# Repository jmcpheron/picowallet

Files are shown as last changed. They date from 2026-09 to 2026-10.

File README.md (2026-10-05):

# picowallet

A hardware wallet for one stablecoin, built from three off-the-shelf parts in an evening, no
soldering. It shows your balance in dollars. When a website asks it to send money, it puts the
amount and the recipient on its own screen and does nothing until you press the green button.

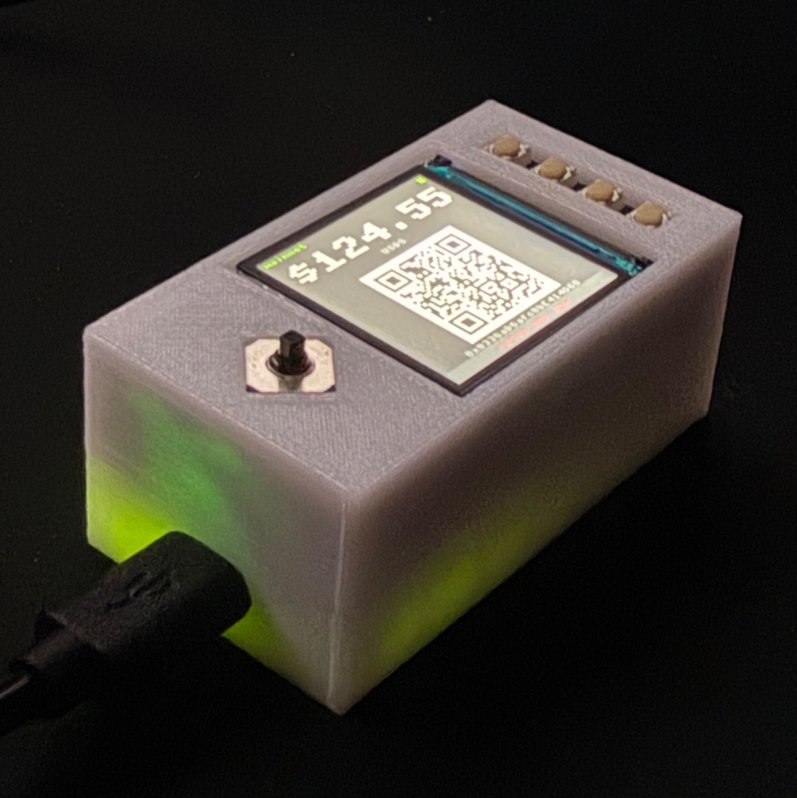
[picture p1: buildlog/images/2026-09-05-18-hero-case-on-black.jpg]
picowallet


The main flow is deliberately narrow: one token (USDS), one vault contract, one key that lives in
a secure element and never leaves it. An advanced hardware-signed call can recover other assets or
interact with contracts. Fork it, swap the token, redraw the screens, print a different case.

On 2026-09-05 it sent 69 USDS to atg.eth on Ethereum mainnet:
[`0x87638ae1…`](https://etherscan.io/tx/0x87638ae169eccb9f002d4eb6ce8b60e7d6603e4d3d4e562164ea10e9023f9313).

> **Security notice:** that historical deployment is legacy authorization v1 with a mutable signer.
> Do not fund or copy it. Current source is authorization v5; read [`SECURITY.md`](SECURITY.md) before use.

## Current contract

Authorization v5 is deployed on Ethereum mainnet at
[`0x4564fA634b073AcBcA814DCA5210835EC9376324`](https://etherscan.io/address/0x4564fA634b073AcBcA814DCA5210835EC9376324).

- No admin, upgrade, or unsigned spending path.
- Hardware-signed USDS transfers and arbitrary contract calls.
- ETH and accidental-token recovery through signed calls.
- Hardware-signed ENS reverse-name setup.
- Fixed recovery wallet with a 14-day signer-change delay. Any valid current-chip action cancels it.

**Audit:** [One Dollar Audit engagement 850](https://www.onedollaraudit.com/audit/850) reviewed this
exact deployment on 2026-09-06. [Full report](https://bafkreiha7yyl727uubma4shj2f5z5mlnezuya7wqg7yzqkjaqr443k4eg4.ipfs.community.bgipfs.com/):
3 high, 3 medium, 4 low, 3 informational. Its main warnings are known trade-offs: a compromised chip
can keep cancelling recovery, approvals can outlive signer recovery, and the fixed recovery wallet
is a single point of failure. This is a PoC, not an audit guarantee.

## How it works

```
website ──"send $5 to atg.eth"──▶ app (queue + relay, runs on your laptop)
                                     │  the wallet polls over WiFi
                                     ▼
                              picowallet
                              rebuilds the EIP-712 digest from the fields it shows you
                              screen:  SIGN  $5 USDS to atg.eth  REJECT
                              ATECC608 signs the digest (P-256), key never leaves the chip
                                     │  (r, s)
                                     ▼
                         relay pays gas ──▶ ChipAccount.executeTransfer ──▶ USDS.transfer
```

- The key is generated inside an **ATECC608** secure element and cannot be read out.
- On chain, a small vault contract (`ChipAccount`) holds the stablecoin and moves it only with a
  valid P-256 signature from the current hardware key, over a digest that
  includes recipient, amount, nonce, deadline, chain and contract. There is no admin or upgrade.
  A fixed recovery wallet can rotate the signer only after an uninterrupted 14-day delay.
- The wallet **rebuilds the digest itself** from the security-critical raw fields and refuses a
  mismatch. Names, symbols, and formatted values are untrusted display hints; production forks must
  pin the chain/vault/token and use authenticated transport as described in `SECURITY.md`.
- The relay just pays gas. It has no contract privilege and cannot replace the signer.
- Chip-signed general execution can recover accidental tokens/ETH and interact with contracts.
  The signature covers the exact target, ETH value, calldata, nonce, deadline, chain, and wallet.
  This is powerful: approve unknown calls only after decoding every field.

## 1. Order the parts

| part | ~price | link |
|---|---|---|
| Raspberry Pi Pico 2 W, **pre-soldered header** | $12 | Amazon `B0DRJXPPWL` (Freenove) or any Pico 2 W with headers |
| Waveshare Pico-LCD-1.3 (240×240 IPS, joystick, A/B/X/Y) | $15 | Amazon `B092VVCBQP` |
| Adafruit ATECC608 breakout, STEMMA QT | $6 | Adafruit 4314 |
| STEMMA QT / JST-SH 4-pin cable, any ends | $1 to $8 | Amazon `B08HQ1VSVL` (the kit we used, several ends), or single: Adafruit 4209 ($0.95, snip the pins off and strip) |
| micro-USB cable, data not charge-only | | |

About $35. No soldering iron.

Next hardware (in progress, needs soldering): the key moves into a plug-in McGuffin, with a bigger
screen, a dial and an 18650. See [`hardware/MCGUFFIN.md`](hardware/MCGUFFIN.md), and
[`hardware/BUILD1.md`](hardware/BUILD1.md) for the first build with a wiring diagram.

## 2. Print the case

`case/waveshare-13-pico-lcd-case-tomas-plass.stl`: both halves in one file, PLA, 0.2 mm layers,
no supports. Snaps together, micro-USB slot on the end, screen window, the four buttons and the
joystick poke through. Keycaps and a joystick dome are in `case/out/` (PLA, 0.12 mm layers).
`case/gen.py` regenerates them if your parts differ.

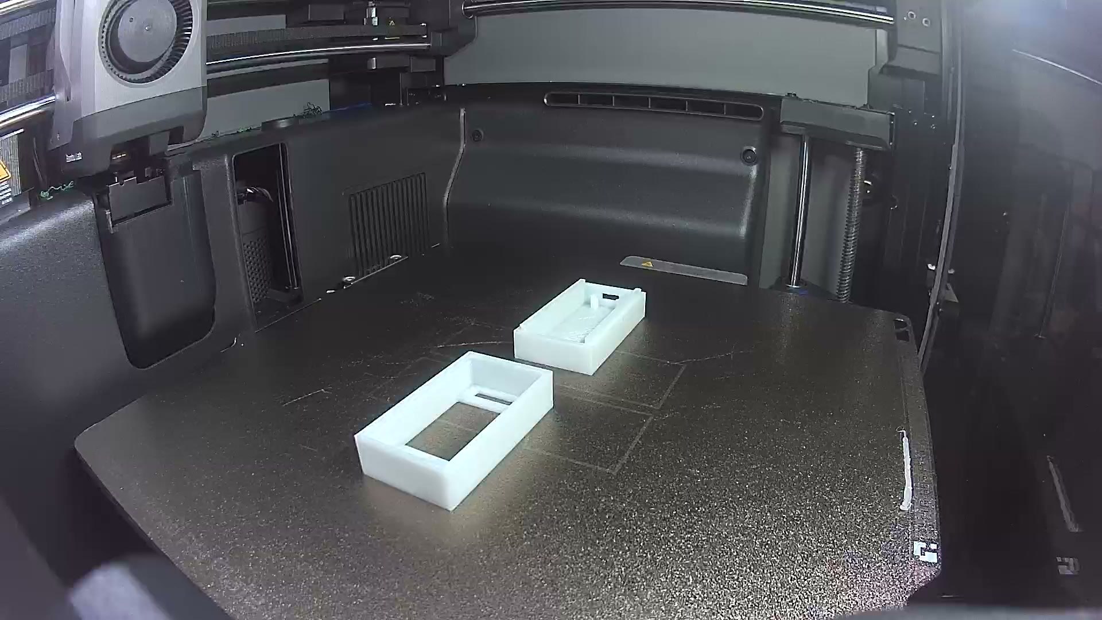
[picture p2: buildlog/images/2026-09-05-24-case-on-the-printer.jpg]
both halves on the printer


## 3. Put it together

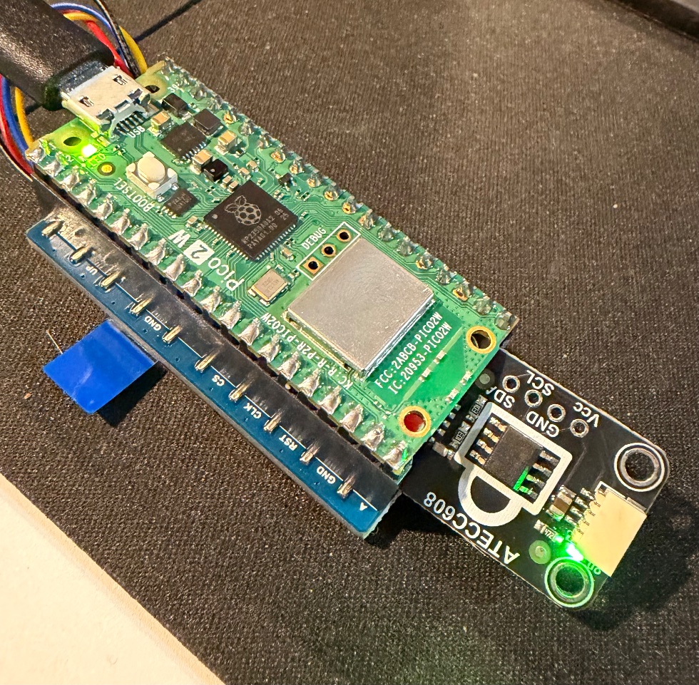
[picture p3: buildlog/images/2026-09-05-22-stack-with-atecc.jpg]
the stack: Pico on the LCD board, ATECC breakout in the gap


1. Plug the Pico into the LCD board's female header, component side toward the LCD, USB at the
   joystick end.
2. Plug the STEMMA QT cable into the ATECC breakout.
3. Push the cable's four bare wires into the LCD board's header socket **beside** the Pico pins.
   The spring contact grips both. Counting from the USB end, right side: red into 3V3 (pin 36),
   black into GND (pin 38). Left side: blue into GP4 (pin 6), yellow into GP5 (pin 7). Tug lightly.
4. Jam the breakout into the gap between the two boards, wires flat.

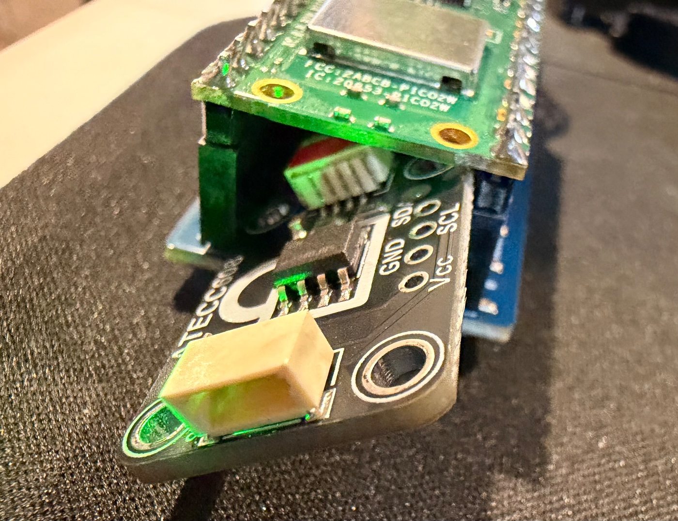
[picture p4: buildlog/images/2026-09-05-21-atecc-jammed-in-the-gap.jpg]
ATECC608 breakout jammed in the gap


`SOLDERING.md` has the pinout diagram and the soldered version if you want it permanent.

## 4. Flash the firmware

1. Hold BOOTSEL on the Pico, plug it into a computer, release. A drive named `RP2350` appears.
2. Drag [MicroPython for the Pico 2 W](https://micropython.org/download/RPI_PICO2_W/) (`.uf2`)
   onto it. The drive disappears and the board reboots.
3. On the computer: `uv tool install mpremote` (or `pip install mpremote`).
4. Copy `firmware/secrets.example.py` to `firmware/secrets.py`. Put in your WiFi and the app URL
   (step 6 gives you that, `http://<your-laptop-lan-ip>:3001`).
5. First time, over USB: `./tools/mpy` (needs `uv tool install mpy-cross==1.26.1.post2`), then
   `mpremote cp firmware/*.py firmware/*.mpy firmware/*.bin : + rm :splash.py + rm :lcd.py + rm :loader.py + reset`.
   That is the firmware plus the boot logo and loading bar; the three bootloader modules go as
   pre-compiled `.mpy` (a `.py` of the same name on the board would be used instead).

The passwordless WiFi console is disabled by default because it grants full control of the signer.
For isolated development only, set `ENABLE_NETWORK_CONSOLE = True`; then `./tools/push` deploys
firmware over the air and `./tools/pico` opens the console. Disable it before holding real value.

The screen comes up, finds the chip on the bus, and shows "no key" until step 5.

## 5. Set up the chip (once)

A fresh ATECC608 refuses to make a key until its config zone is locked, once, permanently. **Before
locking any chip run `python3 tools/check_config`** (proves the firmware's config table is the one on
the working chip) and know that the firmware reads the chip back and refuses to lock on any
mismatch; a chip was lost on 2026-09-15 before those checks existed (`buildlog/2026-09-15-config-table-bug.md`). This
is normal; every chip in use is locked. Generate the final key before deploying the contract:

1. In `firmware/secrets.py` temporarily set `ALLOW_LOCK = True` and `ALLOW_GENKEY = True`.
2. Over USB, lock the config zone and generate the key. Record the public `qx` and `qy` values.
3. Set both flags back to `False`, leave `ENABLE_NETWORK_CONSOLE = False`, and flash again.
4. Put `qx` and `qy` in `app/packages/foundry/.env`, set a fixed `RECOVERY_ADDRESS`, and deploy.
   Losing the chip starts the documented 14-day recovery process.

`reference/pi/README.md` shows the equivalent provisioning flow from a Raspberry Pi with real output.

## 6. Run the app

`app/` is a Scaffold-ETH 2 project: the vault contract, a Next.js site, and the queue and relay as
route handlers. Locally, with play money:

```sh
cd app && yarn install
yarn chain                                  # anvil, a local chain
yarn deploy                                 # requires CHIP_PUBKEY_X/Y in packages/foundry/.env
yarn workspace @se-2/nextjs dev -p 3001     # http://localhost:3001
```

The wallet announces its key to the app. `/setup` verifies that it matches the current on-chain
key. The screen shows the vault balance and a QR of the vault address. Type a recipient and an
amount on the Send page. The wallet turns green. Press A. Watch it settle.

Mainnet, with real money, in `app/packages/nextjs/.env.local`:

```
NEXT_PUBLIC_TARGET_NETWORK=mainnet
NEXT_PUBLIC_ALCHEMY_API_KEY=<a restricted project-specific key>
RELAYER_KEYSTORE=<a foundry keystore name>          # an account with a little ETH for gas
RELAYER_KEYSTORE_PASSWORD_FILE=/path/to/password.txt
USDS_ADDRESS=0xdC035D45d973E3EC169d2276DDab16f1e407384F
```

Deploy your own vault with the chip's public key baked in (the Setup page shows it):

```sh
# app/packages/foundry/.env: CHIP_PUBKEY_X/Y=0x… USDS_ADDRESS=0x… ENS_REVERSE_REGISTRAR=0x…
cd app && yarn deploy --network mainnet --keystore <name>
```

Send USDS to the vault address it prints. Scan the QR on the wallet to get that address into
your phone wallet. Each transfer costs the relay about 82k gas.

For ENS, first create a subname such as `hard.atg.eth` and make its ETH record point to the vault.
Then use **Set the vault ENS name** in the app and approve the exact name on the device. This sets
reverse/primary resolution only; it does not create the subname.

Recovery uses the fixed `RECOVERY_ADDRESS` chosen at deployment. That wallet proposes a new P-256
key, waits 14 days, then finalizes. Any successful current-chip action cancels the proposal; the app
also has **Cancel on Pico**. Monitor `RecoveryStarted` events. See `SECURITY.md` before funding.

## The screens

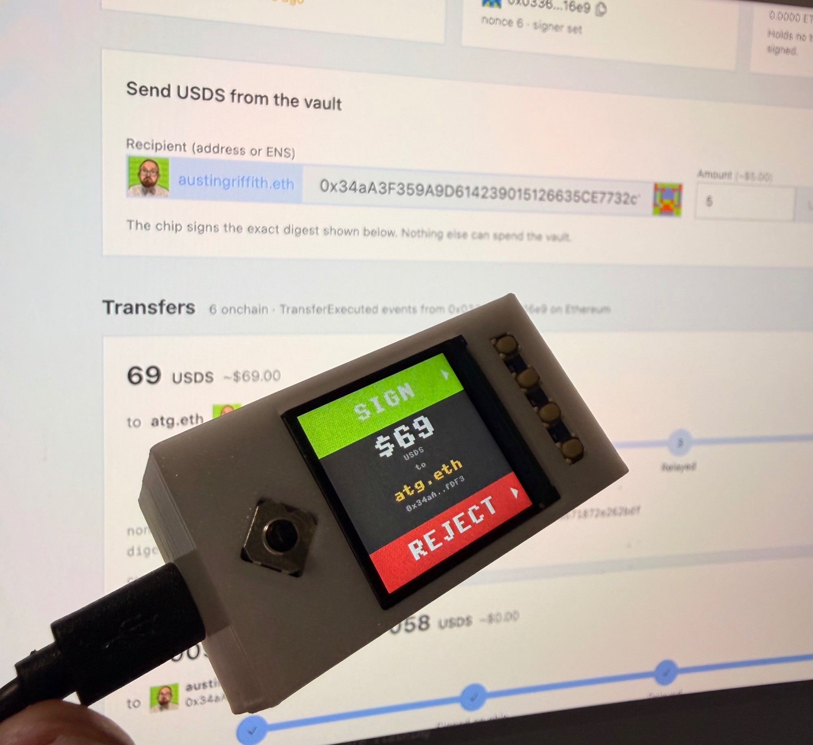
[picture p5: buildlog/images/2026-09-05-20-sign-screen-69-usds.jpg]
SIGN? $69 USDS to atg.eth, green bar at A, red bar at Y


**Home:** balance in dollars, a QR of the vault to deposit into, chain label top-left so test money
and real money never look alike, pairing dot top-right, a warning line along the bottom (relay
gas low, unpaired, app unreachable). Refreshes every 12 s and flashes the delta when money moves.

**Sign:** green SIGN bar in line with the A button, red REJECT bar in line with Y. Amount,
recipient name and address between them. Joystick down shows nonce, deadline, chain, vault and the
digest the device computed.

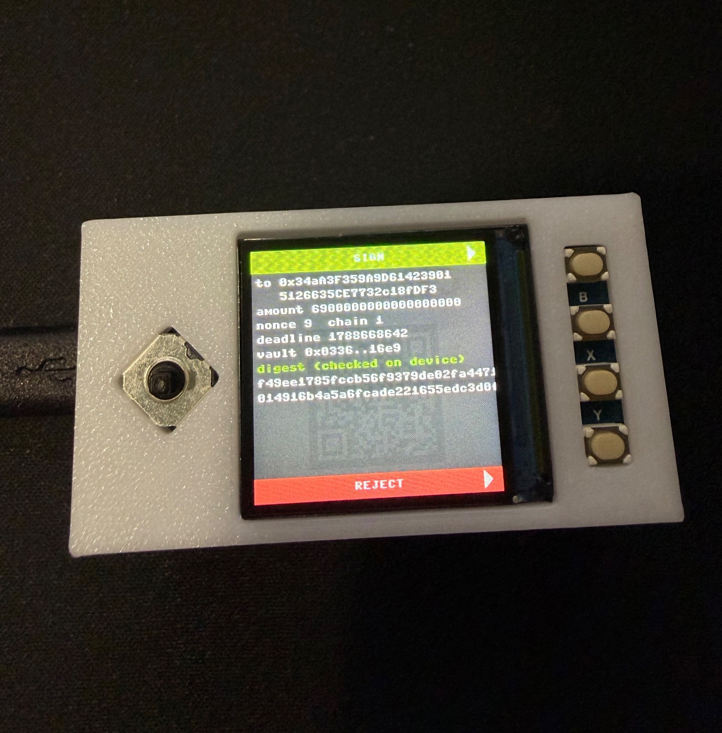
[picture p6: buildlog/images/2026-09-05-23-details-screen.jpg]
details page: full address, amount in base units, nonce, deadline, vault, digest


## Change it

- **Another token:** set `USDS_ADDRESS` before deploying. The token address is immutable, so changing
  assets requires a new vault.
- **Another chain:** `targetNetworks` in `app/packages/nextjs/scaffold.config.ts`. The wallet
  shows the chain id it is told and bakes it into the digest.
- **The screens:** `firmware/wallet.py`, functions `draw_home` and `draw_confirm`. 240×240,
  framebuf, an 8×8 font scaled up. Try it on the virtual wallet first: `tools/emu` opens
  http://localhost:4242 with the same MicroPython running the same files, the case in 3D and
  the keyboard on the buttons (W A S D, space, numpad 9 6 3 .); `tools/emu run NAME`, `key A`, `shot` drive it from a terminal
  (`emu/README.md`). To have an AI write for it, give it `emu/SKILL.md` and this repo; in Claude
  Code it is the `/pico-emu` skill. Then `./tools/push` and look.
- **The case:** `case/gen.py`, CadQuery, every dimension is a named number at the top.
- **The contract:** `app/packages/foundry/contracts/ChipAccount.sol`, with 34 tests.

## What is where

| path | what |
|---|---|
| `firmware/` | MicroPython for the Pico: `wallet.py` loop and screens (WiFi), `usbwallet.py` (USB, no radio, see `USB.md`), `atecc.py` chip driver, `signer.py`, `eip712.py` + `keccak.py` + `p256.py` pure-Python crypto, `blockies.py`, `lcd.py`, `net.py` |
| `app/` | contracts, tests, site, relay |
| `case/` | STLs, the generator, the measurements |
| `emu/` | the virtual wallet: MicroPython in WebAssembly, `machine` shims, the case STLs in 3D, a CLI for bots |
| `tools/` | `pico` console, `push` firmware, `qr` (QR of the vault for the screen), `emu` (the virtual wallet) |
| `buildlog/` | dated notes and photos of what actually happened, including the mistakes |
| `reference/` | the Pi signer this grew out of, with the fresh-chip guide; SeedSigner cap parts (MIT) |
| `PLAN.md`, `SOLDERING.md`, `USB.md` | the plan, the wiring guide, and the wallet over USB (air-gapped, no radio) |

## Trust model, short

The current chip key is the only thing that can spend the vault. The delayed recovery wallet can
replace that key but cannot spend directly. The relay only pays gas. The app
has no auth, so anyone who can reach it can queue deceptive requests or cause denial of service;
keep it on a trusted network for this PoC. The passwordless development console must stay disabled
when holding value. Read [`SECURITY.md`](SECURITY.md) before funding a deployment or publishing the
app to the internet.

## Credits

Grew out of [ATECC608-demo](https://github.com/clawdbotatg/ATECC608-demo) (a Pi doing the same
job). Case v0 by [Tomáš Plass](https://www.printables.com/model/1322102-waveshare-pico-13-lcd-case),
CC BY-NC. Cap and joystick geometry learned from the
[SeedSigner](https://github.com/SeedSigner/seedsigner) enclosures, MIT. App scaffold by
[Scaffold-ETH 2](https://scaffoldeth.io).

## License

MIT for everything here except where noted: the v0 case STL is Tomáš Plass's, CC BY-NC 4.0;
the SeedSigner parts in `reference/seedsigner/` are MIT with their own copyright; `app/` carries
Scaffold-ETH 2's MIT license.

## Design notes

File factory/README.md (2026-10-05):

# Factory test

Run `tools/factory`, open http://localhost:4343 in Chrome or Edge, plug in a finished wallet, press
Connect (first board only; after that it starts by itself on plug-in).

It checks, in order:
1. Board: Pico 2 W / Pico W / RP2040 clone, board ID, WiFi, RAM, whether the wallet firmware is on it.
2. Secure chip on GP4/GP5: ATECC608 (serial, lock state) or OPTIGA Trust M (UID). If none answers it
   says which wires to check.
3. Screen: red, green, blue; you confirm each on the page.
4. Buttons: press all nine; each turns green on the page and on the wallet.

Needs only MicroPython on the board: `probe.py` is pasted into the raw REPL, nothing is written
to flash. At the end the board soft-resets and the wallet starts again. Results stay in this
browser's list; "Download CSV" exports them.

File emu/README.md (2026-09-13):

# emu: the virtual Pico wallet

Real MicroPython (the WebAssembly build of 1.26, the board runs 1.26.1) running the firmware in
`firmware/` unchanged, with the `machine`/`network`/`requests` modules replaced by shims that talk
to the page. The screen is captured from the ST7789 SPI stream, so what you see is the exact
framebuffer. The device is drawn in 3D from the case STLs in `case/zez0000/`.

```
tools/emu                 # start the server, open http://localhost:4242
tools/emu run hello       # reboot + import emu/sketches/hello.py
tools/emu key A           # press a button (A B X Y up down left right press), key right:300 holds
tools/emu shot            # emu/shots/latest.png
tools/emu exec 'mock.goto("send")'
tools/emu log             # console lines
tools/emu devices         # boards on USB (serial ports, bootloader drives)
tools/emu ship hello      # copy hello.py (+ imports) to the Pico on USB and run it (--port /dev/cu.usbmodemN, --boot: run at power-up too)
tools/emu flash --port /dev/cu.usbmodemN [--wifi]   # MicroPython onto any board (also works on a BOOTSEL drive without --port)
tools/emu headless mock --wait 300 --key right --shot emu/shots/x.png    # no browser
```

Page: the device menu lists every board on USB; for one that is not running MicroPython the
send button becomes ⚡ install MicroPython. The module menu top left picks what ▶ run, ↻ reset and
⇪ send to Pico act on (only modules
that show something are listed: they start themselves at import, or the server knows their entry
point, `ENTRY` in `core/workspace.mjs`). Left = files, editor (Cmd/Ctrl+Enter runs the open file),
console with a REPL; right = the device (orbit with the mouse, click the caps) or the flat view.
Keyboard: W A S D and space for the joystick, numpad 9 6 3 . for A B X Y (top-row 9 6 3 . work
too), after clicking the device. The 3D view labels each button with its key.

The flash is `firmware/*.py` and `*.bin` (never `secrets.py`; a stub is generated with
`APP_URL = "/app"`, which the server proxies to the wallet app, `--app http://host:port`,
default `http://localhost:3001`) plus `emu/sketches/*` on top. Saving in the editor writes to disk.

## Give it to your AI

`emu/SKILL.md` is the skill file. It tells an AI what the screen and buttons are, how to write a
sketch, how to run it here (`tools/emu run`, `key`, `shot`), and how to put it on the real Pico.
Hand it over with a checkout of this repo (the skill runs `tools/emu`, which needs node). In
Claude Code it loads on its own from `.claude/skills/pico-emu`; say "build Tetris for the Pico
wallet" or `/pico-emu`. The page links to it too (top right, "skill file for your AI", also at
http://localhost:4242/skill).

What is modeled: pins (keys pull low when pressed), SPI display window commands, the SPI transfer
time (24 MHz cap until `machine.freq(cpu, peri)` raises the peripheral clock, like rp2), PWM
backlight, `Pin("LED")` (the base glows), `Timer` periodic/one-shot, `Pin.irq`, `machine.reset()`,
a 448 KB heap. Not modeled: I2C (the ATECC608 is absent, the software signer is used), sockets,
PIO, native/viper code generation (runs as bytecode), real timing of Python itself (wasm is much
faster than the RP2350).

Needs node 18+ and `npm install` in `emu/` (done by `tools/emu` on first run). No build step.

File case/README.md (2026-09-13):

# Case

## v0: print this first

`waveshare-13-pico-lcd-case-tomas-plass.stl`, from
[Waveshare Pico 1.3 LCD Case by Tomáš Plass](https://www.printables.com/model/1322102-waveshare-pico-13-lcd-case)
on Printables. License CC BY-NC 4.0 (remix ok, attribution required, no commercial use).

What it is: a two-piece snap-fit box for exactly our stack, Pico plugged into the Pico-LCD-1.3.
Both halves are in the one STL, side by side. Closed box about 60 x 34 x 26 mm.

- Lid: screen window, a slot the four bare A/B/X/Y buttons poke through, a diamond hole the
  joystick stem pokes through. No caps, you press the parts directly. That is the honest state of
  the art for this board: nobody has published floating caps for it.
- End: micro-USB slot (the Pico 2 W is micro-USB, not USB-C).
- Base: four M2 posts for the Pico, optional.
- Print: 0.2 mm layers, no supports (author says a small one under the USB cutout is optional).

Fit risk for us: the ATECC breakout and the four wedged wires live in the 11 mm gap between the
boards, inside the box footprint, so they should be fine. The wires leave the header at the USB end
and bend into the gap; keep them flat. Print it and see.

## v1: our own

Generate from Python (like the CELL parts) so it re-fits when parts change. Wants:
- floating caps for A/B/X/Y and a joystick hat, captured by the lid
- pocket for the ATECC breakout and a 502030 LiPo + charger
- USB cutout, maybe a lanyard hole

Board facts for that: Pico-LCD-1.3 is 52.0 x 26.5 mm, display 23.4 x 23.4 mm active. Waveshare
wiki: https://www.waveshare.com/wiki/Pico-LCD-1.3. A CAD model of the board exists on GrabCAD:
https://grabcad.com/library/waveshare-1-3-inch-lcd-for-pico-65k-240x240-1. Button and joystick
centers still need measuring with calipers.

Print inbox drop 2026-09-05: `20260905-193939-waveshare-13-pico-lcd-case-tomas-plass` (PLA, black, 0.20 mm).

## Buttons and joystick: research (2026-09-05)

Nobody has published caps for the Pico-LCD-1.3. But its Pi HAT twin (Waveshare 1.3inch LCD HAT,
same 240x240 panel, same 5-way joystick, same tact switches, 3 buttons instead of 4) is the
SeedSigner bitcoin wallet's screen, and that project has years of open enclosures with printed caps:

- SeedSigner enclosures, MIT: https://github.com/SeedSigner/seedsigner/tree/dev/enclosures
  Copies of the parts that matter are in `reference/seedsigner/`:
  - `orange_pill_button.stl` 11.7 x 4.7 x 4.8 mm, `orange_pill_joystick.stl` 13 x 13 x 10 mm.
    Author says the thumbstick is clumsy and wants resin.
  - `open_pill_mini_w_coverplate_Buttons.stl` (three caps on a sprue, 20 mm tall), `Thumbstick_PLA`
    and `Thumbstick_TPU` (11.8 x 11.8 x 5.6 mm). FDM-only, TPU for the controls, no hardware.
- revetuzo's Open Pill caps, CC BY-SA: https://www.printables.com/model/179924
  Sticks and pads in 12/14/15 mm with a 2.05 mm square socket, "fits the 2 mm stick on the
  Waveshare HAT". Plus a glue-on button.
- Crackedconsole's HAT case with 3 buttons + joystick cap v2, Sketchup source:
  https://www.thingiverse.com/thing:3334127. Note: 0.1 mm more clearance per button was too loose.
- Adafruit 4697 rubber nubbin cap, $0.50, fits the classic 5-way nav stem. Zero-effort option.
- The joystick family: ALPS SKQU (10 mm square, 4-way + center push). Datasheet: SMD center-push
  type is 8.6 mm tall overall, stem 3.2 mm square, 2.8 mm above the housing, travel 0.4 mm tilt /
  0.2 mm push, 1.57 N tilt / 3.14 N push. Waveshare's part is a clone; SeedSigner people measure
  the stem at 2 mm square, so measure ours.
- General cap design: https://www.printables.com/model/236991 (tact cap with assembly template),
  https://www.thingiverse.com/thing:1557650, Apple's button patents. Same idea every time.

## How we will do it

Caps are loose parts trapped between the lid and the board. Nothing glued, nothing on the board.

```
        cap top (visible, any color)          ___
   lid  ======|   |======   <- hole in lid   |   |  lid hole = cap body + 0.25 mm/side
   flange  ___|   |___      <- wider than    |___|  flange 1.0 mm out, 1.0 mm thick
   post       |___|         the hole         | | |  post lands on the tact plunger
   board  ----[tact]----
```

- A/B/X/Y caps: round or square top 6 mm, flange 8 mm, post the size of the plunger. Cap body
  height = lid thickness + stand-off so the flange sits 0.3 mm above the plunger at rest, and
  bottoms on the lid underside just after the click (over-travel stop).
- Joystick hat: a 12 mm dome with a square socket that press-fits the stem (start at stem + 0.05 mm,
  like revetuzo's 2.05 mm), flange under a 13 mm lid hole so it can tilt 0.4 mm each way. A ring on
  the lid underside keeps it from lifting off. TPU hat is the comfy version.
- Lid holes get a 0.5 mm skirt under them so caps can't rock.
- Print caps top-face down on a textured plate for a clean face. Any color per cap.
- Generator: Python (CadQuery or OpenSCAD), parameters = the caliper numbers below.

Numbers we need from calipers, with the stack assembled:
1. Tact switch: plunger diameter, plunger height above the LCD PCB, switch body size (6x6?).
2. Joystick: stem width (square?), stem height above the metal housing, housing size, housing height
   above the PCB.
3. Height from LCD PCB top to the top of the screen glass.
4. Centers (x, y in mm): joystick + 4 buttons, measured from the PCB corner at the USB end
   (or a straight-down photo with a ruler in it).
5. The v0 case lid thickness at the button slot, once printed.

## Measurements (2026-09-05, v0 case on the bench)

From the v0 lid STL (the author's cutouts fit the board, photo in the build log), so these are
positions we can trust. Case outer 57 x 31 x 26 mm, lid plate 2.0 mm thick. Board center = case
center. x runs along the long side, + toward the buttons, 0 at the board center; y across, 0 on
the centerline.

| feature | in the lid | relative to board center |
|---|---|---|
| screen window | 30 x 27 mm | center x +2.0 |
| button slot | 4.5 x 21 mm | column at x +22.25, buttons at y ≈ -7.75, -2.6, +2.6, +7.75 (pitch ≈ 5.17) |
| joystick hole | 10 x 10 mm diamond (7.1 mm square rotated 45°) | center x -19.5 |

Calipers (Austin): 30.94 = case base width; 4.55 = tact switch body (4.5 mm square); 5.15 and
4.18 and 2.04 = see BUTTONS.md, being confirmed.

## Zez0000 case with caps (2026-09-08)

`case/zez0000/`: [Raspberry Pi Pico 2 Case - Waveshare 1.3" LCD by Zez0000](https://makerworld.com/en/models/3230142-raspberry-pi-pico-2-case-waveshare-1-3-lcd),
CC BY-NC, released 2026-08-28. A remix of the v0 case with 4 button caps and a joystick cap
already modeled: same base, rounded corners, square lid holes. Found while looking for a case
with the buttons and joystick covered. Parts: base 57x31x13, lid 57x31x15.6, button caps
6.3x5.5x4.4 (x4), joystick cap 8.2 round x4.1. Author settings: PLA, 0.20 mm, 2 walls, 15%
infill, no supports, about 40 min, caps on their own plate for a second color.
Print inbox drops `20260908-224447-*` and `20260908-224448-*`. Untested by us.

### base_v2 (2026-09-09): the stock base would not snap in

Austin printed the set; lid and base would not click together even with force. Measured on the
STLs: each base tab (53 x 2 mm, 2 mm above the rim) carries a full-length half-round ridge, r 0.5,
0.44 mm proud of the lid's inner wall, with zero end clearance. The lid has a matching r 0.5
groove centred 1.5 mm inside its mouth. That is 0.44 mm of interference along 106 mm at once.
`tools/zezbase` builds `case/zez0000/base_v3.stl`: ridge removed, tab face shaved to 0.1 mm
clearance, tab ends 0.25 mm clearance, then four 10 mm ridges (r 0.4, 0.25 mm proud) at
x = +-16 on each side, same height as the stock ridge so they land in the lid groove. Base only;
the stock lid and caps stay. v3 adds an 8 x 1 x 1 mm pry notch in the outer wall at the rim, +y side, x centre. Print inbox drop `20260909-*-base_v3`; full set in yellow PLA requested.

### base_v4 (2026-09-10): shorter posts, shorter case

The four Pico posts were 5.5 mm tall (floor z 2 to 7.5); Austin wants 3 mm, just enough to keep
BOOTSEL and the underside parts off the floor. `tools/zezbase` now also removes a 2.5 mm slab of
wall and post right above the floor and drops everything above it, so the USB slot, tabs, ridges
and pry notch keep their positions relative to the Pico. Output `case/zez0000/base_v4.stl`,
57 x 31 x 10.5 mm (was 13). Lid and caps unchanged. Print inbox drop `20260910-163347-base_v4`,
PLA fit check, base only. Knobs: `POST_H` (3.0) in `tools/zezbase`; `DROP` follows from it.

### joystick_cap_v2 (2026-09-10): looser stem socket

The stock cap's square stem socket is 1.95 mm for the 1.87 mm stem (Austin's calipers) and would
not push on. `tools/zezcap` opens it to 2.05 mm (`SOCKET`), same 1.8 mm depth, nothing else
changed. Output `case/zez0000/joystick_cap_v2.stl`. Print inbox drop `20260910-181311-joystick_cap_v2`,
on the PLA fit-check plate with base_v4.

### joystick_cap_v3 (2026-09-10): the v2 socket printed shut

The v2 cap came off the printer with the socket mouth squished and a sagged line across the
hole. Cause: the flange prints face down, so the 2 mm hole is in the squished first layer, and
its flat ceiling is a 2 mm bridge. `tools/zezcap` now cuts a 0.4 mm 45 degree chamfer at the
mouth (2.85 mm at the face) and a pyramid roof instead of the flat ceiling, and builds two
sizes: `joystick_cap_v3_2.05.stl` and `joystick_cap_v3_2.15.stl`. Both dropped for a slow PLA
print; keep whichever grips the 1.87 mm stem.

### Smaller joystick sockets and an X button (2026-09-10, later)

The v3 caps printed clean but the socket was loose on the stem. `tools/zezcap 1.95 2.00` builds
`joystick_cap_v3_1.95.stl` and `joystick_cap_v3_2.00.stl`, same chamfer and roof. `tools/zezbtn`
builds `button_cap_x.stl`: the stock (solid) button cap with a raised X on top, 0.7 mm bars at
45 degrees, 0.6 mm above the dome, for a cancel button. All three dropped for PLA, flange down.
`tools/zezbtn check` builds `button_cap_check.stl`, the confirm button, same raised bars in a
check mark. Later plan: print the symbols in a second color (green check, red X) on the AMS.
Result 2026-09-10 evening: socket 2.00 mm is the winner on the 1.87 mm stem. 10 copies queued.

### lid_v2 (2026-09-10): button holes moved

On the printed lid the four button holes sit 0.6 mm too far from the screen (the switch plunger
is off-centre in each hole) and are a hair tight on the caps. `tools/zezlid` fills the stock
holes, then cuts them 0.6 mm toward the screen (`SHIFT_X`) and 0.05 mm bigger per side (`GROW`).
Inside recess untouched. Output `case/zez0000/lid_v2.stl`. Queued with a base_v4 reprint as a
full case.

### lid_v3 (2026-09-10): button holes 0.3 mm bigger per side

lid_v2 printed with the holes lined up but tight, with print bumps catching the caps. The print
Claude opened the holes 0.3 mm per side directly on its copy of the v2 mesh (`lid_v2_holes_p06.stl`
on the Mac mini) and printed it in PETG. `tools/zezlid v3` makes the same part from source:
GROW 0.35 instead of 0.05, holes 5.20 x 4.45 mm on the same centres, x -24.25..-19.05. Output
`case/zez0000/lid_v3.stl`. Cap body is 4.30 x 3.56, so about 0.45 mm clearance per side.

### lid_v4 (2026-09-11): button holes halfway between v2 and v3

v3 (0.3 mm extra per side) was too loose. `tools/zezlid v4` uses GROW 0.20, holes 4.90 x 4.15 mm,
same centres. About 0.30 mm clearance per side on the 4.30 x 3.56 cap. Output `case/zez0000/lid_v4.stl`. Print inbox drop `20260911-100848-lid_v4`, PETG, print Claude told to go.

### base_v5 (2026-09-11): stiffer snap

base_v4 snaps and holds but pries apart with a fingernail. `tools/zezbase v5` raises the four ridges
from 0.25 to 0.50 mm proud (Austin: a quarter mm more) and fattens them from r 0.4 to r 0.5 so the
neck on the tab stays about 1 mm wide. Everything else is v4. Output `case/zez0000/base_v5.stl`. Print inbox drop `20260911-181009-base_v5`, black PETG, print Claude told to go 2026-09-11.
Unprinted. Note 0.50 is above the stock 0.44 that would not snap at all, but stock had 106 mm of
ridge and this has 40 mm. If v5 will not close, try 0.40.

### base_v5_qr (2026-09-11): white QR code in the bottom, AMS two-colour test

Austin's idea: the base prints bottom-down in black PETG, so put white PETG in the first layers to
make a QR code on the underside. `tools/zezqr [TEXT] [base_vN]` (default the repo URL, base_v5)
builds the QR with `qrcode` (EC L, 29 modules for the URL; a 0x address at M is also 29), lays it
on the bottom at 0.85 mm a module (24.7 mm square, centred at x -3.5 to clear the 3 x 2.3 mm hole
in the floor at x 12..15), mirrored so it reads from below, and cuts it 0.6 mm (three 0.2 mm layers)
into the 2.0 mm floor. Dark modules are white PETG; the black base is the light modules and the
quiet zone (an inverted QR, phones read those). Outputs, all in the base frame with z=0 on the bed:
`base_v5_qr_black.stl`, `base_v5_qr_white.stl` (431 loose squares, never print alone), and
`base_v5_qr.3mf`, a Bambu Studio project with both as parts of one object, white part on
extruder 2. The script checks itself: it samples the white body from below and matches it module
for module against the QR matrix, then decodes it with OpenCV.

Bambu Studio 2.7 CLI notes, since the print Claude slices headless: the 3MF needs a
`Metadata/project_settings.config` or the CLI segfaults on load (ours is
`case/zez0000/p2s_petg_x2.project_settings.json`, a P2S 0.4 / 0.20 mm / PETG HF x2 export with
`filament_colour`, `filament_map`, 2x2 `flush_volumes_matrix`, textured PEI plate); the plate
block needs `filament_maps` "1 1"; and `--load-settings`/`--load-filaments` must be given presets
with `inherits` already resolved (flatten the JSON chain) or every part ends up on filament 1.
With that it sliced to 3 filament changes, white 0.2 g, and the white toolpaths in the gcode
decode as the URL. Print inbox drops `20260911-142041-base_v5_qr` (3MF), `-142042-…_black` and
`-142043-…_white` (STL fallback). Unprinted. Knobs: `MOD`, `QR_H`, `CX`, `EC` in `tools/zezqr`.
Result 2026-09-11: printed on the AMS, the QR came out and scans. Proof done; parked. One day the
vault address goes in the bottom (`tools/zezqr 0x... base_vN`), not now.

### base_v5 result (2026-09-12): too tight, v4 is the keeper

base_v5 printed but does not fit well. base_v4 (ridges 0.25 mm proud) is the winning base. Reprint
requested plain, no QR: print inbox drop `20260912-100725-base_v4`, black PETG.

## Official set (2026-09-12, evening)

The case as it stands. Print these, nothing else, unless Austin says otherwise. One-file version
with all seven parts laid out in print orientation: `case/zez0000/picowallet_case.stl`, built by
`tools/zezplate`. Black PETG, 0.20 mm, no brim. Base floor down, lid outer face down, caps flange down.

| Part | File | Why |
|---|---|---|
| Base, Pico 2 W (micro-USB) | `case/zez0000/base_v6.stl` | ridges 0.30 mm proud; v4 (0.25) pulled apart by hand, v5 (0.50) would not fit |
| Base, pink Pico (USB-C) | `case/zez0000/base_pink.stl` | base_v6 with the USB-end posts spread, a divot under the jack, wider slot. Fits perfectly (2026-09-12) |
| Lid | `case/zez0000/lid_v5.stl` | v4 holes plus a 0.4 mm deeper cap pocket, so pressing the case no longer clicks buttons |
| Button caps | `button_cap_1..4.stl` (or `button_cap_x` / `button_cap_check`) | stock |
| Joystick cap | `joystick_cap_v3_2.00.stl` | 2.00 socket fits the 1.87 stem |

There is no lid v6 or base v7. The QR-bottom base is a parked side experiment.

### base_v6 (2026-09-12): a fifth of the way from v4 to v5

v4 holds but can be pulled apart by hand; v5 (0.50 proud) would not fit. `tools/zezbase v6` is v4
with the ridges 0.30 mm proud instead of 0.25, same r 0.4, same notch. Output
`case/zez0000/base_v6.stl`. Print inbox drop `20260912-145004-base_v6`, black PETG, no brim (Austin: never brim these parts again). If it is still loose, 0.35 next; if tight, v4 stays official.

### lid_v5 (2026-09-12): 0.4 mm more cap clearance

Pressing on the button side of the case clicks one or two buttons: the cap flange sits against the
pocket ceiling with almost no gap to the switch plunger. `tools/zezlid v5` is lid_v4 with the
cap-flange pocket inside (x -26.5..-18, y +-12.5) cut 0.4 mm deeper, so the plate over the button
strip is 1.6 mm instead of 2.0 and the caps sit 0.4 mm further out. Outer face unchanged, still
prints face down. Holes unchanged from v4. Output `case/zez0000/lid_v5.stl`. Print inbox drop `20260912-175600-lid_v5`, black PETG, no brim.
Alternative if this is not enough: a 0.4 mm dimple in the cap underside where the plunger lands.

### base_pink (2026-09-12, night): base_v6 for the USB-C (pink) Pico

The pink Pico has a USB-C jack: 8.89 wide, 3.15 tall (micro-USB is ~7.5 x 2.7). On base_v6 the
two posts at the USB end are 8.0 mm apart face to face and the wall slot is 8 x 3 with its floor
0.5 above the case floor, so the jack hits both. base_pink is base_v6 plus:

- USB-end posts moved out 0.75 mm each: gap 8.0 -> 9.5 mm. Other end unchanged.
- 0.6 mm divot in the floor under the jack, 9.1 wide x 7.4 in from the wall. 1.4 mm floor left.
- Wall slot 9.2 wide, floor dropped to the divot floor (z 1.4..5.5).

`tools/zezbase pink`. Drop 20260912-204053-base_pink, black PETG, no brim. Lid and caps unchanged.
Printed and fits perfectly. Official: base_v6 for a Pico 2 W, base_pink for the pink USB-C Pico.

### lid_v6 (2026-09-12, night): pocket 0.6 mm

With the pink Pico in base_pink, pressing the case still clicked the buttons a little on lid_v5.
Same fix, more of it: cap pocket 0.6 mm deep instead of 0.4, so the plate over the buttons is
1.4 mm. Holes unchanged from v4/v5. `tools/zezlid v6`, drop `20260912-213327-lid_v6`, black PETG, no brim.
Not official until it is tried.

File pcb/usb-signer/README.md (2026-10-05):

# usb-signer v0.3 — ATECC608B on a USB-C stick (2026-09-24)

Full design report with every decision and risk: `REPORT.md`.

Plug it into a laptop. The computer talks I2C to the secure element through an MCP2221A bridge. No
firmware on the stick; the host does everything. Same chip, same key handling as picowallet, minus the
screen and buttons.

```
laptop USB-C  ──►  MCP2221A (USB→I2C)  ──I2C──►  ATECC608B
```

## Board
- 30 × 12 mm, **0.8 mm thick** (the plug needs it), 2 layers. Left 13 mm is the plug tongue. Chips on the front, passives and lights on the back.
- Everything runs on the 5 V from USB. MCP2221A and ATECC608B both take 3–5.5 V, so no regulator.
- Zero soldering: every part is an LCSC part JLCPCB places. Design: `index.circuit.tsx`, fab files: `fab.zip`.

| Ref | Part | LCSC | Note |
|---|---|---|---|
| J1 | USB-C male plug, clamping type, 24P | C3151751 | 36k stock, $0.14. "Standard PCBA only, assembly difficulty high" per JLCPCB → a fixture fee. Board must be 0.8 mm |
| U1 | MCP2221A-I/ST, TSSOP-14 | C130462 | USB→I2C bridge, appears as a HID device |
| U2 | ATECC608B-SSHDA-T, SOIC-8 | C1518769 | the secure element |
| R1 | 5.1k | | CC pulldown: tells the host we're a device |
| R2 | 10k | | MCP2221A reset pull-up |
| R3, R4 | 4.7k | | I2C pull-ups |
| C1 | 470 nF | | MCP2221A VUSB cap (datasheet), on the back under the chip |
| C2, C3 | 100 nF | | decoupling |
| LED1 green + R5 1k | | | power |
| LED2 blue + R6 1k | | | I2C activity, from MCP2221A GP3 (its default is the I2C LED function) |

Only the plug's **bottom row** is wired. This 24-pin plug carries both rows, and a USB-C receptacle
shorts A/B for VBUS, GND, D+, D− and reads CC on either side, so one row works in both orientations.
The top row's 0.5 mm-pitch pads would not autoroute.

## Talking to it
- macOS/Linux/Windows see the MCP2221A as USB HID, no driver.
- Python: `pip install EasyMCP2221` (or `PyMCP2221A`) gives `i2c_read/i2c_write`. ATECC608 address 0x60 (0xC0 8-bit).
- Microchip's cryptoauthlib has an MCP2221A HAL. Our own `firmware/atecc.py` wire protocol ports to the host in an afternoon.
- Ethereum: ATECC608B signs P-256, not secp256k1. Same story as picowallet: the on-chain side verifies P-256 (the ChipAccount contract already does).

## Cost, 5 sticks (guess)
Parts ~$3 per board (ATECC $1, MCP2221A $1.60, plug $0.14, rest pennies). PCBs $4. Standard assembly setup $50 + fixture for the plug ~$17 + feeders 5 types $15. **≈ $110 for 5** before shipping/tariff. Second batch far cheaper per unit.

## Risks
1. Plug orientation/fit: pads 0.95 mm from the edge on a 0.8 mm board, per the drawing. First board tells.
2. Top row unwired (see above). Should work; not spec-exact.
3. Blue LED depends on GP3's factory default being I2C-LED. If not, it just stays off. Configurable with Microchip's utility.
4. No ESD protection on D+/D−. Fine for a bench stick; add a USBLC6 in v1.
5. Not electrically tested. Passed netlist/placement/shorts.

Renders: `render/`. 3D: `board.glb`.

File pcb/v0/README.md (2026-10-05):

# Revised picowallet v0.8 — engineering build, not order approval

The revised files are in pcb/v0/. Do not use the previous JLCPCB cart or previews for this revision.

Fixed: switch now controls an AO3401A power transistor; AO3400A backlight transistor and 39-ohm resistor; 0.6/0.3 mm vias; switch-hole clearance; corrected connector land pattern and y=-0.43 mm alignment; redundant Pico underside lands removed; explicit 1.6 mm board thickness; charger heat-spreading copper and two tented vias; corrected joystick labels; consistent assembly files with Pico rotation 180; pinned dependencies and reproducible build/check scripts.

Charging is DISABLED by default. SJ1 is an open solder jumper. R3=12k gives 100 mA nominal, up to about 111 mA with stated tolerances. Do not bridge SJ1 until the exact protected cell, charge limit and plug polarity are verified. The slide switch controls battery power only; USB still powers the board.

Checks passed: source build and TypeScript; independent Gerber connectivity and clearances; KiCad pad/track comparison; power and firmware pin-number assertions. See copper-check.txt, kicad-check.txt and design-check.txt. Firmware host tests passed for the existing display and the new 320x240 profile. These are not powered hardware tests.

Unresolved before ordering/powering:
- Physical ribbon reach, bend, contact numbering, panel support and insulation. Connector moved 2 mm toward the panel exit, but fit is not proven. Never use J3-to-board-rail continuity as a ribbon polarity test: it passes without a panel. Identify PANEL-side conductors independently with a numbered breakout and verify asymmetric supply/LED pins unpowered.
- Exact battery qualification; keep SJ1 open meanwhile.
- Assembler confirmation of all component orientations, including the corrected Pico rotation. Panel and battery are excluded from automated assembly; arrange separate supply and manual fitting. SJ1 is intentionally unpopulated.
- Actual display initialization/colors, charger temperature and radio performance. The Pico antenna remains under the panel/carrier; RF layout was not corrected. Panel 3.3 V supply tolerance margin remains unqualified. No full fabrication DFM or mask/paste sign-off is claimed.

Install firmware/boards/picowallet_v08/lcd_config.py beside lcd.py on the new Pico: 320x240, 8 MHz SPI, backlight initially off. The existing Waveshare profile stays the default without that file. Initialization and joystick directions still need a physical test.

Rebuild from pcb/v0 with Bun 1.3.14 and Python 3.12: create a Python environment, install pcb/dossier/review/requirements.txt, then run that environment's Python on scripts/build_release.py. It produces dist/release and stops on failed checks. The fabrication ZIP contains only Gerbers/drills; use the separate BOM and placement CSVs. SHA256SUMS.txt identifies the supplied files.

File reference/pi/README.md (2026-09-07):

# pi/ — the signer, and what to do with a brand-new ATECC608

This folder runs on a Raspberry Pi with an ATECC608 secure element on I2C. The chip holds the
P-256 private key that owns the vault contract. Nothing here touches the chain: the Pi signs
32-byte digests and talks HTTP to the app.

```
app (Mac)  --request {to, amount, digest}-->  Pi  --{r, s}-->  app relay  --tx-->  ChipAccount.executeTransfer
app (Mac)  --setup job {status | genkey | lock-config}-->  Pi  --result-->  app
```

If you are a person or a bot with a fresh chip in your hand, read **"You just got a chip"** first.
Everything in it was done for real on 2026-09-04 with an ATECC608A on a Pi (serial
`01235e6763cc8d97ee`); the outputs shown are what the real run printed.

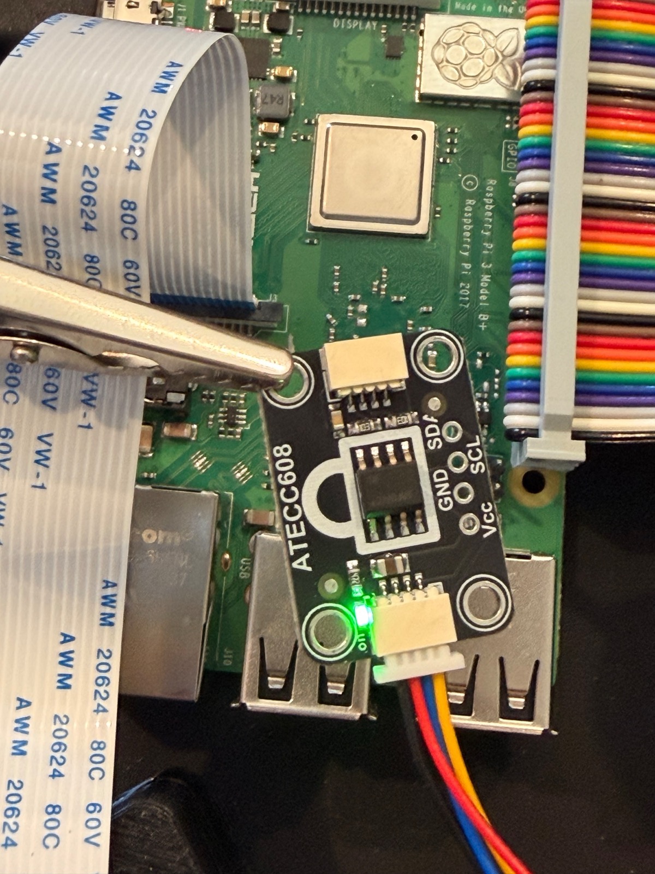
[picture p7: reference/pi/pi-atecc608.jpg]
Adafruit ATECC608 breakout on a Raspberry Pi 3 B+


**The hardware in the photo:** Raspberry Pi 3 Model B+ · Adafruit ATECC608 STEMMA QT breakout
(the black board, green power LED on) · a 4-wire STEMMA QT / JST-SH cable to the Pi's header for
Vcc, GND, SDA, SCL. Any Pi with I2C and any ATECC608A/B breakout works the same.

---

## You just got a chip

### What a fresh chip is

A breakout-board ATECC608 (Adafruit, SparkFun, generic "ATECC608A" boards) ships **blank and
unlocked**:

- **config zone unlocked** — the 128-byte table that says what each of the 16 key slots is for
  is still editable.
- **data zone unlocked** — the slots themselves are still writable in the clear.
- **no key anywhere.**

Here is the catch that surprises everyone: **an unlocked ATECC608 will not generate a key and will
not sign.** Every crypto command returns execution error `0xF4` until the config zone is locked.
This is by design. The chip wants its rules frozen before it will hold a secret.

Verified on this chip before locking:

```
$ python3 -c "import signer; s=signer.AteccSigner(addr7=0x60); print(s.status())"
{'serial': '01235e6763cc8d97ee', 'revision': '00006002', 'configLocked': False, 'dataLocked': False, 'slot': 0, 'hasKey': False}
$ ... atcab_genkey(0, pub) -> 0xfffffff4        # ATCA_EXECUTION_ERROR: chip refuses, config not locked
```

### The two locks, and which one you do

| Zone | What locking does | Reversible? | This demo |
|---|---|---|---|
| **Config** | Freezes the slot table: slot 0 = P-256 private key, may sign external digests, GenKey allowed. | **No. Permanent.** | **Lock it.** Required to do anything. |
| **Data** | Freezes slot contents. After this, GenKey on a slot is only allowed if the config says so, and clear-text writes stop. | No. Permanent. | **Leave it unlocked.** You can run GenKey again any time and get a fresh key. |

"Permanent" sounds scary. It is normal: every ATECC608 in a product is config-locked. Locking the
config zone does not put a key in, does not choose a key, and does not stop you from making new keys
later. It only fixes *what kind of thing* each slot is. Microchip's own pre-provisioned parts
(TrustFLEX, Trust&Go) arrive config-locked *and* data-locked with a key already in slot 0.

The config we write is Microchip's ATECC608 reference config from cryptoauthlib
(`test/api_calib/test_calib_config.c`), embedded in `signer.py` as `AteccSigner.CONFIG`. Slot 0:
P-256 private key, external signing enabled, GenKey allowed. Slots 1-7 more private keys, 8 general
data, 9-15 certificates and public keys. Bytes 0-15 (serial, revision) and 84-87 (lock bytes) are
read-only; cryptoauthlib skips them.

### Step by step

**0. Wire it** (breakout to Pi 40-pin header; STEMMA QT cable colours in brackets)

| Breakout | Pi header |
|---|---|
| VIN / VCC (red) | 3V3 (pin 1) |
| GND (black) | GND (pin 6) |
| SDA (blue) | GPIO2 / SDA (pin 3) |
| SCL (yellow) | GPIO3 / SCL (pin 5) |

Enable I2C: `sudo raspi-config` → Interface Options → I2C → enable → reboot. If you can't sudo,
check `ls /dev/i2c-1` exists; on Raspberry Pi OS / Debian it usually is.

**1. Find it on the bus.** With i2c-tools: `i2cdetect -y 1`. Without (no sudo to apt):

```bash
python3 - <<'PY'
import os, fcntl
fd = os.open('/dev/i2c-1', os.O_RDWR); found = []
for a in range(0x03, 0x78):
    try: fcntl.ioctl(fd, 0x0703, a); os.write(fd, b''); found.append(hex(a))
    except OSError: pass
print(found)
PY
```

Expect `0x60` (most breakouts) or `0x35` (TrustFLEX / Trust&Go). The chip sleeps between commands
and may not show every time; run it twice. Ours: `['0x39', '0x60']` (0x39 was something else on the
board).

**2. Install.** Python 3.11+ on the Pi.

```bash
git clone https://github.com/clawdbotatg/ATECC608-demo ~/ATECC608-demo
cd ~/ATECC608-demo/pi
pip3 install --user --break-system-packages cryptoauthlib requests cryptography
python3 -c "import cryptoauthlib as c; c.load_cryptoauthlib(); print('ok')"
```

The `cryptoauthlib` wheel on PyPI carried a working `libcryptoauth.so` for a 64-bit Pi (Debian 13,
aarch64, Python 3.13). If `load_cryptoauthlib()` fails, build it:

```bash
git clone https://github.com/MicrochipTech/cryptoauthlib && cd cryptoauthlib
cmake -B build -DATCA_HAL_I2C=ON -DATCA_ATECC608_SUPPORT=ON -DATCA_BUILD_SHARED_LIBS=ON
cmake --build build -j4 && sudo cmake --install build && sudo ldconfig
```

**3. Talk to it.** Read-only; safe on any chip.

```bash
python3 -c "import signer; print(signer.AteccSigner(bus=1, addr7=0x60).status())"
# {'serial': '01235e67…', 'revision': '00006002', 'configLocked': False, 'dataLocked': False, 'slot': 0, 'hasKey': False}
```

`revision 00006002` = ATECC608A. `00006003` = ATECC608B. Both work the same here.

**4. Start the signer, pointed at the app.** The app runs on your laptop (see the root README:
`yarn chain`, `yarn deploy`, `yarn dev -p 3000`). Use the laptop's LAN IP.

```bash
./start.sh http://192.168.1.50:3000 --i2c-addr 0x60 --allow-lock
tail -f signer.log
```

`--allow-lock` is only needed for step 5. Without it the signer refuses the lock command, so a
stray click can't lock a chip you meant to keep blank.

The log on a fresh chip:

```
[atecc608] no key: config zone is not locked; the chip has no usable key yet (Setup page, step 1)
[atecc608] announced to http://192.168.1.50:3000 -> no key (Setup page)
```

**5. Lock the config zone.** Open the app's **/setup** page. The Device card shows the real chip:
serial, `config zone unlocked · data zone unlocked`. Step 1 has a **Lock config zone** button. Click
it, confirm. The browser queues the job; the Pi picks it up within a second:

```
[atecc608] command lock-config (mtnkpdmw-h8dxrq)
  config zone locked (data zone left unlocked)
  done
[atecc608] no key: atcab_get_pubkey failed: 0xF4        <- slot 0 is still empty, expected
```

That is the one permanent step. Done.

**6. Generate the key.** Step 2, **Generate key**. The chip makes a P-256 key inside slot 0 and
returns only the public half:

```
[atecc608] command genkey (mtnkprsl-lcux7u)
  new key
  qx 0xe894cec7682c9ded169f5e137befe9aab54f7e595700bae943088f8123192718
  qy 0x03e681f87a1044a882d57596580adc592fce6a9ef0182b1360c95fc7d312433f
  done
[atecc608] announced to http://192.168.1.50:3000 -> does not match vault signer
```

Record these coordinates and deploy the vault with them. Do not generate another key after funding:
the vault's recovery wallet can rotate the key only after an uninterrupted 14-day delay.

**7. Deploy.** Put the coordinates in `CHIP_PUBKEY_X` and `CHIP_PUBKEY_Y`, then deploy a new
`ChipAccount`. Only the current chip can spend; the recovery wallet can rotate the key after 14 days.

**8. Fund.** Step 4, **Mint into vault** (localhost) or send real tokens to the vault address.

**9. Send.** Go to **Send**, type `atg.eth` and `5`, press **Send to chip**:

```
[atecc608] request mtnkq95q-tgd6tb: send 5 USDS to atg.eth
  digest 0xb55d28f82e10532c492cc0d614930ad7feacd11eba982f4206b31986727f2c1b
  signed in 106 ms
  r 7908a23c17610521b8f815233f1e72f1900d885aef12a7ae8176fd70b553c6f4
  s 2a0e3f638cea6d47fa7f48374fca4a1818d36d6eeb5b8a052306db66208efa50
  -> confirmed  tx 0x0a5374e51b46f81833edeb6ddbd1f6918a471efaa59e15faca2c069aabdf6827
```

The chip signed in 106 ms. The relay paid ~60k gas. The contract verified the P-256 signature and
moved the tokens. Signing works with the data zone unlocked; you do not need to lock it.

### Second chip, or starting over

- **Another fresh chip:** repeat steps 3-7 and deploy a separate vault for its key.
- **New key on the same chip:** move all assets out first, generate the key, and deploy a new vault.
  The old vault cannot be updated and becomes inaccessible once its old key is gone.
- **Pre-locked part (TrustFLEX / Trust&Go, I2C 0x35):** skip step 5; it is already config- and
  data-locked with a key in slot 0. Start at step 4 with `--i2c-addr 0x35`, then deploy with its key.
- **You locked config:** you cannot undo it. Whether keys remain regenerable depends on the data-zone
  and slot configuration; never regenerate a key that still controls a funded vault.

### Errors you will actually see

| Message | Meaning |
|---|---|
| `atcab_init failed: 0x…` | Wrong wiring, wrong bus, wrong `--i2c-addr`, or I2C not enabled. |
| `… failed: 0xF4` | `ATCA_EXECUTION_ERROR`. Config zone not locked (GenKey/Sign refused), or reading a public key from an empty slot. |
| `refused: start signer.py with --allow-lock …` | You clicked Lock config without the flag. Restart the signer with `--allow-lock`. |
| `config zone is not locked; the chip has no usable key yet` | Normal on a fresh chip. Do step 5. |
| `ModuleNotFoundError: cryptoauthlib` | Step 2. |
| `attribute 'ATCA_SUCCESS'` / `'LOCK_ZONE_CONFIG'` | Old copy of `signer.py`. `git pull`. The Python binding keeps these under `Status` and doesn't export zone ids; `signer.py` handles it. |

---

## Running without a chip

```bash
python3 signer.py run --mock --app http://localhost:3000
```

`--mock` uses a software P-256 key in `.mock_key.pem` (gitignored). Same code path, same low-s
normalisation, same HTTP calls, same setup jobs (lock is a no-op). The Foundry tests call it over ffi.

## Files

| File | What |
|---|---|
| `signer.py` | The daemon. `run` announces the chip, runs setup jobs, signs requests. `pubkey` / `sign` are one-shots. `--mock`, `--confirm` (ask on the terminal), `--button 17` (GPIO button), `--allow-lock`. |
| `start.sh` | `./start.sh <app-url> [flags]` — restarts the daemon in the background, pid in `signer.pid`, log in `signer.log`. |
| `provision.py` | CLI fallback for steps 5-6 without the app. `--yes` to actually lock config + GenKey. `--lock-data` only if you really want the data zone locked too. |
| `requirements.txt` | pip deps. |

## Notes for the curious

- The ATECC608 signs a raw 32-byte digest. It does not hash. The app hands it the finished EIP-712
  digest, the same bytes the contract recomputes.
- ECDSA has two valid `s` per signature. The contract (OpenZeppelin `P256`) accepts only the low one,
  so the signer normalises `s > n/2` to `n - s`. The relay does it again, defensively.
- A request expires 10 minutes after it is created. Sign it or it is dropped.
- `--i2c-addr` is the 7-bit address. cryptoauthlib wants it shifted left one bit; `signer.py` does
  that, and finds the field whether the binding calls it `address`, `slave_address`, or hides it in
  a union `u`.
- The Pi never opens a port. It only makes outbound HTTP to the app, so it works from behind any
  WiFi with no config.

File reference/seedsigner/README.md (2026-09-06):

SeedSigner enclosure parts, MIT, https://github.com/SeedSigner/seedsigner/tree/dev/enclosures
Same Waveshare 240x240 LCD + joystick + tact switches as the Pi HAT twin of our board. Reference for cap and thumbstick geometry.

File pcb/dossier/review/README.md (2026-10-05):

# Reproducing the review checks

From any working directory, in an isolated Python environment with `requirements.txt` installed:

```
python /Users/austingriffith/picowallet/pcb/dossier/review/check_copper.py
python /Users/austingriffith/picowallet/pcb/dossier/review/check_kicad.py
```

Scripts locate `../design` relative to their own location. They do not modify the design.

`check_copper.py` reads copper Gerbers with gerbonara, expands shapes through Shapely, handles Gerber LR flash rotations explicitly (gerbonara 1.6.3 ignores LR), joins touching copper per layer, and joins layers at plated drill centers. It derives intended net groups from JSON source traces, then maps PCB port centers to the physical copper. Curve approximation and a 0.000002 mm connectivity tolerance are used. Reported drilling-clearance examples are far larger than numerical approximation error; the worst example has an independent simple analytic calculation in the review.

Connectivity is checked against the supplied compiled netlist, not against electrical behavior inside real components. This is not a certified CAM tool, a complete fabrication DRC, a solder-mask/paste audit, or an independent fresh tscircuit rebuild. Component assembly orientation, pin-function correctness, hidden module copper, power budgets, and mechanical fit require separate review.

`check_kicad.py` reads the supplied ZIP and compares 132 named SMT pad centers and 448 trace segments against JSON. It does not run KiCad's native DRC. The thermal pad name is not included in that center comparison, and pad shapes/rotations and net assignments are not comprehensively compared.

`design-SHA256SUMS.txt` fingerprints the design inputs examined. It does not fingerprint JLCPCB's server-side job, which was unavailable to this review.

Retrieved supporting manufacturer PDFs are preserved here; their source URLs and conclusions are in `../INDEPENDENT-REVIEW.md`. No external messages or order changes were made.

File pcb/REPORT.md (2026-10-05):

> SUPERSEDED: this document describes v0.7c. Use [the revised v0.8 design](picowallet-v0.8-reviewed.zip) and pcb/v0/README.md. The old cart, renders and ribbon safety instructions are not valid for the revision.

# picowallet one-board v0.7c — review report (2026-09-24)

**Full dossier with every file, image, datasheet and the worked ribbon-fold geometry: `pcb/dossier/DOSSIER.md`.**

**Ask for the reviewer:** find the thing that makes board #1 dead. Everything below is what was done, what was checked, and what was not. Files: `pcb/v0/index.circuit.tsx` (the design, 130 lines), `pcb/v0/fab.zip` (Gerbers), `pcb/v0/bom.csv`, `pcb/v0/pick_and_place.csv`, renders in `pcb/v0/render/`, live 3D at the link in ORDER.md.

## Goal

Turn the three-part picowallet (Pico 2 W + Waveshare LCD hat + ATECC608 breakout, hand-wired) into one board that JLCPCB assembles end to end. Zero soldering on arrival: plug in the screen ribbon, click in the battery, flash the same firmware.

## The circuit

| Block | Parts | Notes |
|---|---|---|
| Brain | Raspberry Pi Pico 2 W module, soldered on the back, USB at the left edge | Runs the existing MicroPython firmware unchanged. GPIOs identical to today. |
| Secure element | ATECC608B (SOIC-8) on I2C0: SDA GP4, SCL GP5, 4.7k pull-ups, 100 nF | Same chip as the Adafruit breakout. |
| Screen | Bare 2" 320×240 ST7789 panel (LCSC C5329582), 12-pin ribbon folded under the panel into a 1 mm 0.5 mm double-contact latch (J3, LCSC C466532) | CS GP9, DC GP8, SCK GP10, MOSI GP11, RST GP12. VCC and IOVCC on 3V3. |
| Backlight | VSYS → 27 Ω → LEDA; LEDK → 2N7002 → GND; gate GP13 with 10k pulldown | 4 white LEDs in parallel, 3.0 V, 80 mA rated. |
| Input | ALPS 5-way joystick (up GP2, down GP18, left GP16, right GP20, press GP3), buttons A GP15, B GP17 | All switch to GND, internal pull-ups. |
| Power | LiPo (JST-PH J2 on the back) → slide switch → SS14 Schottky → VSYS. TP4056 charger fed from VBUS, PROG 6.2k (~195 mA), CE high, TEMP grounded, 10 µF in/out | USB powers the board through the Pico's own path whether the switch is on or off. |
| Lights | Green PWR on 3V3 via 1k. Red CHG from VBUS via 1k into the TP4056 CHRG pin | CHG lights only while charging. |
| Board | 82 × 44 mm, 2 layers, 4 corner holes Ø2.7 | Panel lies flat on the front, 2 mm. Pico and battery on the back, 4 mm. |

## What was done

1. Design in tscircuit (React → circuit). Autorouted. Passed netlist, placement, shorts, and trace-clearance checks.
2. Net-by-net review against datasheets: Pico pinout (all 40), ATECC608B, TP4056, SS14, ALPS joystick (center/common), panel ribbon table.
3. tscircuit's own checks caught two real bugs before upload: green LED pin polarity backwards vs the LCSC part, and a resistor whose value changed but part number didn't.
4. Uploaded to JLCPCB. All 25 parts matched to in-stock parts, including the bare panel, which JLCPCB will place. Standard assembly, both sides, 5 boards, parts-placement confirmation on. Quote $221.37 before shipping and tariff. Cart item fab_Y6.
5. JLCPCB's placement preview caught three more: Pico 6 mm inboard from the edge; Pico rotated 180° (tscircuit exports bottom rotation with a mirror convention JLCPCB reads differently); a placeholder battery row merged into a capacitor. All fixed and re-uploaded. Bottom preview re-checked: USB at the edge, pin 1 at the USB end.

## Sure (checked, evidence in hand)

- Pico footprint, mirror, rotation, all 40 labels. Seen in JLCPCB's own bottom preview.
- Every GPIO matches `firmware/lcd.py` and `firmware/atecc.py`.
- ATECC608B pinout and pull-ups.
- TP4056 pinout. CHG LED wiring matches the datasheet's status-pin behavior.
- Diode direction and the battery → VSYS scheme (Pico datasheet method).
- LED polarities (tool-checked against LCSC part data).
- Joystick common and center pins (ALPS drawing). Directions are a firmware table.
- No shorts, no overlaps, all traces ≥0.275 mm from the edge.
- All parts in stock; JLCPCB accepts the files.

## Not sure (ranked by how much it worries me)

1. **Ribbon pin order after the fold.** Worked out from the datasheet drawing (dossier §3): pin 1 lands on connector pad 1 if the "1 … 12" labels are in the front view, which is how I read it. If wrong, a reversed ribbon puts 3V3 onto GP10/GP11 and VSYS onto the panel's RS pin: not harmless. **Before first power with the panel: multimeter J3 pad 1 to GND (≈0 Ω) and pad 8 to 3V3 (≈0 Ω). If pad 12 reads 0 instead, flip the ribbon.**
2. **Latch mouth direction.** I assumed the connector's opening faces the panel edge (rotation 270). If it faces the other way the ribbon needs an extra fold. Awkward, not fatal.
3. **Panel orientation as JLCPCB places it.** Their preview shows only a marker for the panel. The parts-placement confirmation email is the check: the ribbon must exit toward J3 (left). Approve only if it does.
4. ~~Backlight resistor~~ Changed to 27 Ω: 74 mA at 5 V, 44 mA at 4.2 V, 26 mA at 3.7 V.
5. ~~Charge current~~ Changed to 6.2k: ~195 mA, 1C.
6. **Load sharing.** With USB in and the switch on, the charger and the load share the battery. Standard TP4056 hobby-board behavior: charge may never terminate. Fine for the bench, wrong for a product.
7. **Slide switch common pin.** Middle pad wired as common, by geometry and convention. Datasheet PDF wouldn't download. Wrong = switch dead, fix with a wire.
8. **Battery plug polarity.** Amazon LiPos ship with red on either side. Check red = BAT+ on the silkscreen before plugging in.
9. **Firmware.** The panel is 320×240, not 240×240, and it's a different ST7789 build. Expect init-sequence and layout work. Backlight is now GP13 → MOSFET, active high, same sense as before.
10. **Pico courtyard.** I trimmed the imported Pico courtyard by 2 mm so the placement check would pass. Copper is untouched. Pads are 1.2 mm from the board edge.
11. **Panel supply.** VCC/IOVCC at 3.3 V is the top of the panel's stated range (IOVCC 1.65–3.3, VCI 2.4–3.3). Legal, no margin.
12. **WiFi.** The Pico's antenna end sits under the battery plug and near button B. Expect some range loss.
13. **Nobody has powered one.** Only the diode path was SPICE-simulated.

## What I'd like extra eyes on

- Items 1–3 above, by someone who has hand-assembled an FPC LCD: look at `pcb/ref/lcsc-C5329582-*` photos and the datasheet drawing, tell me which end is pin 1 after a 180° fold under the panel.
- Backlight and charge-current values (items 4–5). Both are one-resistor changes; say the word and I re-upload.
- The Pico bottom preview screenshot vs the Pico 2 W pinout: pin 1 = GP0 at the USB end, left column when USB is up.
- The JLCPCB placement-confirmation email when it arrives: panel ribbon toward J3, D1 band toward VSYS, U2/U3 pin-1 dots where the silkscreen says.

## Bring-up order (raises the odds more than anything above)

1. No battery, no panel. USB in, switch off. PWR LED on? Measure 3V3 on the ATECC VCC pin. Flash firmware, run `keytest.py`: joystick and buttons.
2. Battery in, USB out, switch on. Board stays up? USB back in: CHG LED on?
3. Everything off. Ribbon in, latched. Multimeter: J3 pad 1 ↔ GND ≈ 0, pad 8 ↔ 3V3 ≈ 0. Reversed → flip. Then battery only, USB out, init the panel.
4. Only then USB + panel together.

## Cost

$221.37 JLCPCB + shipping + US tariff (shown at checkout) + ~$25 batteries. About $50 a wallet.

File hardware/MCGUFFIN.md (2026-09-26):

# v2 wiring: the McGuffin

The v2 wallet hardware, still on the bench. The v1 build (Pico-LCD-1.3 HAT with the ATECC608 on
wires) stays the documented build in the top README until v2 works.

**The idea:** the signing key does not live in the wallet. It lives in **the McGuffin**, a
3D-printed sci-fi key with one signing chip inside and two headphone plugs, a 3.5 mm and a
2.5 mm, coming out of the same side. The wallet has the matching pair of jacks. Plug the
McGuffin in and the wallet can sign. Pull it out and the wallet holds nothing.

| part | notes |
|---|---|
| Raspberry Pi Pico 2 W (RP2350) | same board as v1; RP2350 has secure boot in OTP (see the end) |
| ILI9341 2.4 to 2.8" SPI TFT, 240x320 | from the Amazon variety pack; the red board with the 14-pin header |
| EC11 rotary encoder with push switch | the dial; replaces the v1 joystick |
| 4 tact switches, 6x6 mm | A, B, X, Y, same roles as v1 |
| 18650 cell + holder | |
| TP4056 USB-C charger **with protection** | the 6-pad board with B+ B- OUT+ OUT- (DW01 + 8205 chips on it) |
| signing chip, one per McGuffin | Adafruit OPTIGA Trust M STEMMA (I2C 0x30) or Adafruit ATECC608 STEMMA (I2C 0x60). Which one is still open |
| 3.5 mm + 2.5 mm TRRS jacks and plugs | **4-pole (TRRS)**, not 3-pole TRS. Count the black rings on the plug: 3 rings = 4 contacts |

Full shopping list with resistors and diodes: [parts](#parts).

**Building with what is on the bench now?** [BUILD1.md](BUILD1.md) is the subset with the 2.0" ST7789,
the knob and an ATECC key, no extra components, with a drawn wiring diagram. Same pins as below.

## The McGuffin plugs

Two prongs give 8 contacts. I2C needs 4, so the other 4 add reset, key detection and a chip ID.

```
   McGuffin (printed body, chip inside)
  ┌──────────────────────┐
  │                      ├══[S]=[R2]=[R1]=>T   3.5 mm:  T SDA   R1 SCL   R2 VCC   S GND
  │   Trust M or ATECC   │
  │                      ├══[S]=[R2]=[R1]=>T   2.5 mm:  T DETECT  R1 RST  R2 ID  S GND
  └──────────────────────┘
```

| prong | Tip | Ring 1 | Ring 2 | Sleeve |
|---|---|---|---|---|
| 3.5 mm | SDA (blue) | SCL (yellow) | VCC (red) | GND (black) |
| 2.5 mm | DETECT: wire to this plug's Sleeve | RST (Trust M RST pin; ATECC: leave unconnected) | ID: resistor to Sleeve | GND |

Inside the key: the chip breakout's STEMMA QT cable is cut and its four wires go straight to the
3.5 mm plug, colours as in the table. On the 2.5 mm plug, a short wire links Tip to Sleeve, the ID
resistor sits between Ring 2 and Sleeve, and one wire goes from Ring 1 to the breakout's RST pad
(Trust M only; check the silkscreen, it is a header pin, not on the STEMMA connector). Join the two
Sleeves inside the key.

**ID resistor:** the wallet reads it on GP27 with a 10 kΩ pull-up, so firmware knows which
driver to load without a setting.

| key | ID resistor | GP27 reads |
|---|---|---|
| Trust M | 10 kΩ | 3.3 × 10/20 ≈ 1.65 V |
| ATECC608 | 33 kΩ | 3.3 × 33/43 ≈ 2.53 V |
| nothing in, or unknown | open | 3.3 V |

### Why this order, and hot-plug rules

A plug slides in tip first, so the plug's tip wipes across every jack contact on the way in. The
jack's sleeve contact is at the mouth. Putting GND on the sleeve means that during insertion the
signal lines only brush GND, which open-drain I2C does not mind. VCC is the one line that can do
harm, so **the wallet keeps key VCC switched off** until the key is fully in:

1. DETECT (GP22, pull-up) reads 0 steadily for ~300 ms. Both prongs are seated: the 2.5 mm tip only
   meets the tip contact at the end of the travel.
2. Switch VCC on (GP6 low), wait 10 ms, check SDA and SCL read 1 (a pair of headphones would hold
   them low), then read the ID and talk I2C.
3. DETECT goes 1 or I2C errors: VCC off, and set GP4, GP5, GP26 to inputs so nothing back-powers the
   chip through its pins. Power cycling is also the reset of last resort.

Do not plug the McGuffin into a phone or laptop: their mic bias (about 2 V) lands on a contact.
Headphones in the wallet are harmless: DETECT never goes low, so VCC never turns on.

**Jack spacing:** the two jacks in the wallet must sit at the same centre-to-centre distance as
the two plugs in the key body. Measure the parts when they arrive and put the number in the case
generator; the plug shells need about 1 mm of wall between them.

## Pin map, Pico 2 W

The TFT and A/B/X/Y keep the v1 GPIO numbers from `firmware/lcd.py`, and the key bus keeps the
v1 ATECC pins from `firmware/atecc.py`. Only the display driver changes (ST7789 to ILI9341) and the
joystick becomes the dial.

| function | GPIO | Pico pin | notes |
|---|---|---|---|
| dial push | GP1 | 2 | switch to GND, internal pull-up |
| dial A | GP2 | 4 | internal pull-up, 10 nF to GND |
| dial B | GP3 | 5 | internal pull-up, 10 nF to GND |
| key SDA | GP4 | 6 | I2C0, 100 Ω in series at the jack |
| key SCL | GP5 | 7 | I2C0, 100 Ω in series at the jack |
| key VCC enable | GP6 | 9 | low = on, drives the PNP (Build 1: high = on, powers the key directly) |
| TFT DC | GP8 | 11 | |
| TFT CS | GP9 | 12 | |
| TFT SCK | GP10 | 14 | SPI1 |
| TFT MOSI (SDI) | GP11 | 15 | SPI1 |
| TFT RESET | GP12 | 16 | |
| TFT LED | GP13 | 17 | PWM backlight, see [screen](#screen) |
| key A | GP15 | 20 | tact switch to GND, internal pull-up |
| key B | GP17 | 22 | |
| key X | GP19 | 25 | |
| key Y | GP21 | 27 | |
| key DETECT | GP22 | 29 | internal pull-up |
| key RST | GP26 | 31 | 100 Ω in series; active low on the Trust M |
| key ID | GP27 | 32 | ADC1, 10 kΩ pull-up to 3V3 |
| battery sense | GP28 | 34 | ADC2, 100k/100k divider |
| 3V3 OUT | | 36 | TFT VCC, key switch, pull-ups |
| VSYS | | 39 | battery in, through the Schottky |
| GND | | 3, 8, 13, 18, 23, 28, 33, 38 | any |

Spare: GP0, GP7, GP14, GP16, GP18, GP20. GP23, GP24, GP25 and
GP29 are wired to the WiFi chip on the Pico 2 W and are not on the header; do not use them.

```
                         USB
                  ┌─────┤   ├─────┐
  (spare)   GP0   1 │ o           o │ 40  VBUS
  dial SW   GP1   2 │ o           o │ 39  VSYS      <- battery via Schottky
            GND   3 │ o           o │ 38  GND       <- battery -, all grounds
  dial A    GP2   4 │ o           o │ 37  3V3_EN    (leave alone)
  dial B    GP3   5 │ o           o │ 36  3V3 OUT   -> TFT VCC, key PNP, pull-ups
  key SDA   GP4   6 │ o           o │ 35  ADC_VREF
  key SCL   GP5   7 │ o           o │ 34  GP28      battery sense
            GND   8 │ o           o │ 33  GND
  key VCC   GP6   9 │ o           o │ 32  GP27      key ID
  (spare)   GP7  10 │ o           o │ 31  GP26      key RST
  TFT DC    GP8  11 │ o           o │ 30  RUN
  TFT CS    GP9  12 │ o           o │ 29  GP22      key DETECT
            GND  13 │ o           o │ 28  GND
  TFT SCK   GP10 14 │ o           o │ 27  GP21      key Y
  TFT MOSI  GP11 15 │ o           o │ 26  GP20      (spare)
  TFT RST   GP12 16 │ o           o │ 25  GP19      key X
  TFT LED   GP13 17 │ o           o │ 24  GP18      (spare)
            GND  18 │ o           o │ 23  GND
  (spare)   GP14 19 │ o           o │ 22  GP17      key B
  key A     GP15 20 │ o           o │ 21  GP16      (spare)
                  └─────────────────┘
```

## Key jack circuit

```
 3V3 OUT (36) ──┬──────────────── E
                │                  \
               10k               PNP  2N3906 / S8550
                │                  /
 GP6  ──1k──────┴──────────────── B
                                   C ──┬──┬──── 3.5 mm Ring 2 (key VCC)
                                       │  │
                                     10µF 100nF
                                       │  │
                                      GND GND

 GP4  ── 100Ω ──┬────────────────────── 3.5 mm Tip    (SDA)
                10k ── key VCC
 GP5  ── 100Ω ──┬────────────────────── 3.5 mm Ring 1 (SCL)
                10k ── key VCC

 GP26 ── 100Ω ──────────────────────── 2.5 mm Ring 1 (RST)
 GP22 (pull-up) ────────────────────── 2.5 mm Tip    (DETECT)
 3V3 ──10k──┬───────────────────────── 2.5 mm Ring 2 (ID)
            └── GP27
 GND ───────────────────────────────── both Sleeves
```

- The 10k pull-ups on SDA/SCL go to **key VCC** (the PNP collector), not to 3V3. Pulled to 3V3
  they would feed the chip through its pin diodes while VCC is off. The breakouts have their own
  pull-ups too; these are extra margin for the plug contacts.
- The PNP drops 0.1 to 0.2 V, so the key sees about 3.1 V. Both chips are fine with that.
- Most panel jacks have extra pins for a built-in switch. Leave them unconnected; DETECT does
  that job and works the same on every jack.

## Power

```
 18650 ── holder ── TP4056 B+ / B-          (charge through the TP4056's own USB-C)
                    TP4056 OUT+ ──┬── slide switch ── 1N5817 ▶| ── VSYS (39)
                                  │
                                100k
                                  ├──────── GP28 (34)   + 100 nF to GND
                                100k
                                  │
                    TP4056 OUT- ──┴──────────────────────── GND (38)
```

- The Pico already has a Schottky from VBUS to VSYS, so USB and the battery OR together. Plugging
  USB into the Pico with the battery switched on is safe.
- Battery voltage in MicroPython: `ADC(28).read_u16() * 3.3 / 65535 * 2`. 4.2 V full, about
  3.3 V empty (the TP4056 board cuts off at about 2.5 V, well under what you want to reach).
- The divider sits on the battery side of the switch, so GP28 reads the cell even with the switch
  off (once USB powers the Pico). It draws 21 µA, which is nothing next to an 18650.
- Budget: Pico 25 to 50 mA, 2.8" backlight 40 to 80 mA, key a few mA. A 2500 to 3000 mAh cell is
  roughly a day of screen-on time; dim the backlight when idle.
- Never charge an unprotected 18650 without the protected TP4056 board, and don't hot-swap the
  cell with the TP4056 plugged in.

## Screen

The common red ILI9341 board pins, in header order: VCC, GND, CS, RESET, DC, SDI(MOSI), SCK, LED,
SDO(MISO), then T_CLK, T_CS, T_DIN, T_DO, T_IRQ for touch if fitted. Check your board's silkscreen.

| TFT | Pico |
|---|---|
| VCC | 3V3 OUT (36), and short the J1 pads on the back (bypasses its 3.3 V regulator). Or VSYS with J1 open |
| GND | GND |
| CS | GP9 |
| RESET | GP12 |
| DC | GP8 |
| SDI (MOSI) | GP11 |
| SCK | GP10 |
| LED | GP13, after the test below |
| SDO (MISO), touch, SD card | leave unconnected for now |

**Backlight test before wiring LED to a GPIO:** meter in current mode between 3V3 and LED.
- Under ~10 mA: the board has its own transistor; wire LED straight to GP13 and PWM it.
- More: drive it through a PNP. Emitter to 3V3, collector to LED, 1 kΩ from base to GP13. PWM is
  then inverted (low = bright).

## Dial and buttons

EC11 has 3 pins on one side (A, common, B) and 2 on the other (the push switch).
- Common and one push pin to GND.
- A to GP2, B to GP3, each with a 10 nF cap to GND to calm contact bounce.
- The other push pin to GP1.
- A, B, X, Y: one leg of each tact switch to its GPIO, the other to GND.

All inputs use the internal pull-ups, as `lcd.py` does now. No external resistors.

## Parts

| qty | part | where it goes |
|---|---|---|
| 2 | 1N5817 or SS14 Schottky (1 spare) | battery to VSYS |
| 2 | 100 kΩ | battery divider |
| 5 | 10 kΩ | 2 SDA/SCL pull-ups, 1 PNP base-emitter, 1 ID pull-up, 1 Trust M ID resistor |
| 2 | 1 kΩ | PNP bases (key switch, backlight if needed) |
| 3 | 100 Ω | SDA, SCL, RST series |
| 1 | 33 kΩ | ATECC McGuffin ID resistor |
| 2 | 2N3906 or S8550 PNP | key VCC switch, backlight if needed |
| 2 | 10 nF ceramic | dial A/B |
| 2 | 100 nF ceramic | key VCC, battery divider |
| 1 | 10 µF | key VCC |
| 1 | EC11 rotary encoder with push, plus knob | |
| 4 | 6x6 mm tact switch | A B X Y |
| 1 + 1 | 3.5 mm TRRS panel jack + solder-type TRRS plug | one plug per McGuffin |
| 1 + 1 | 2.5 mm TRRS panel jack + solder-type TRRS plug | one plug per McGuffin |
| 1 | TP4056 USB-C with protection | |
| 1 | SPDT slide switch | power |
| 1 | 18650 holder (+ cell) | |
| | perfboard, 26 to 28 AWG silicone wire, heat shrink | |

Resistor values that are close work the same: 4.7k to 10k for pull-ups, 47 to 220 Ω for the
series resistors. Buy a few extra plugs; they are the fiddly joints.

## Bring-up

One step at a time, on USB power, with the battery disconnected until the last step.

1. **Bare Pico:** flash MicroPython (top README, step 4). REPL works.
2. **Screen:** wire it, do the backlight test, check with a meter that no pin is shorted to its
   neighbour. The ILI9341 driver is still to be written; for now `Pin(13, Pin.OUT).value(1)` should
   light the backlight.
3. **Keys and dial:** `from machine import Pin; [Pin(p, Pin.IN, Pin.PULL_UP).value() for p in (1,2,3,15,17,19,21)]`
   shows 1s, and each switch makes its own 0.
4. **Jacks, nothing in:** GP22 reads 1, `ADC(27).read_u16()` near 65535. With GP6 high (or
   floating), 0 V on the 3.5 mm Ring 2 contact.
5. **McGuffin in:** GP22 reads 0, GP27 matches the ID table. Then:
   ```
   from machine import Pin, I2C
   Pin(6, Pin.OUT).value(0)           # key VCC on
   print(I2C(0, sda=Pin(4), scl=Pin(5), freq=100_000).scan())
   ```
   Trust M shows `[48]` (0x30). ATECC shows `[96]` (0x60) after the wake pulse in
   `app/SOLDERING.md`.
6. **Battery:** meter TP4056 OUT+ (3.7 to 4.2 V) and the Schottky's output before touching the
   Pico. Then connect VSYS, unplug USB, and check `ADC(28)` gives the cell voltage.

## Secure boot (later, not wiring)

The RP2350 can refuse to run firmware not signed with your key: you burn a hash of your public key
into its OTP with `picotool`, and from then on it only boots signed images. It is **permanent**.
Do it on one spare Pico, only after v2 works, and keep the signing key safe: lose it and that
board can never take new firmware.

What it buys the McGuffin: SECURITY.md notes the chip will sign whatever the MCU asks. Secure boot
means the MCU runs only your firmware, so a plugged-in McGuffin only signs what that firmware shows
on the screen and you confirm.

## Still to do

- `firmware/ili9341.py` with the same API as `lcd.py`.
- `firmware/trustm.py` (OPTIGA I2C protocol, P-256 sign) next to `atecc.py`.
- Key detect / ID / power handling and dial input in `wallet.py`.
- Emulator: ILI9341 screen size, dial, a plug-in key.
- Case: wallet body with the jack pair; McGuffin key body.

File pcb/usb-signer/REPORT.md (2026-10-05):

# usb-signer v0.3 — design report for review

Written 2026-09-24 by Claude for an independent review before ordering. Everything below is
verifiable from files in this folder. Where I guessed, I say so. Where I checked a datasheet, I cite
the page. The reviewer should try to break this.

## 0. Files in this folder

| File | What |
|---|---|
| `index.circuit.tsx` | the whole design, tscircuit (React/TSX). Source of truth. |
| `imports/*.tsx` | one component file per LCSC part, generated by `tsci import --jlcpcb <C#>`: pin labels, footprint, 3D model URL. I edited **one** of them by hand (see §4.1). |
| `NETLIST.txt` | compiled connection list and part positions, dumped from `dist/index/circuit.json` |
| `fab.zip` | Gerbers + drill + `bom.csv` + `pick_and_place.csv`, what gets uploaded to JLCPCB |
| `kicad.zip` | same design as a KiCad project, for a second-opinion ERC/DRC in KiCad |
| `board.glb` | 3D model |
| `render/pcb.png`, `render/3d-angle.png`, `render/schematic.png` | pictures |
| `ref/usb-c-plug-C3151751-*.pdf` | plug drawing (Shou Han TYPE-C 24P-GTJB 040) |
| `ref/MCP2221A-datasheet.pdf` | Microchip DS20005565C |
| `ref/ATECC608B-datasheet.pdf` | Microchip DS40002239A summary |

Rebuild: `cd usb-signer && npm i && npx tsci build --pcb-png --3d-png && npx tsci check netlist && npx tsci check placement && npx tsci check shorts`. All three checks pass at commit time.

## 1. What it is and why

A USB-C stick that exposes an ATECC608B secure element to a computer. No microcontroller, no
firmware. The MCP2221A is a fixed-function USB-to-I2C bridge: the host enumerates it as a USB HID
device and issues I2C reads/writes through it. The ATECC608B holds a P-256 key that never leaves the
chip; the host sends a 32-byte digest, gets back a signature.

```
host USB-C receptacle ──► J1 plug ──► U1 MCP2221A ──I2C (SDA/SCL, 4.7k pull-ups)──► U2 ATECC608B
                                        │
                                   GP3 → blue LED (I2C activity)
                                   5 V from VBUS powers everything; no regulator
```

Why this shape: Austin asked for exactly this (crypto chip, I2C-to-USB bridge, USB-C male plug,
computer does the signing). It's the picowallet's secure element without the Pico, screen, buttons,
or battery. Same key-handling story, same `firmware/atecc.py` wire protocol, ported to the host.

## 2. Parts and why each one

| Ref | Part | LCSC | Stock 09-23 | Why this part |
|---|---|---|---|---|
| J1 | Shou Han TYPE-C 24P-GTJB 040, USB-C **male** plug, "clamping plate" type | C3151751 | 36,287 | The only PCB-mount male USB-C plug at LCSC with real stock (alternatives: C283539 59 pcs, C2895017 89 pcs). It clamps the board edge; the board itself is the plug tongue. $0.14. JLCPCB lists it "Standard PCBA only, assembly difficulty high" → expect a fixture fee. **Requires a 0.8 mm board** (drawing: "T=0.80±0.05mm"). |
| U1 | MCP2221A-I/ST, TSSOP-14 | C130462 | 395 | USB 2.0 full-speed to I2C/UART bridge, no firmware, HID class so no driver on macOS/Linux/Windows. TSSOP chosen over QFN (C637689, 421 pcs) because it's easier to inspect and rework. |
| U2 | ATECC608B-SSHDA-T, SOIC-8 | C1518769 | 1,146 | Same part and package as the picowallet BOM. I2C, 2.0–5.5 V. |
| R1 | 5.1 kΩ 0603 | C23186 (basic) | | USB-C Rd pulldown on CC. 5.1 k is the spec value for a UFP/sink. |
| R2 | 10 kΩ 0603 | C25804 (basic) | | RST pull-up. Microchip's own ADM00559 breakout uses 10 k to VDD. The datasheet does not promise an internal pull-up; a floating RST could reset randomly. |
| R3, R4 | 4.7 kΩ 0603 | C23162 (basic) | | I2C pull-ups. 4.7 k at 5 V ≈ 1 mA, standard for 100–400 kHz with two devices and short traces. Same value picowallet uses. |
| C1 | 470 nF 0603 | C1623 (basic) | | Required on VUSB (DS20005565C §1.4 / §2.2: "A capacitor connected to the VUSB pin is required if the USB transceiver LDO provides the 3.3V"). Microchip's board uses 0.47 µF. |
| C2, C3 | 100 nF 0603 | C14663 (basic) | | Decoupling for U1 VDD and U2 VCC. |
| LED1 + R5 | green 0603 (KT-0603G, C12624) + 1 kΩ | basic | | Power indicator on VBUS. ~3 mA. |
| LED2 + R6 | blue 0603 (C965799) + 1 kΩ | basic | | I2C activity, driven by U1 GP3 in its LED_I2C function. |

Nothing else. No ESD diodes on D+/D− (see risks). No regulator (see §3.2).

## 3. Every design decision, with the reasoning

### 3.1 Power: everything on VBUS 5 V, no regulator
MCP2221A VDD is 3.0–5.5 V (DS20005565C, §"Electrical Characteristics"). ATECC608B VCC is 2.0–5.5 V
(DS40002239A). Both are happy at 5 V, so the 5 V from the host goes straight to both. The MCP2221A
makes its own 3.3 V for the USB transceiver internally on VUSB, which is why C1 exists. I2C runs at
VBUS level (pull-ups to VBUS); both chips' I2C pins are referenced to their own VDD/VCC, which is the
same rail. One fewer part, one fewer failure mode.

### 3.2 USB-C plug wiring (this is where the most judgement is)
A USB-C plug has 24 positions in two rows, A1–A12 (top) and B1–B12 (bottom). The host receptacle
internally ties A4/A9/B4/B9 (VBUS) together and A1/A12/B1/B12 (GND) together, and for USB 2.0 hosts
ties A6/B6 (D+) and A7/B7 (D−) together. It monitors CC1 (A5) and CC2 (B5) independently to detect
which way the plug is flipped.

**What I wired:**
- VBUS: B4, B9 (bottom row). GND: B1, B12 + the two shell/ground pads (pads 25, 26).
- D+: B6. D−: B7.
- CC: **A5** (top row) through R1 5.1 k to GND. B5 (VCONN) left open.
- A1, A4, A6, A7, A9, A12 (top-row power/data): **left open**.

**Why the top row's power and data are open:** the 0.5 mm-pitch top-row pads, sandwiched between the
plug shell pads and the bottom row, would not autoroute together with everything else; the router
gave up on 6 of them. Electrically it doesn't matter for USB 2.0 because the receptacle shorts
A-row and B-row VBUS/GND/D+/D− together; one row carries everything in either orientation. It is
not spec-exact (the spec expects both rows populated for current capacity), but at the < 100 mA this
stick draws, one VBUS pin (rated 3 A on this plug) is plenty. **Reviewer: confirm you agree this is
harmless for a USB 2.0 low-power device.**

**Why CC is on A5 and not B5:** the USB-IF Type-C Functional Test Spec says a device with a captive
plug "shall apply and sense CC voltage levels on pin A5 only and pin B5 shall have an impedance above
zOPEN". v0.1/v0.2 had Rd on B5 (wrong row). v0.3 moved it to A5. Functionally a host can't tell the
difference (plug A5 lands on host CC1 or CC2 depending on flip, and the host checks both), but A5 is
the rule and it routed fine.

**Plug pin labels vs. our net names:** the import file `imports/TYPE_C_24P_GTJB_040.tsx` labels the
pads by A/B position *and* by function; the functional aliases are inconsistent (its "CC1" is A5,
"CC2" is B5, "DP2/DN2" are B6/B7, "VBUS1/VBUS2" are B9/B4). `NETLIST.txt` shows the raw A/B names,
which is what to check against the plug drawing's pin table (`ref/…pdf` page 2, "PIN DEFINE TABLE").

### 3.3 The plug footprint, and the one hand edit
`tsci import` pulled the LCSC/EasyEDA footprint for C3151751. It came with all 24 signal pads on the
**top** layer. A clamping plug straddles the board: A-row contacts on top, B-row contacts underneath.
So I edited `imports/TYPE_C_24P_GTJB_040.tsx` to put pins 27–38 (B1–B12) and pad 25 on the bottom
layer. I also stripped its silkscreen outline and courtyard because they described the plug body,
which hangs off the board and was tripping the overlap checker. **This edit is the highest-risk
thing in the design**, see §5.1.

Pad geometry as built (from `NETLIST.txt`): 12 pads per row, 0.30 × 1.50 mm, 0.5 mm pitch, centered
at x = −13.95, spanning y = −2.75…+2.75. Board edge is at x = −15.0, so the pads run from 0.30 mm to
1.80 mm in from the edge. The plug drawing (page 2, "Cable Side PCB Layout, T=0.80±0.05mm") shows a
12×1.50 pad pattern at 0.50 pitch with a 0.90 and a 1.30 dimension near the edge that I could not
read with confidence at the resolution I had. **Reviewer: open the PDF at full size and confirm
where the pads should sit relative to the board edge.** If the drawing says pads start 0.9 mm from
the edge, we are 0.6 mm too close and `pcbX` of J1 must move from −13.95 to about −13.35 (and the
board can stay 30 mm).

### 3.4 MCP2221A wiring (checked pin by pin against DS20005565C, TSSOP-14 pinout, §1)
| Pin | Name | Ours | OK? |
|---|---|---|---|
| 1 | VDD | VBUS + C2 100 nF to GND | ✓ |
| 2 | GP0 | open | ✓ (default function SSPND/LED_URX output; unused) |
| 3 | GP1 | open | ✓ |
| 4 | RST | 10 k to VBUS | ✓ active-low reset, pulled high |
| 5 | URX | open | ✓ UART unused |
| 6 | UTX | open | ✓ |
| 7 | GP2 | open | ✓ |
| 8 | GP3 | LED2 cathode (anode via 1 k to VBUS) | ✓ see §3.5 |
| 9 | SDA | net SDA, 4.7 k to VBUS | ✓ |
| 10 | SCL | net SCL, 4.7 k to VBUS | ✓ |
| 11 | VUSB | 470 nF to GND | ✓ required |
| 12 | D− | J1 B7 | ✓ |
| 13 | D+ | J1 B6 | ✓ |
| 14 | VSS | GND | ✓ |

D+/D− polarity: verified against the plug pin table (A6/B6 = D+, A7/B7 = D−) and the MCP2221A pinout
(12 = D−, 13 = D+). Swapped D± is the classic "enumerates as nothing" bug; worth a second look.

### 3.5 The blue LED is wired "backwards" on purpose
GP3's factory-default function is LED_I2C (EasyMCP2221 docs list it as the default; DS20005565C
says the pin takes the *negated* value of the activity bit, i.e. it pulses **low** during traffic).
Microchip's ADM00559 wires its LEDs from VDD through a resistor into the GP pin. So: LED2 anode →
R6 1 k → VBUS, LED2 cathode → GP3. It lights when GP3 goes low = during I2C traffic. v0.2 had it the
other way round (would have been on at idle, blinking off). If GP3's default in this chip lot is
plain GPIO instead, the LED just stays off; Microchip's free utility can set it.

### 3.6 ATECC608B wiring (DS40002239A, SOIC-8)
Pin 4 GND, 5 SDA, 6 SCL, 8 VCC (+ C3 100 nF). Pins 1–3, 7 NC, left open. I2C address 0x60 (write
0xC0). Matches `imports/ATECC608B_SSHDA_T.tsx` and the picowallet build that already works with this
chip.

### 3.7 Board size and layout
30 × 12 × 0.8 mm, 2 layers. The left 13 mm is inside the plug shell. U1 and U2 on the front, every
passive and both LEDs on the back. Austin asked why it's this big: the honest answer is the floor is
about 26 × 10 (plug shell width 8.5, two chips 5+5 wide side by side) and I left ~4 mm of slack
around the LEDs and between the chips for routing. Making it smaller doesn't change function.
Board thickness 0.8 mm is forced by the plug (§3.2); 0.8 mm is a standard JLCPCB option.

### 3.8 Routing
Autorouted by tscircuit (2 layers, vias allowed). 37 traces, 15 vias. `check shorts` clean. Trace
width is the default 0.15 mm, which is fine for < 100 mA. The VUSB cap traces carry an explicit
`maxLength="6mm"` because the tool imposed a 1 mm rule from the chip's decoupling hint that the
layout can't meet; actual length is ~4.4 mm, well within Microchip's "close to the pin" guidance.

## 4. Things I changed my mind on (so the reviewer sees the trail)
1. **v0.1 → v0.2:** 40 × 14 → 30 × 12 mm, passives moved to the back. No electrical change.
2. **v0.2 → v0.3:** CC moved from B5 to A5 (USB-IF plug rule). LED2 inverted to match LED_I2C's
   active-low behaviour. Both routed first try.
3. **Plug pad layers:** import had all 24 on top; hand-moved the B row to bottom (§3.3).
4. **Dropped B6/B7 duplicates then re-added as the only data pins:** first attempt wired A6/A7 *and*
   B6/B7; router failed on the A row; settled on B row only.

## 5. Risks, ranked by "would this make the first board dead"
1. **Plug pad-to-edge distance (§3.3).** Unverified against the drawing. If wrong, the plug's spring
   contacts miss the pads → no power, dead stick. Fix is a number in `index.circuit.tsx`.
   **Do not order until a human has checked this.**
2. **Plug pad layer assignment (§3.3).** My hand edit assumes A row = top of board = the side the
   shell's A-row contacts touch. If the plug is meant to be mounted the other way up, A and B swap.
   Consequence: CC ends up on B5 (works anyway, see §3.2) and power/data on the A row (also works).
   So even if wrong, it probably still works. Low impact.
3. **D+/D− swap (§3.4).** Checked twice. Consequence if wrong: not enumerated.
4. **Only one plug row wired (§3.2).** Believed harmless for USB 2.0 at < 100 mA.
5. **RST pull-up (§3.4).** Present. If the chip also has an internal one, no harm.
6. **No ESD protection** on D+/D−. Bench use is fine; add a USBLC6-2SC6 in v1 before giving these to
   people.
7. **Blue LED** depends on GP3 default (§3.5). Cosmetic.
8. **JLCPCB assembly of the plug:** "high difficulty" + fixture fee; the plug is placed by the SMT
   line and the board edge slides into it. If JLCPCB refuses to place it, it's a 30-second hand job
   with the clamp, or they hand-solder it for the through-hole fee.
9. **Not electrically tested.** Passed netlist, placement and shorts checks in tscircuit only. Nobody
   has powered one. KiCad ERC/DRC on `kicad.zip` would be a cheap second check.

## 6. What "works" means on arrival (bring-up)
1. Plug in. Green LED on. `lsusb` / System Information shows "Microchip MCP2221 USB-I2C/UART Combo".
2. `pip install EasyMCP2221`, then in Python: `d = EasyMCP2221.Device(); d.I2C_speed(100000);
   d.I2C_write(0x60, b'\x00'); d.I2C_read(0x60, 4)` — an ATECC wakes on the low pulse and answers
   0x04 0x11 0x33 0x43. Blue LED flickers during this.
3. Port `firmware/atecc.py` (already speaks the ATECC wire protocol) from MicroPython `machine.I2C`
   to EasyMCP2221's `I2C_read/I2C_write`: `info`, `random`, `genkey`, `sign`.
4. Verify a signature with the same P-256 code the picowallet app uses.

## 7. Cost (estimate; JLCPCB quote decides)
Parts ≈ $3/board. 5 bare 0.8 mm boards $4. Standard assembly setup ~$50 + plug fixture ~$17 +
feeders 5 extended types × $3. **≈ $110 for 5**, plus shipping and US tariff. Nothing to buy
separately; the stick is complete when it arrives.

## 8. Ask for the reviewer
- Read `ref/usb-c-plug-*.pdf` page 2 and settle §3.3 (pad-to-edge) and §5.2 (which row is up).
- Re-derive every row of `NETLIST.txt` against `ref/MCP2221A-datasheet.pdf` §1 pinout and
  `ref/ATECC608B-datasheet.pdf`.
- Open `kicad.zip` in KiCad and run ERC + DRC.
- Tell me anything a first-timer would get wrong that isn't in §5.

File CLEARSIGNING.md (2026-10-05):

# Wire format, verifiable signing, clear signing, batching

Research notes, 2026-09-21. What the standards say, what the reference signers do, and what
that means for picowallet. Sources at the bottom.

## 1. github.com/ethereum/ethereum-app

Not the Ledger app. It is the "Universal Ethereum Signer": a Rust reference implementation for
hardware signers with a few hundred KB of RAM, built on alloy, targeting the Foundation Passport
Prime (KeyOS) and the Def Con 34 badge (Xous). Apache-2.0, 51 commits, written "fully by
automatic programming", not audited.

What it does:

- **Transport is ERC-4527 QR codes only** (airgapped). Requests come in as `eth-sign-request`,
  answers go out as `eth-signature`. No USB, no BLE. "Other bearers" are listed as future work.
- **Verifiable Signing (ERC-8213), no clear signing.** The device shows the raw fields it can
  parse plus standard digests. It depends on no token list, no descriptor registry, no oracle.
  Clear signing (ERC-7730) is "optional, later, with third-party dependencies".
- Supported payloads: legacy tx, EIP-1559 (type 2), EIP-7702 (type 4), EIP-712 JSON, EIP-191
  `personal_sign`. Screens: From, To, Amount, Chain id, Max fee (`gas * price`), and for
  calldata the raw hex plus the Calldata Digest as text and as a QR.
- Fail-closed checks worth copying: the envelope `chain-id` must equal the chain id inside the
  RLP body; the optional `address` in the request must equal the derived signing address; the
  legacy EIP-155 unsigned trailer must be `chain_id, 0, 0`; the check runs at decode and again
  right before signing.
- The DC34 badge has its own minimal UR decoder: bytewords, CRC-32, pure fountain parts only
  (`K-N` parts, no mixed parts), caps of 8 KB per message and 256 parts. A browser tool
  (`tools/ur-bridge.html`) re-cuts animated QRs into single frames because the badge camera is
  slow. Test vectors in `dc34-app-eth-signer/tools/test-vectors.json`.

Crate layout (`common-eth-signer/crates`): `core` (types + ERC-8213 digests), `decoding` (CBOR
request → typed request, RLP tx decode), `signing` (BIP-39 → key, signing hash, 65-byte `r‖s‖v`),
`displaying` (pure view model, headless/console/Slint backends), `device` (the flow).
`decode → derive key → verify address → build view model → confirm → sign → encode`.

## 2. The wire formats in play

### ERC-4527 (QR, Keystone/Passport style)

CBOR maps, wrapped in BC-UR for QR. Request `eth-sign-request`:

| key | field | notes |
|---|---|---|
| 1 | request-id | 16-byte UUID, echoed back |
| 2 | sign-data | bytes: unsigned RLP for a tx, UTF-8 JSON for EIP-712, raw bytes for 191 |
| 3 | data-type | 1 legacy tx, 2 EIP-712, 3 raw bytes (191), 4 typed tx (0x02/0x04) |
| 4 | chain-id | optional envelope hint, must match the body |
| 5 | derivation-path | crypto-keypath |
| 6 | address | optional, 20 bytes, signer must check it |
| 7 | origin | wallet name |

Answer `eth-signature`: `{1: request-id, 2: r‖s‖v (65 bytes), 3: origin}`. `v` conventions:
legacy EIP-155 full `chainId*2+35+parity`, typed txs bare parity, 191/712 `27/28`.

### Ledger APDU (USB HID / BLE)

`CLA E0`, one byte INS, P1/P2, up to 255-byte chunks with P1 `00` first / `80` next. Every
sign command starts with the BIP-32 path (count byte + 4-byte indexes). Answer is `v, r, s`.
INS worth knowing: `02` get address, `04` sign tx (RLP streamed), `08` personal message,
`0C` sign EIP-712 (V0 takes domain hash + message hash, V1 hashes on device after
`1A` send struct definition / `1C` send struct implementation / `1E` filtering), `26`
transaction info + `28` field description (generic clear signing), `34` sign EIP-7702
authorization (TLV, returns parity r s), `36` provide Safe account, `32` tx simulation.

### Ours (USB.md)

JSON lines over USB serial. `sign` carries the app's request object: `kind`, chain, account,
nonce, deadline, the kind's raw fields, and display hints. The wallet rebuilds the EIP-712
digest from the raw fields with a hard-coded schema (`firmware/eip712.py`, four typehashes),
refuses on mismatch, and shows a blockie of the digest plus its first 8 hex.

That is already a form of both things below: verifiable signing (we show the EIP-712 Digest)
and clear signing (the four kinds are rendered as words, not hex) with the descriptor baked
into firmware. The gaps are naming, completeness, generality and batching.

## 3. Verifiable signing: ERC-8213

Draft ERC by Patrick Collins, 2026-03-30. Five names, exact formulas, and display rules.

| term | value |
|---|---|
| ERC-191 Digest | `keccak("\x19Ethereum Signed Message:\n" ‖ len ‖ message)` |
| EIP-712 Digest | `keccak("\x19\x01" ‖ domainSeparator ‖ hashStruct(message))` (Safe calls this safeTxHash) |
| Domain Hash | `hashStruct(eip712Domain)` |
| Message Hash | `hashStruct(message)` |
| Calldata Digest | `keccak(uint256(len(calldata)) ‖ calldata)`, no chain id, no `to`, no value |

Rules: show the EIP-712 Digest alone (recommended) or Domain + Message together, never one of
the pair alone. Label them with exactly these names. Show as `0x` hex. For a tx with calldata,
show the Calldata Digest. The spec warns that comparing only a prefix or suffix is grindable
by an attacker, and that the Calldata Digest does not cover `to` or `value`, so those must be
shown too.

Test vectors: `"hello"` → ERC-191 Digest `0x50b2c43f…7750`; the 68-byte ERC-20 `transfer`
calldata in the spec → Calldata Digest `0x812cee5d…9985`.

Ledger Nano S made Domain Hash / Message Hash well known. Safe exposes safeTxHash. The idea is
that a second tool (script, other device) recomputes the digest and you compare.

## 4. Clear signing: ERC-7730 and how Ledger ships it

ERC-7730 is a JSON descriptor per contract or per EIP-712 domain: `context` (which chain +
address, or which domain it binds to), `metadata` (owner, token info, enums, constants), and
`display.formats` keyed by the ABI signature (`transfer(address to,uint256 value)`) or the
EIP-712 `encodeType`. Each format has an `intent`, an optional `interpolatedIntent` sentence
with `{path}` holes, and ordered `fields` with a `format`: `raw`, `amount`, `tokenAmount`,
`addressName`, `date`, `duration`, `enum`, `nftName`, `calldata` (nested call), and so on.
`visible: {mustMatch}` turns a field into a constraint the wallet enforces.

The public registry is github.com/ethereum/clear-signing-erc7730-registry. Every file has a
detached signature in `sigs/` from `0x3846…31f6`, so a wallet can trust a descriptor without
trusting the host that delivered it.

Ledger does not parse JSON on the device. The host (Ledger Live) turns the descriptor into
signed TLV structs and streams them before the sign command ("generic clear signing", GCS):

1. `SIGN, store only`: the device keeps the calldata compressed in RAM.
2. `TRANSACTION INFO`: chain id, contract, selector, intent, creator, and a `FIELDS_HASH`, all
   signed by Ledger's key.
3. One `TX FIELD DESCRIPTION` per field: name, param type, and where in the calldata the value
   lives. Plus token / NFT / enum / trusted-name metadata as needed, each also signed.
4. `SIGN, start flow`: the device hashes the fields it received, checks it against the signed
   `FIELDS_HASH`, renders every field, then signs.

So the trust anchor is a pinned public key on the device, and the host is only a courier. That
is the pattern to copy if we ever accept descriptors from the website.

Nested calldata: a field of param type `CALLDATA` names the callee, optional chain id,
selector, amount and spender; the device pushes a nested context and takes another
`TRANSACTION INFO` + fields for the inner call. Ledger documents "limitations" for recursive
formatters and a fallback to blind signing.

## 5. Batching

### EIP-5792 (the app-to-wallet API)

`wallet_sendCalls({version, chainId, from, atomicRequired, calls: [{to, data, value}], capabilities})`.
The wallet must send the calls in order, on that chain, from that account, and reject if it
cannot honour `atomicRequired`. Status via `wallet_getCallsStatus` (100 pending, 200 ok,
500 reverted). The atomic capability is `supported | ready | unsupported`; `ready` means "an
EOA that can upgrade via 7702 with user consent". Nothing says how the wallet executes.

### ERC-7821 (the on-chain shape)

The minimal batch executor that 7702 delegations and smart accounts converge on:

```
struct Call { address to; uint256 value; bytes data; }
function execute(bytes32 mode, bytes calldata executionData) external payable;
function supportsExecutionMode(bytes32 mode) external view returns (bool);
```

`mode` is the ERC-7579 layout: byte 0 `0x01` batch, byte 1 `0x00` revert on failure, bytes
6..9 `0x00000000` (no opData), `0x78210001` (`abi.encode(calls, opData)`), `0x78210002`
(batch of batches). `opData` is the slot for a signature, and the spec says: empty opData
means `msg.sender == address(this)`, non-empty means authorize by the signature inside.
`to == address(0)` may mean self. Frontends probe `supportsExecutionMode(0x01…00)`.

### EIP-7702

A signed authorization `(chain_id, address, nonce)` puts delegation code on an EOA. Ledger
signs it from a TLV over INS `34`, only for delegate contracts on a per-chain whitelist, only
when the setting is on, and treats `address(0)` as revocation. Not relevant to our key: 7702
needs a secp256k1 EOA signature and our signer is a P-256 key behind a contract account.
Our batching lives in ChipAccount, which is the smart-account case 5792 already covers.

### Clear-signed batching (ERC-7730 + Ledger)

The spec gives two ways to show a 5792 batch:

- Join each call's `interpolatedIntent` with `" and "`: "Approve Uniswap Router to spend 1000
  USDC and Swap 1000 USDC for at least 0.25 WETH". Fall back to per-call `intent` if any
  interpolation fails.
- Or show one screen group per call, using `intent` + required fields, "clearly separating
  individual transactions". The spec calls this the option for space-limited wallets.

On the wire it is just nested calldata over an array. The registry's Safe BatchExecutor
descriptor is the whole thing:

```json
"batchExecute((address to, uint256 value, bytes data)[] calls)": {
  "intent": "Batch transactions",
  "fields": [{ "path": "calls.[].data", "label": "Transaction", "format": "calldata",
               "params": { "calleePath": "calls.[].to", "amountPath": "calls.[].value" } }]
}
```

The wallet walks the array, and for each element resolves a descriptor by `(callee, selector)`
and renders that call with its own intent and fields. Ledger's `PARAM_CALLDATA` TLV allows the
callee / amount / spender to be a one-element array that gets broadcast across all calls.

## 6. What this means for picowallet

Where we stand: a hard-coded EIP-712 schema, digest recomputed on device, digest shown as a
blockie + 8 hex, four request kinds, no batch, hints never hashed. Good bones. Gaps, in the
order I would close them:

1. **Name and finish the digest screen (ERC-8213).** Label it "EIP-712 Digest". Put the full
   `0x` hex on the details page (four chunks like the address), keep the blockie as the quick
   check. Eight hex chars alone is exactly the prefix-grinding case the ERC warns about. For
   `execute`, also show the Calldata Digest of `data` (`keccak(len‖data)`, a few lines in
   `eip712.py`). The website shows the same values so they can be compared, and any script can
   recompute them. Cheap, no new trust.

2. **Send the typed data, not the kind.** Today the app sends `kind` + fields and the wallet
   has one hasher per kind. If the app sent the full EIP-712 JSON (ERC-4527 data-type 2) and
   the wallet had a small generic `hashStruct` (types, arrays of structs, `bytes`/`string`
   hashed), any new ChipAccount type works without a firmware change, and the four pretty
   screens become a display layer keyed by primary type. That is the split every reference
   signer uses: generic hashing under, descriptor-driven rendering over. Our typed data is
   tiny, so hashing from JSON fits in the ~52 KB the pink boards have spare. Unknown primary
   type → show domain + raw fields + the digests (verifiable signing fallback), never refuse.

3. **Batch in the contract, ERC-7821 shape.** Add to ChipAccount:
   `execute(bytes32 mode, bytes executionData)` with `executionData = abi.encode(Call[] calls, bytes opData)`
   and `opData = abi.encode(deadline, r, s)`, plus `supportsExecutionMode`. The signed struct:
   `ExecuteBatch(Call[] calls,uint256 nonce,uint256 deadline)Call(address target,uint256 value,bytes data)`
   (EIP-712 arrays of structs hash as `keccak(concat(hashStruct(each)))`). Standard shape means
   viem / 5792 tooling can build the calls, the relay just wraps them, and the 7730 Safe
   BatchExecutor descriptor above is our descriptor with the names changed. Keep the old
   `executeTransfer` for the single-transfer path. Cap calls on device (say 8 calls, 4 KB of
   calldata total) and hash `data` streaming, do not hold decoded copies.

4. **Clear-signed batching on the 240×240 screen: per-call pages, not the "and" sentence.**
   Page 0: "Batch of N calls", vault, chain, nonce, deadline. Pages 1..N: callee (name hint
   small, full address in chunks), value, and the call decoded if the selector is one we know
   (ERC-20 `transfer` / `approve`, the USDS we already pin), else "unknown call" with its
   Calldata Digest. Last page: the batch's EIP-712 Digest blockie + full hex. The website
   renders the same pages so the compare-two-screens habit still works. Joystick left/right
   walks the calls; A only on the last page.

5. **Descriptors: pin or sign, never trust the host.** Bake the ChipAccount + ERC-20
   descriptors into firmware for now. If we ever load ERC-7730 files from the website, do what
   Ledger and the registry do: a signature from a key pinned in `secrets.py`, checked on
   device, or the descriptor is treated as a hint and the raw fields plus digests are shown
   regardless. Our existing rule stands: hints are drawn small and never hashed.

6. **ERC-4527 as an optional envelope.** We have a QR renderer and no camera, so full QR
   transport is one-way. But accepting the `eth-sign-request` CBOR map inside our USB `sign`
   message (or as the whole payload) costs a small CBOR reader and buys compatibility with any
   Keystone / Passport-style host. Low priority. The EIP-712 JSON path in point 2 is the part
   that matters.

Not worth doing: 7702 (no secp256k1 EOA here), Ledger's struct-definition APDUs (our messages
are small enough to hash from JSON), tx simulation.

## Sources

- ethereum/ethereum-app: README, `verifiable_signing/README.md`, `common-eth-signer/crates/*`,
  `dc34-app-eth-signer/src/ur.rs`, `dc34-app-eth-signer/tools/test-vectors.json`
- ERC-8213 draft: https://github.com/ethereum/ERCs/pull/1639 and https://erc8213.eth.limo
- ERC-4527: https://eips.ethereum.org/EIPS/eip-4527
- ERC-7730: https://eips.ethereum.org/EIPS/eip-7730 and
  https://github.com/ethereum/clear-signing-erc7730-registry (`specs/erc-7730.md`,
  `registry/safe/calldata-BatchExecutor.json`)
- EIP-5792: https://eips.ethereum.org/EIPS/eip-5792
- ERC-7821: https://eips.ethereum.org/EIPS/eip-7821
- Ledger app-ethereum: `doc/apdu.md`, `doc/gcs.md`, `doc/tlv_structs.md`,
  `tests/functional/doc/details/test_eip7702.md` at https://github.com/LedgerHQ/app-ethereum
- Ledger clear signing docs: https://developers.ledger.com/docs/clear-signing/overview

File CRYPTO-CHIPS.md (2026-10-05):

# Crypto chips you can buy this week

Date: 2026-10-02. Four blind searches (three Claude agents, one Codex), none told what we use.
Goal: a chip that holds a key it won't give up, on a board you can get in about a week from
Amazon, Adafruit, SparkFun, M5Stack or in-stock DigiKey, ideally no solder.

Prices and stock are from search snapshots. Recheck before buying. Where searches disagreed on
stock, both are noted.

## Signs normal Ethereum keys (secp256k1)

| What | Price | Where, stock | How it connects | Notes |
|---|---|---|---|---|
| **Arduino Portenta C33** (NXP SE050C2 on board) | $42–57 | [DigiKey](https://www.digikey.com/en/products/detail/arduino/ABX00074/21219772) 188, [SparkFun](https://www.sparkfun.com/arduino-portenta-c33.html), Arduino store | It is the board. No solder. | Replaces the Pico. Arduino's library only does P-256; secp256k1 needs NXP's lower-level C library ([NXP thread](https://community.nxp.com/t5/Smart-Cards-and-Secure-Element/Modifying-SE05X-Library-on-Arduino-Portenta-C33-for-Custom/m-p/1798526)). |
| **YubiKey 5 NFC** | $58 | [Yubico](https://www.yubico.com/product/yubikey-5-nfc/), Amazon | NFC reader on the Pico: [M5Stack NFC unit](https://shop.m5stack.com/products/nfc-universal-unit-st25r3916) $7 or [Grove NFC](https://www.seeedstudio.com/Grove-NFC.html) $16.50. No solder. | secp256k1 is in the OpenPGP app (firmware 5.2.3+), not PIV ([Yubico](https://developers.yubico.com/PGP/YubiKey_5.2.3_Enhancements_to_OpenPGP_3.4.html)). Key made on the key, attestation cert. Closed firmware. Example project: [yketh](https://github.com/mab-xyz/yketh). |
| **Satochip card** | €25 | [satochip.io](https://satochip.io/product/satochip/) | Same NFC reader | Open applet, BIP32 on the card, EAL6+ chip. |
| **Keycard** | €24–29 | [keycard.tech](https://keycard.tech/products/keycard) (stock text conflicting) | Same NFC reader | Open (MIT). Needs a secure channel (secp256k1 ECDH) done in software on the Pico. |
| Blank J3R180 JavaCards | ~$5–15 | [Amazon](https://www.amazon.com/J3R180-Magnetic-Stripe-Interface-EEPROM/dp/B0HD7Z44HJ) | Same NFC reader | Load Satochip/Keycard yourself. Buy unfused cards. |
| NXP OM-SE050ARD-E | $60 NXP, $84 DigiKey | [DigiKey](https://www.digikey.com/en/products/detail/nxp-usa-inc/OM-SE050ARD-E/16366366) 10 | 4 jumper wires | No MicroPython driver. Curve must be created on the chip first. |
| Mikroe SE051 Click | $25 | [DigiKey](https://www.digikey.com/en/products/detail/mikroelektronika/MIKROE-5392/16910358) 0–2 | Jumper wires | Almost gone. |
| Infineon Blockchain Security 2Go (5 cards) | $80 | [DigiKey](https://www.digikey.com/en/products/detail/infineon-technologies/BLOCKCHAINSTARTKITTOBO1/10279163) 4 | NFC reader | Made for Ethereum. Discontinued. |
| Nitrokey 3 / HSM 2, Token2 PIN+ | €60–109 | Their shops | USB host needed | Pico can't be a USB host easily. |

Out: Microchip TA100/TA101 (NDA), Zymkey 5 (Pi only, sold out), YubiHSM 2 ($650).

## Signs P-256 only (works with a smart account via EIP-7951)

| What | Price | Where, stock | How it connects |
|---|---|---|---|
| **SparkFun ATECC608A Qwiic** | $5.05 | [SparkFun](https://www.sparkfun.com/sparkfun-cryptographic-co-processor-breakout-atecc608a-qwiic.html), in stock | Qwiic cable |
| **Adafruit ATECC608** | $4.95 | [Adafruit](https://www.adafruit.com/product/4314) (searches disagree on stock), DigiKey | STEMMA QT cable |
| **Adafruit Trust M** | $4.95 | [Adafruit](https://www.adafruit.com/product/4351) (stock unconfirmed) | STEMMA QT cable |
| **M5Stack Unit ID** (ATECC608B, pre-set) | $5.50 | [DigiKey](https://www.digikey.com/en/products/detail/m5stack-technology-co-ltd/U124/15277428) 54. M5Stack direct ships after Oct 8. | Grove cable, address 0x35 |
| ST X-NUCLEO-ESE01A1 (STSAFE-A120, also Ed25519) | $17–18 | [DigiKey](https://www.digikey.com/en/products/detail/stmicroelectronics/X-NUCLEO-ESE01A1/26795920) 35 | Jumper wires |
| Mikroe Secure Tropic Click (TROPIC01) | $19 | [DigiKey](https://www.digikey.com/en/products/detail/mikroelektronika/MIKROE-6559/26394718) 69 | SPI, jumper wires. MicroPython: [pytropicsquare](https://github.com/petrkr/pytropicsquare). 2026 laser attack disclosed. |
| Arduino Nano RP2040 Connect (ATECC608 on board) | $21 | [Arduino](https://store-usa.arduino.cc/products/arduino-nano-rp2040-connect) | It is the board. Runs MicroPython. |
| ESP32-H2 DevKitM (P-256 key in eFuse, no extra chip) | $10 | [Adafruit](https://www.adafruit.com/product/5715) | It is the board. Weaker than a secure chip. |

## Amazon

Mostly bad for this. Bare ATECC608 boards that need solder (~$23), the Adafruit listing is
unavailable, plus TPM modules for PCs. The good Amazon buys are the **YubiKey 5 NFC** and blank
JavaCards.

## What this means for the workshop

- **Smart account:** $5 Qwiic/STEMMA ATECC608 or Trust M, or the M5Stack unit. The plug-in is
  easy; the firmware isn't ready for all of them yet:
  - ATECC608: works today (`firmware/signer.py`).
  - Trust M: driver signs (`firmware/trustm.py`), but the wallet doesn't use it yet. Needs a signer
    backend, key generation and slot lock.
  - M5Stack Unit ID: address 0x35, pre-provisioned Trust&GO slots. Our driver assumes 0x60 and our
    own config. Untested.
- **Normal Ethereum account, no solder, this week:** YubiKey 5 NFC or a Satochip card, plus a
  $7–16 plug-in NFC reader on the Pico. Or the Portenta C33 in place of the Pico.
- Every secp256k1 route needs driver work: NFC + smart-card commands for cards and YubiKeys, NXP
  C library for SE050. The host must also make `s` low and work out `v`.

## Not confirmed

- Live stock at Mouser, Mikroe, Tindie, Amazon search (blocked or timed out).
- M5Stack NFC unit range and smart-card support with a YubiKey or JavaCard.
- Raw-hash signing on YubiKey OpenPGP for Ethereum (yketh says yes; not reviewed).
- secp256k1 key storage in nRF54L15 KMU or Silicon Labs Secure Vault.

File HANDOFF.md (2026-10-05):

# HANDOFF

For the next agent, or me after a context reset. State as of 2026-09-13 morning. Plain facts, then how to
run each piece, then gotchas, then what is open. Public repo, so no secrets here; they are named
by file and location only.

## What exists and works

- A hardware wallet: Pico 2 W + Waveshare Pico-LCD-1.3 + Adafruit ATECC608 breakout, no solder.
  The ATECC is the Adafruit STEMMA QT board from the ATECC608-demo Pi, serial
  `01235e6763cc8d97ee`. Its key owns the mainnet vault. Four STEMMA cable wires are wedged into
  the LCD board's header beside the Pico pins (3V3 pin 36, GND 38, GP4 SDA pin 6, GP5 SCL pin 7).
- Mainnet vault `ChipAccount` v5 at `0x4564fA634b073AcBcA814DCA5210835EC9376324` (legacy v1 at
  `0x0336aD6afc8bE414D6BD1f7A16caEb14BCCd16e9`, do not fund), token USDS
  `0xdC035D45d973E3EC169d2276DDab16f1e407384F`. Relay/admin `0x7FE7f508A267BF45D2D161F244DbB12743e2cf49`,
  a foundry keystore named `atecc-relay` in `~/.foundry/keystores` with its password in a file
  beside it. Vault ~$41.66, nonce 10, relay ~0.001 ETH (about 80 sends) on 2026-09-06.
- Transfers done from the wallet on mainnet: 5 USDS `0x0fbd390b…`, 69 USDS `0x87638ae1…`, more.
  Each is ~82k gas.
- The repo is public at https://github.com/austintgriffith/picowallet, MIT, branch `main`.
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

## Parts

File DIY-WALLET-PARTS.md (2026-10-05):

# Building a hardware wallet at home: which parts and why

Date: 2026-10-02. Goal: a crypto hardware wallet (Ethereum first) built from parts you can buy,
with no custom PCB and little or no soldering. Prices are approximate and need a recheck before
ordering.

Status: researched by three agents, then fact-checked by Codex. Its corrections are folded in;
section 5 lists the ones that change what we do.

## 1. Start from the job

A hardware wallet does five things. Every part choice below maps to one of them.

1. **Keep the key secret**, even from the computer it plugs into and from someone who steals it.
2. **Show what you are signing** on a screen the computer can't change.
3. **Need a physical press** to sign. Malware can't press a button.
4. **Make a good key.** Bad randomness has lost real money (Coldcard, below).
5. **Let you recover** when the device is lost or broken.

What it must survive, roughly in order of how likely each one is:

| Threat | What stops it |
|---|---|
| Malware or a hacked dapp UI on the computer (Bybit, Feb 2025: $1.4B, signers blind-signed a bad delegatecall) | Trusted screen big enough to show decoded calldata, plus a physical confirm |
| Bad randomness at key creation | Mix several entropy sources, including dice |
| Theft of the device | Key in a secure chip with a PIN and a retry limit |
| Hostile computer on USB driving the device directly (REPL, debug, unsigned app code) | No REPL in the shipped build, secure boot that covers the app, no fallback key |
| Remote attack on the device itself | Small attack surface: no radio, or radio off in "vault" mode |
| Swapped or tampered parts (supply chain, evil maid) | Buy from known resellers, flash your own firmware, tamper seals |
| Lab attacks (glitching, laser) | Only partly. Keep the key out of MCU flash. No DIY build fully stops a funded lab. |

## 2. The parts

### 2.1 Key storage (the most important choice)

The question is where the private key lives, and which curve it uses. Ethereum accounts (EOAs) use
secp256k1. Most cheap secure chips only do P-256. P-256 still works on Ethereum through a smart
contract account that checks signatures with the P-256 precompile (RIP-7212 / EIP-7951).

| Option | secp256k1 | P-256 | Key never leaves chip | Rating | Hobby board | Notes |
|---|---|---|---|---|---|---|
| **Microchip ATECC608** | No | Yes | Yes | "JIL High" (Microchip's claim, no CC cert found) | Adafruit #4314 STEMMA QT, $5 | Mature drivers. Full datasheet under NDA. Config lock is permanent; a wrong config bricks it (we did this once). 608A/B are "not for new designs"; use 608C. |
| **Infineon OPTIGA Trust M** | No | Yes | Yes | Hardware is CC EAL6+ | Adafruit #4351 STEMMA QT, $5 | Docs public, no NDA. Same chip as Trezor Safe 3/5. Needs retry-on-NACK (we hit this). |
| **NXP SE050 / SE051** | **Yes** | Yes | Yes | CC EAL6+ | OM-SE050ARD-E, ~$60 | Only breakout-form chip that signs secp256k1 inside the chip. Check the exact variant's curve table. No MicroPython driver. Host must fix low-s and work out `v`. One raw key per slot, no BIP32. |
| **Tropic Square TROPIC01** | No | Yes | Yes | No CC found; fully open design | €9.50 mini board, €20 shield | SPI, not I2C. In Trezor Safe 7. Tropic disclosed a laser bypass of its boot check on all production chips. |
| **ST STSAFE-A120** | No | Yes | Yes | Platform CC EAL5+ | X-NUCLEO-ESE01A1 eval board | Board exists; wallet fit not checked. |
| **JavaCard (Keycard / Satochip applet)** | **Yes** | Yes | Yes | Chip platform EAL6+ | Blank card ~$25 + reader | Signs secp256k1 with BIP32 inside the card. Needs a card or NFC reader. Open host code exists (Keycard Shell). |
| **No secure chip** (seed in MCU flash, PIN-encrypted) | Yes (software) | Yes | No | None | $0 | Glitch or laser the MCU, copy flash, brute-force the PIN offline. Shown on RP2350 and STM32F4. |
| **Stateless** (SeedSigner style: scan seed QR each boot) | Yes (software) | Yes | Nothing stored | n/a | $0 | Stolen device gives nothing. The seed backup becomes the thing to protect. |

What commercial wallets do: Ledger (ST33, closed) and Keycard (JavaCard) sign inside the secure
chip. Trezor Safe 3/5 keep the seed encrypted on the MCU; Trust M holds a secret needed to unlock
it, behind the PIN. Coldcard, BitBox02, Passport and Keystone use similar split designs and sign
secp256k1 on the MCU. Jade has no secure chip and uses an online
"blind oracle" for the PIN.

What a secure chip actually buys you: mainly a **hardware PIN retry limit** and a key that can't be
copied. It does not stop a user signing a bad transaction, and it will sign whatever the firmware
asks. If the chip has no PIN gate, a thief can make it sign too. Ratings like EAL6+ cover the chip,
not your firmware, your PIN design or the assembled wallet.

**Pick:**
- **Smart-account wallet (our path): ATECC608 (608C if you can get it).** $5, no solder, the key
  is born in the chip and never leaves. Recovery is done by the contract, not a seed phrase.
  Trust M is the same price ($5 Adafruit breakout), EAL6+ hardware, public docs, and we already
  have its driver started. Compare it before provisioning another ATECC.
- **Plain EOA wallet: try Keycard/Satochip first.** HD keys and secp256k1 signing stay on the
  card, and open host code exists. The other route is the Trezor pattern (seed encrypted on the
  MCU, Trust M holds the unlock secret behind a PIN, secp256k1 on the MCU). That is a real
  engineering job, not a parts swap. SE050 only if you need one raw secp256k1 key in the chip and
  can accept $60 and writing the driver.

### 2.2 Main board

| Board | Security | Radio | Price | Verdict |
|---|---|---|---|---|
| **Raspberry Pi Pico 2 (RP2350)** | Signed boot, OTP keys, TrustZone, TRNG, glitch detectors, permanent debug lock | None | ~$5 | **Pick.** Best documented security on a cheap board, tested in public. |
| Pico 2 W | Same | WiFi + BLE | ~$7 | Fine for an online wallet. Bigger attack surface. |
| Pico / RP2040 | No secure boot, no TRNG | Optional | ~$4 | Only for stateless designs. Our pink boards are RP2040 clones. |
| ESP32-S3 boards | Secure Boot v2, flash encryption | WiFi + BLE always | $10–50 | Good RAM, camera boards exist. Public glitch attacks; no power-glitch detector (AR2026-005, which hits the general AES block, not flash encryption). |
| ESP32-P4 boards | Secure boot, flash encryption, power-glitch detector | None on chip (most boards add a C6) | ~$11+ | Where SeedSigner, Krux, Specter and Kern are heading for camera/QR builds. |
| STM32F469 Disco (Specter DIY) | RDP level 2 | None | ~$60 | Risky for stored keys: the unpatchable RDP glitch (Kraken vs Trezor) was shown on STM32F205/F427, same family. |
| Pi Zero v1.3 (SeedSigner) | Linux, no secure boot | None | $5–15, scarce | Stateless only. |
| K210 boards (Krux) | None | None | ~$50 | Stateless only, getting hard to find. |

RP2350 attacks to know about: the 2024–25 hacking challenge was beaten four ways, all with physical
access (voltage glitch, laser, FIB readout of OTP). Ledger Donjon (2026-09-18) used a laser on the
A4 stepping to turn debug back on and read an OTP secret; about $250K of gear and a destructively
prepared package. It worked with glitch detectors at maximum. It read the secret before firmware
locked the OTP page, so lock pages hard at provisioning, not at runtime. So: **don't keep the seed
in RP2350 OTP or flash.** Keep it in the secure chip. Still turn on the glitch detectors and buy A4
chips.

Secure boot only helps if it covers the app. Signing the MicroPython interpreter while leaving
`.py`/`.mpy` files replaceable leaves the wallet replaceable.

**Radio:** an online wallet (ours, over WiFi) accepts the radio. An air-gapped build should use the
plain Pico 2, which has no radio at all. Same code, $2 cheaper.

### 2.3 Screen

The screen is the only thing you can trust when the computer is hacked. Decoded calldata or
EIP-712 needs 6–15 label/value lines plus full addresses. ERC-7730 (clear-signing descriptors, now
with the Ethereum Foundation) is the standard to follow for decoding.

| Screen | Size | Price | Notes |
|---|---|---|---|
| Waveshare Pico-LCD-1.14 | 240×135 | $8 | Too small for EIP-712. |
| **Waveshare Pico-LCD-1.3 (current)** | 240×240 | $8 | Joystick + 4 buttons, plugs on, same panel as SeedSigner. |
| **Waveshare Pico-LCD-2.0** | 320×240 | $13 | Wider lines (full address fits), same row count in landscape. 4 buttons, no joystick. |
| Pimoroni Display Pack 2.8 | 320×240 | ~$25 | Being retired. |
| Pico-ResTouch-LCD-2.8 | 320×240 touch | $15 | Touch can't be a trusted confirm. |
| Pico-ePaper-2.9 | 296×128 | $18 | Image stays when off (leaks last screen). Slow. Fine for "receive". |
| SSD1306 OLED | 128×64 | $5 | An address doesn't fit on a line. |

**Pick:** keep the 1.3" until the review flow decodes properly. A bigger screen does not fix
clear signing; decoding does. Then move to the 2.0" for full-width addresses.

### 2.4 Input

Buttons. The "sign" button must be a GPIO read by the signing MCU, never something the host can
send. This only holds if the firmware is trusted: hacked firmware ignores any button. Use a long press to sign. Joystick or buttons are fine for PIN entry with a scrambled digit
wheel. Skip touch for the confirm.

### 2.5 Link to the computer

| Link | Works with | Attack surface |
|---|---|---|
| **QR both ways (ERC-4527 / UR)** | MetaMask and Rabby, for compatible EOA accounts | Camera, image decode, QR, UR and tx parsers. No live wire. |
| **USB WebSerial** | Chrome, Edge, Firefox 151+. Not Safari. Your own web app only. | USB stack + your parser |
| USB WebHID/WebUSB | Ledger/Trezor in Rabby; a custom device would have to fake being one | Same as above |
| WiFi (current) | Your own web app only | Whole network stack + RF. Largest. |
| BLE, NFC, microSD | Niche for Ethereum | Varies |

QR is the only open way to plug a custom device into MetaMask or Rabby, but only for secp256k1
EOAs with the account and derivation data they expect. It will not carry our P-256 contract
account. ERC-4527 is marked Stagnant. A camera with QR decoding on an RP2350 is unproven; the
working DIY camera builds use ESP32-S3/P4 or K210.

**Pick:** USB WebSerial now (no radio needed). QR is the air-gap path later, probably on an
ESP32-P4. Showing a signed QR on the screen needs no camera and is a cheap first step.

### 2.6 Randomness

Coldcard (July 2026): firmware since 2021 used MicroPython's weak PRNG for seeds, and funds were
stolen. Seeds made with 50+ dice rolls were safe. We are on MicroPython too.

- RP2350 has a hardware TRNG. MicroPython 1.26's `os.urandom` on rp2 samples the ROSC, not the
  TRNG. Newer upstream calls the SDK's `get_rand_64()`, which can use the TRNG. Pin the version
  and check it. RP2040 has no TRNG.
- ATECC608 has a tested RNG (608C noise source is FIPS 140-3 certified).

**Pick:** seed = SHA-256(RP2350 TRNG ‖ secure-chip RNG ‖ dice). Ask for 50 rolls for 12 words,
99 for 24, rolled in private. Show the device share so it can be checked. Mixing does not save you
from hacked firmware that ignores the mix, and a firmware fix does not repair an old weak seed. (For the ATECC smart-account path the chip
makes its own key, so this applies to seed-based builds.)

### 2.7 Power

USB-only if the link is USB: no battery, no Li-ion risk. A battery only matters for an air-gapped
QR build. On a Pico, use the Waveshare Pico-UPS-B ($14, stacks on, no solder, has a fuel gauge).
It does not fit ESP32 boards; those need their own battery option.

### 2.8 Case and tamper evidence

3D-printed case. Glitter nail polish over screws and seams, photographed and compared before use
(glitter has been beaten; use dense multicolour glitter in recessed holes). Epoxy potting slows
probing but blocks reflashing; only for a finished build.

Supply chain: buy from Raspberry Pi approved resellers, Digi-Key or Mouser. Check chip markings and
the Pico's chip stepping. Read the ATECC serial and certificate. Flash your own firmware. That last
one is the big advantage of DIY: you know what code is running.

## 3. Recommended builds

**A. Smart-account wallet (what we have, tuned). Next prototype.** ~$30.
Pico 2 + Pico-LCD-1.3 + ATECC608 or Trust M STEMMA QT + 3D case. USB WebSerial. P-256 key made in
the chip; the vault contract handles recovery. Order of work: remove the REPL and software-key
fallback, secure boot that covers the app, decode approvals properly, tested PIN enforcement.
Then plain Pico 2 (no radio) and the 2.0" screen.

**B. Plain EOA wallet. Harder than it looks.** ~$35–60.
First choice: Pico 2 + screen + Keycard/Satochip card and reader, keys and signing on the card.
Second: Pico 2 + Trust M, Trezor-style (seed encrypted on the MCU, Trust M holds the unlock secret
behind a PIN), secp256k1 on the RP2350. Needs a reviewed PIN design, hardened secp256k1 code and
RAM clearing. Trust M and TROPIC01 are not drop-in swaps for each other.

**C. Air-gapped QR wallet. Research project.** ~$40–60, estimate.
ESP32-P4 camera board with no radio companion + Trust M + a battery that fits that board. secp256k1
EOA over ERC-4527 QR. Prove camera/UR speed, clear signing and real MetaMask/Rabby compatibility
before calling it a wallet.

For real money, use any of these as one signer in a multisig, not the only key.

## 4. Gaps in our current build

The biggest risk today is someone making the device sign, not someone pulling the key out.

1. **REPL is open over USB.** `firmware/usbwallet.py` keeps Ctrl-C to the REPL. A hostile computer
   can run code and skip the buttons.
2. **Software-key code is still in the build.** `firmware/signer.py` `load()` returns a software
   key if the chip doesn't answer. By default the wallet then stops in "no chip" and won't sign
   (`wallet.py`, `usbwallet.py`); it only signs with it if `ALLOW_SOFT_KEY` is set. Remove it anyway.
3. **No PIN on the ATECC signing slot.** A thief can make the chip sign, and the 14-day recovery
   delay doesn't help: chip-signed spends go through right away. The slot config is locked, so
   adding a PIN means a new chip, a new key and moving the vault's signer. A PIN gate also needs a
   retry counter, protected PIN derivation and an authenticated bus, not just `ReqAuth`.
4. **Approvals aren't decoded.** USB mode labels transfer/approve selectors but doesn't show the
   recipient, spender or amount, and allows signing from the summary page.
5. **The blockie check proves consistency, not intent.** A hacked host can send a bad request with
   a matching digest and blockie.
6. **No secure boot, glitch detectors or debug lock** set on the RP2350.
7. **WiFi build** is the largest attack surface. USB mode exists.
8. **Pink RP2040 boards have no TRNG and no secure boot.** OK only because the key is made in the
   ATECC.

## 5. Blind check

The research above was given our current parts, so it may have anchored on them. Two fresh runs
got only the question: "build a hardware wallet from off-the-shelf parts, what do you pick?"

| | This report | Blind Claude | Blind Codex |
|---|---|---|---|
| Board | Pico 2 | Pico 2 (no WiFi) | Pi Zero v1.3 (SeedSigner) |
| Key | P-256 key made in ATECC608/Trust M, smart account | Seed encrypted on Pico; TROPIC01 holds an unlock share behind a PIN | Stateless: seed scanned each use, nothing stored |
| Signing | In the secure chip | secp256k1 on the Pico | On the Pi |
| Screen | Waveshare 1.3" | Waveshare 1.3" | Waveshare 1.3" HAT |
| Link | USB | USB | QR camera |
| Chain | Ethereum | Any | Bitcoin only ("Ethereum decoding is too big a job for DIY") |

All three agree:
- no radio
- same 240×240 Waveshare screen
- don't trust MCU flash alone
- cheap secure chips can't sign secp256k1
- use it as one key in a multisig for real money

Where we differ: neither blind run thought of a P-256 smart account. That is the one idea that
lets a $5 chip sign everything inside the chip, with no seed at all. The cost is it only works with
our contract, not MetaMask/Rabby.

Missed by this report, added from the blind runs:
- **ATECC608A has a published laser attack** (Ledger Donjon, SSTIC 2021). It read a stored data
  slot (Coldcard's PIN hash), building on 2020 work on the 508A. It did not show pulling out a
  signing-only private key, and it didn't test the 608B. Fine as one layer, not the only one.
- **Nonce covert channel:** hacked firmware can leak the key through valid-looking signatures, even
  air-gapped. Fix is anti-klepto (host adds randomness to the nonce). Doesn't apply when the
  secure chip makes the nonce itself, as on the ATECC.

### Ethereum-only blind runs

Same test, with "Ethereum" in the question and "consider every account model".

| | Blind Claude (ETH) | Blind Codex (ETH) |
|---|---|---|
| Board | Pico 2 (no WiFi) | ST NUCLEO-U575ZI-Q (STM32U5, TrustZone) |
| Key chip | NXP SE050E (secp256k1 + P-256) | NXP SE050E |
| Screen | Waveshare Pico-LCD-2.0 | Adafruit 3.5" 480×320, wired by hand |
| Link | USB WebSerial | USB |
| Cost | ~$110 | ~$200, needs soldering |
| Account | Seed in SE050 behind a PIN, plus a non-exportable SE050 key as a Safe owner | Prefers non-exportable device key + smart account recovery; EOA as a fallback |

What they add:
- **SE050** is the blind pick for Ethereum because it does both secp256k1 and P-256. It costs ~$60–84.
- **Encrypt the wire to the key chip** (SE050 SCP03; rotate NXP's published default keys).
  TROPIC01 has an encrypted channel built in.
- **EIP-7702:** refuse chainId 0 authorizations and only allow known delegate contracts.
- **Dark Skippy:** replaced firmware can leak a seed in two signatures. Lock firmware updates.
- **Codex independently prefers our model:** a key that never leaves the chip, with recovery done
  by the smart account.

## 6. What Codex changed

- Ledger is not the only wallet that signs inside the secure chip; Keycard does too.
- Trezor stores the seed encrypted on the MCU, not inside Trust M.
- Trust M has a $5 Adafruit breakout; STSAFE-A120 has an eval board.
- TROPIC01 has a disclosed laser boot bypass.
- MetaMask/Rabby QR won't carry our P-256 account. ERC-4527 is Stagnant.
- MicroPython's RNG behaviour depends on the version.
- A bigger screen doesn't fix clear signing; our approve screen needs decoding first.
- Added the REPL, fallback-key and recovery-delay gaps.
- Builds B and C downgraded from "recommended" to "harder than it looks" and "research".

## 7. Not confirmed

- A real CC certificate for the ATECC608 ("JIL High" is Microchip's own claim).
- Whether SE050F's FIPS mode covers secp256k1 (NXP's table lists Koblitz curves for SE050F2).
- SE050 low-s / `v` handling (from the spec, not tested).
- MicroPython drivers for SE050, TROPIC01 or a JavaCard host.
- Camera + QR decode on an RP2350.
- Exact prices.

## 8. Sources

Secure chips: [Trust M](https://github.com/Infineon/optiga-trust-m-overview) ·
[SE050 APDU spec AN12413](https://www.nxp.com/docs/en/application-note/AN12413.pdf) ·
[NXP forum: SE050 secp256k1](https://community.nxp.com/t5/Secure-Authentication/ECDSA-secp256k1-curve-key-pair-can-be-stored-in-SE050/td-p/1814983) ·
[TROPIC01 datasheet](https://download.mikroe.com/documents/datasheets/TROPIC01_datasheet.pdf) ·
[Tropic devkits](https://www.tropicsquare.com/tropic01-samples) ·
[ATECC608C summary](https://ww1.microchip.com/downloads/aemDocuments/documents/SCBU/ProductDocuments/DataSheets/ATECC608C-CryptoAuthentication-Summary-Data-Sheet-DS40002513.pdf) ·
[Adafruit 4314](https://www.adafruit.com/product/4314) ·
[Trezor secure elements](https://trezor.io/learn/security-privacy/how-trezor-keeps-you-safe/secure-elements-in-trezor-safe-devices) ·
[Satochip DIY](https://satochip.io/build-your-own-satochip-hardware-wallet/) ·
[Keycard applet](https://github.com/keycard-tech/status-keycard) ·
[Coldcard FAQ](https://coldcard.com/docs/faq/) ·
[Passport security](https://github.com/Foundation-Devices/passport2/blob/main/SECURITY/SECURITY.md) ·
[Jade blind oracle](https://help.blockstream.com/hc/en-us/articles/9639949755673-How-does-Blockstream-Jade-s-oracle-enforced-PIN-protection-work)

Boards and attacks: [RP2350 security paper](https://pip-assets.raspberrypi.com/categories/1260-security/documents/RP-009377-WP-1-Understanding%20RP2350_s%20security%20features.pdf) ·
[RP2350 challenge results](https://www.raspberrypi.com/news/security-through-transparency-rp2350-hacking-challenge-results-are-in/) ·
[RP2350 A4](https://www.raspberrypi.com/news/rp2350-a4-rp2354-and-a-new-hacking-challenge/) ·
[Ledger Donjon on RP2350](https://donjon.ledger.com/blog/rp2350-secure-debug-laser-fault-injection/) ·
[Espressif AR2023-005](https://www.espressif.com/sites/default/files/advisory_downloads/AR2023-005%20Security%20Advisory%20Concerning%20Bypassing%20Secure%20Boot%20and%20Flash%20Encryption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) ·
[Espressif AR2026-005](https://documentation.espressif.com/AR2026-005_Security_Advisory_Concerning_AES_Key_Recovery_Using_Voltage_Fault_Injection_on%20ESP32-S3_EN.html) ·
[Kraken vs Trezor](https://www.theblock.co/post/54631/kraken-security-labs-hackers-can-exploit-trezor-hardware-wallets-with-only-15-minutes-of-physical-access-to-the-device)

DIY projects: [SeedSigner](https://seedsigner.com/hardware/) ·
[Specter DIY](https://github.com/cryptoadvance/specter-diy) ·
[Krux](https://github.com/selfcustody/krux) ·
[Jade DIY](https://github.com/Blockstream/Jade/blob/master/diy/README.md) ·
[Kern](https://github.com/odudex/kern) ·
[Keycard Shell](https://keycard.tech/en/blog/keycard-shell-radically-open-uniquely-secure) ·
[Keycard Shell firmware](https://github.com/keycard-tech/keycard-shell/)

Added by Codex: [Trust M breakout (Adafruit 4351)](https://www.adafruit.com/product/4351) ·
[STSAFE-A120 eval board](https://estore.st.com/en/x-nucleo-ese01a1-cpn.html) ·
[TROPIC01 laser bypass](https://www.tropicsquare.com/blogs/potential-bypass-of-firmware-verification-by-laser-fault-injection) ·
[SE050F curves AN12436](https://www.nxp.com/docs/en/application-note/AN12436.pdf) ·
[Firefox WebSerial](https://hacks.mozilla.org/2026/05/web-serial-support-in-firefox/) ·
[Kraken on Trezor](https://blog.kraken.com/product/security/kraken-identifies-critical-flaw-in-trezor-hardware-wallets) ·
[Coldcard PIN code](https://raw.githubusercontent.com/Coldcard/firmware/master/stm32/bootloader/pins.c)

From the blind runs: [ATECC608 laser attacks (SSTIC 2021)](https://www.sstic.org/media/SSTIC2021/SSTIC-actes/defeating_a_secure_element_with_multiple_laser_fau/SSTIC2021-Article-defeating_a_secure_element_with_multiple_laser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) ·
[Coinkite on laser faults](https://blog.coinkite.com/laser-fault-injection/) ·
[Anti-klepto (BitBox)](https://blog.bitbox.swiss/en/anti-klepto-explained-protection-against-leaking-private-keys/) ·
[Secure Tropic Click](https://www.mikroe.com/secure-tropic-click) ·
[SE050 SCP03 binding AN13013](https://www.nxp.com/docs/en/application-note/AN13013.pdf) ·
[Dark Skippy](https://darkskippy.com/) ·
[EIP-7702](https://eips.ethereum.org/EIPS/eip-7702) ·
[NUCLEO-U575ZI-Q](https://estore.st.com/en/products/evaluation-tools/product-evaluation-tools/mcu-mpu-eval-tools/stm32-mcu-mpu-eval-tools/stm32-nucleo-boards/nucleo-u575zi-q.html)

Screen, link, entropy, case: [Bybit analysis (NCC)](https://www.nccgroup.com/research/in-depth-technical-analysis-of-the-bybit-hack/) ·
[EIP-7730](https://eips.ethereum.org/EIPS/eip-7730) ·
[EIP-4527](https://eips.ethereum.org/EIPS/eip-4527) ·
[Keystone QR protocol](https://github.com/KeystoneHQ/Keystone-developer-hub/blob/main/research/ethereum-qr-data-protocol.md) ·
[Pico-LCD-2.0](https://www.waveshare.com/pico-lcd-2.htm) ·
[Pico-LCD-1.3](https://www.waveshare.com/pico-lcd-1.3.htm) ·
[Pico-UPS-B](https://www.waveshare.com/pico-ups-b.htm) ·
[Coldcard entropy write-up](https://blog.coinkite.com/entropy-technical-backgrounder/) ·
[MicroPython urandom on rp2](https://github.com/orgs/micropython/discussions/16420) ·
[Tamper evidence (dys2p)](https://dys2p.com/en/2021-12-tamper-evident-protection.html)

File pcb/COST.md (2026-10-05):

# picowallet one-board v0.2 — cost + risk (2026-09-23)

Design: `pcb/v0/index.circuit.tsx`. Fab files: `pcb/v0/fab.zip`. Live 3D: see the artifact link in the session.

## Cost, 5 boards (estimate, JLCPCB quote decides)

| Item | Note | USD |
|---|---|---|
| Parts from LCSC | Pico 2 W is $14.20 there (5× = $71). Everything else ~$2.50/board | 84 |
| Bare PCBs | 5 pcs, 2 layer, 64×46 mm | 5 |
| Assembly setup | Parts on both sides = "standard" assembly, $50 flat. One side = $0 | 50 |
| Feeder fees | 6 non-basic part types × $3 | 18 |
| Hand-soldered THT | JST plug + screen header | 6 |
| Shipping | DHL. Slow post ~$10 | 25 |
| **JLCPCB order** | 5 assembled boards | **≈190** |
| Screens | 5× 1.3" ST7789 240×240 module, Amazon | 20 |
| Batteries | 5× 500 mAh LiPo with protection, JST-PH | 30 |
| **Everything** | 5 wallets, ~$48 each | **≈240** |

Cuts: buy Picos at $7 retail and solder them ourselves (−$36). Put only joystick + 2 buttons on the front and hand-solder those (one-sided assembly, −$50). Both → order ≈ $100.

## Confidence: ~80% the first batch runs the firmware with no board fix (net-by-net review 2026-09-23)

Ordered by how much it worries me:
1. ~~Pico footprint mirrored on the back~~ **Checked.** From the back, pin 1 is top-right with USB on the right, same as a real Pico. All 40 labels match the official pinout.
2. ~~Joystick~~ **Checked** (ALPS SKRH datasheet): pin 2 = center, pin 5 = common, both wired right. Directions are diagonal on the body, so SW5 is now at 45°. Up/down/left/right → A/B/C/D is a firmware table; `firmware/keytest.py` finds it.
3. **Screen header order** GND VCC SCL SDA RES DC CS BLK. Clones vary. Check the module you buy.
4. **Slide switch**: pad 2 is the middle pad and is wired as common, standard SPDT. Datasheet PDF blocked, so by geometry + convention.
5. **WiFi**: switch + battery plug sit near the Pico antenna end. Expect range loss, not a dead radio.
6. **No battery protection on board.** Buy protected LiPos. Charge current ~235 mA (R3 = 5.1k) for the 200 mAh 402030 cell.
7. **Thickness** ~17 mm with screen on the front and Pico on the back.
8. Nobody has powered one. Passed tscircuit netlist/placement/shorts only.

## Pins (unchanged from firmware)
LCD DC/CS/SCK/MOSI/RST/BL = GP8/9/10/11/12/13 · A/B = GP15/GP17 · joystick u/d/l/r/press = GP2/18/16/20/3 · ATECC SDA/SCL = GP4/5 · VSYS ← battery via switch + SS14 · TP4056 VCC ← VBUS.

## Net-by-net review 2026-09-23 (v0.4)
Dumped the compiled netlist and checked: all 40 Pico labels vs official pinout; Pico mirror (from the back, USB right, pin 1 top-right, pin 20 top-left = a real Pico rotated USB-right); ATECC608B SOIC-8 (4 GND, 5 SDA, 6 SCL, 8 VCC); TP4056 ESOP-8 (TEMP→GND disables thermistor, CE→VCC enables, PROG 5.1k ≈ 235 mA); SS14 anode←switch, cathode→VSYS (Pico datasheet battery hookup); J1 7-pin GND VCC SCL SDA RES DC BLK; J2 pin1 BAT+. All matched. Independent agent review was started but died on a spend limit before reporting.

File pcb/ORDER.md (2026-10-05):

> SUPERSEDED: this document describes v0.7c. Use [the revised v0.8 design](picowallet-v0.8-reviewed.zip) and pcb/v0/README.md. The old cart, renders and ribbon safety instructions are not valid for the revision.

# Test order — go through the motions (v0.7, 2026-09-23)

Goal: learn the process and the real clock. 5 boards, JLCPCB assembled, zero soldering: the board arrives with every part on it, you plug in the screen and the battery. Human does every click.

## Before you upload (10 min)

1. Open the 3D page and the copper image (`v0/render/pcb.png`). Look for anything dumb.
2. `v0/bom.csv`: one row has no part number on purpose: BT1 (the battery, drawn only). JLCPCB will flag it; skip it.
3. `v0/pick_and_place.csv`: same designator. Delete it if the uploader complains.
4. Buy separately: 5× 1.3" ST7789 240×240 **7-pin** module with pin header (Amazon B09QS544FX or MakerFocus B07P9X3L7M), 5× 402030 LiPo (20×30×4 mm, ~200 mAh) with protection board and JST-PH 2.0 plug.

## Upload

1. jlcpcb.com → Order now → drop `v0/fab.zip`. 2 layers, 1.6 mm, green, HASL is fine, qty 5.
2. Tick PCB Assembly. Both sides have parts, so it's "Standard" assembly. Assemble 5. Confirm the ~$50 setup line shows.
3. Upload `v0/bom.csv` and `v0/pick_and_place.csv`. Map columns if asked (Designator, Comment, Footprint, JLCPCB Part #).
4. Parts page: every row should match an LCSC number. Skip DISP1, BT1 and BP1. If the Pico 2 W (C42394205) is out of stock, stop and tell me: that's the one part with 68 in stock.
5. Placement preview: check the Pico is on the BOTTOM side with USB at the left edge, joystick is a diamond, switch pokes out the bottom.
6. Cart: note the tariff line (DDP, prepaid). Individuals can't pick DHL now; take the fastest option offered.
7. Screenshot the final quote before paying. Write the number and the promised dates below.

## Log

| Date | Step | Note |
|---|---|---|
| 2026-09-23 | quote v0.4 | $190.83 for 5 assembled. Superseded. |
| 2026-09-23 | quote v0.7 | **$221.55** for 5 assembled (PCB $4 + PCBA $217.55). 25/25 parts matched incl. the bare panel (JLCPCB places it, $3.59 ea) and the Pico. PCB 24 h, assembly 4–5 days. Cart project "fab_Y3", PCBA SMT026092460529. Superseded. |
| 2026-09-24 | quote v0.7b | **$221.24** for 5 assembled, cart item **fab_Y4** (PCBA SMT026092462580). Fixes after seeing JLCPCB's bottom preview: Pico moved to the left edge (was 6 mm inboard), Pico rotation set to 180 in the CPL so its USB faces the edge in JLCPCB's view, BT1 placeholder stripped from BOM/CPL (JLCPCB had merged it into a 100 nF cap). fab_Y3 deleted. |
| | paid | |
| | in production | |
| | shipped | tracking |
| | arrived | days total |
| | first power-on | |

## When it arrives

1. Fold the panel ribbon under its left edge, slide it into J3, flip the latch. Lay the panel flat.
2. Power over USB with the switch OFF. Check 3V3 on the ATECC VCC pin. Flash firmware, run `keytest.py`, map joystick directions.
3. Click the LiPo into J2 (red to BAT+), switch ON, unplug USB. Does it stay up. Plug USB back in, does the TP4056 get warm (charging).

## What happened 2026-09-23 (driven by Claude in a cloned Chrome, stopped at the address form)

- JLCPCB account created via "Sign in with Google" (austin.griffith@ethereum.org). Nothing paid.
- Gerbers accepted: 2 layer, 44×68 mm, 5 pcs, $4. Standard PCBA, both sides, qty 5, parts placement confirmation on. JLCPCB adds edge rails (board becomes 78×70 panel for their line).
- BOM: 16/17 matched automatically. BT1 (drawn battery) marked "do not place". Caught one bug on their table: R3 said 5.1k but carried the 2k part number; fixed to C23186 on the site and in the design.
- Quote breakdown: setup $51.50, stencil $16.54, fixture $16.54, X-ray $8.25, feeders $17.05, components $70.51 (Pico 2 W = $58.21 of that, $11.64 each), hand-solder $3.61, SMT $1.10, misc $2. Total $190.83.
- Placement preview (top) looked right. The Bottom tab would not open in the headless browser, so the Pico-on-bottom preview is NOT visually confirmed. The Pico is in the priced parts and the assembly is "Both Sides", so it is in the job. Check the Bottom tab yourself before paying.
- Screenshots: `v0/render/jlcpcb-quote.png`, `v0/render/jlcpcb-checkout.png`.

## To finish (you, ~5 min)
1. jlcpcb.com → cart → Secure Checkout. Enter shipping address (Individual Customer).
2. Pick shipping. Read the tariff line (DDP prepaid). Expect ~$30–45 shipping + ~$50–90 tariff on top of $190.83.
3. Open the PCBA item → Component Placements → Bottom. Confirm U1 (Pico) sits USB-left.
4. Pay. Write the number and dates in the log above.

## v0.7: uploaded 2026-09-23, in the cart
Switch overhangs the edge, PWR + CHG LEDs, bare 2" panel on an FPC latch with its own backlight driver, battery moved to the back. Board 82×44. JLCPCB matched the panel as a placeable part, so it ships ON the board. Gotcha hit twice: the quote page's "Both Sides" click silently reverts to Top/Economic and drops the Pico; always re-open "Change PCB specifications", click Standard + Both Sides, and confirm the order page says "Assembly Side: Both Sides" before uploading the BOM.

## Shopping list — everything the board does NOT come with
| Item | Qty | Where | ~USD |
|---|---|---|---|
| ~~Bare panel~~ JLCPCB places it (matched, $3.59 ea). Nothing to buy. | 0 | — | 0 |
| LiPo 402030, 200 mAh, 4 mm thick, protection board, JST-PH 2.0 plug | 5 | Amazon | 25 |
| Micro-USB cable, data not charge-only | 1 | you have these | 0 |
| M2.5 screws + standoffs for the case corners | a bag | Amazon | 8 |
That's it. Zero soldering, truly: the board arrives with every part on it. Screw the screen onto 4 standoffs, plug its cable into J1, click the battery into J2, flash the firmware over USB.

## CPL gotchas learned 2026-09-24
- tscircuit writes bottom-layer rotation with a mirror convention; JLCPCB rendered the Pico (pcbRotation 180 in the design, exported as 0) with its USB pointing INTO the board. Patched to 180 in `pick_and_place.csv` after export. Always look at JLCPCB's Bottom preview for any polarized bottom part.
- A BOM row with blank value/footprint (the drawn battery) gets merged into whatever row is above it. Strip placeholder parts from BOM + CPL before upload.
- JLCPCB's Edit Order on a cart item needs a real mouse click on the row; headless it never navigated. Fresh upload + delete the old item was faster.
| 2026-09-24 | quote v0.7c | **$221.37**, cart item **fab_Y6** (PCBA SMT026092560265). Changes: backlight 27 Ω, PROG 6.2 k, latch swapped to 1 mm AFC42 (C466532) and moved to (-4.3, 0.4) so the 20.7 mm ribbon lies flat. fab_Y4/Y5 deleted. Full dossier in `pcb/dossier/`. |

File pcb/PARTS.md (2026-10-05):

# picowallet one-board v0 — parts + pin map (step 1, for approval)

Goal: the Pico 2 W + Waveshare Pico-LCD-1.3 + ATECC breakout sandwich on ONE board, built by
JLCPCB. Firmware unchanged: same GPIOs as `firmware/lcd.py` and `firmware/atecc.py`.

Every part below was found in JLCPCB's assembly catalog on 2026-09-23 via `tsci search --jlcpcb`.

## Parts

| Ref | Part | LCSC | Stock | Note |
|---|---|---|---|---|
| U1 | Raspberry Pi Pico 2 W module | C42394205 | 68 | Soldered flat on the board (castellated pads). No RF design. ~$7 each |
| U2 | ATECC608B-SSHDA-T, SOIC-8 | C1518769 | 1,146 | Same chip as the Adafruit breakout. + 2x 4.7k pull-ups, 100nF |
| SW1-4 | 6x6 tactile, A/B/X/Y | C2837531 | 720k | |
| SW5 | 5-way joystick SKRHABE010 | C139794 | 5,140 | Same ALPS part class Waveshare uses |
| J1 | 8-pin 2.54 header for a 1.3" ST7789 240x240 module | C2691448 type | many | You plug in a $3-4 Amazon module (GND VCC SCL SDA RES DC CS BLK). LCSC has no 1.3" 240x240 panel in stock; FPC version is a v1 job |
| **Battery, optional** | | | | |
| U3 | TP4056 LiPo charger | C725790 | 288k | Charges from the Pico's own USB (VBUS) |
| D1 | SS14 Schottky, battery → VSYS | C2480 | 2.8M | Standard Pico battery hookup |
| J2 | JST PH 2-pin, battery | C131337 | 298k | |
| SW6 | MSK12C02 slide power switch | C431540 | 147k | |

Not on this board: Infineon OPTIGA Trust M. LCSC has 1 in stock. Would need hand soldering.

## Pin map (unchanged from firmware)

| Function | GPIO |
|---|---|
| LCD DC / CS / SCK / MOSI / RST / BL | GP8 / GP9 / GP10 / GP11 / GP12 / GP13 |
| Buttons A / B / X / Y | GP15 / GP17 / GP19 / GP21 |
| Joystick up / down / left / right / press | GP2 / GP18 / GP16 / GP20 / GP3 |
| ATECC SDA / SCL | GP4 / GP5 (I2C0) |

Buttons and joystick switch to GND, internal pull-ups, as today.

## Board

- About 60 x 30 mm, 2 layers, all parts on the top side (keeps JLCPCB's cheap one-side assembly).
- Display module plugs into J1 and sits above the Pico, like the Waveshare sandwich does now.
- Two M2.5 mounting holes for a printed case.

## Cost guess, 5 boards assembled

Roughly $85-100 without battery, $100-120 with. Most of it is 5 Pico modules (~$35) and
JLCPCB's ~$3 per unique non-basic part (~8-9 of them). Real number comes from the quote you see
when you upload.

## Decide

1. Battery parts in v0: yes / no
2. Display as plug-in module on a header (recommended) vs FPC connector
3. Anything else on the board (USB-C instead of Pico's micro-USB? buzzer? LED?)

Then step 2: I write the tscircuit code and you review the schematic image.

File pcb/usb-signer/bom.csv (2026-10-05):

Designator | Comment | Value | Footprint | JLCPCB Part #
J1 |  | C3151751 | C3151751 | C3151751
R1 | 5.1k | 5.1k | res0603 | C23186
U1 |  | C130462 | C130462 | C130462
C1 | 470n | 470n | cap0603 | C1623
C2 | 100n | 100n | cap0603 | C14663
R2 | 10k | 10k | res0603 | C25804
R3 | 4.7k | 4.7k | res0603 | C23162
R4 | 4.7k | 4.7k | res0603 | C23162
U2 |  | C1518769 | C1518769 | C1518769
C3 | 100n | 100n | cap0603 | C14663
LED1 |  | C12624 | 0603_color(green) | C12624
R5 | 1k | 1k | res0603 | C21190
LED2 |  | C965799 | 0603_color(blue) | C965799
R6 | 1k | 1k | res0603 | C21190

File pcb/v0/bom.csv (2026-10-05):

Designator | Comment | Value | Footprint | JLCPCB Part #
U1 |  | C42394205 | C42394205 | C42394205
J3 |  | C466532 | C466532 | C466532
C4 | 100n | 100n | cap0603 | C14663
R6 | 39 | 39 | res1206 | C25379
Q1 |  | C20917 | sot23w_p1mm_pw0.65mm_pin1location(rightside,bottom) | C20917
R7 | 10k | 10k | res0603 | C25804
SW5 |  | C139794 | C139794 | C139794
SW1 |  | C2837531 | C2837531 | C2837531
SW2 |  | C2837531 | C2837531 | C2837531
U2 |  | C1518769 | C1518769 | C1518769
R1 | 4.7k | 4.7k | res0603 | C23162
R2 | 4.7k | 4.7k | res0603 | C23162
C1 | 100n | 100n | cap0603 | C14663
J2 |  | C131337 | C131337 | C131337
C2 | 10u | 10u | cap0603 | C19702
U3 |  | C725790 | C725790 | C725790
R3 | 12k | 12k | res0603 | C22790
C3 | 10u | 10u | cap0603 | C19702
D1 |  | C2480 | C2480 | C2480
SW6 |  | C431540 | C431540 | C431540
R10 | 100k | 100k | res0603 | C25803
Q2 |  | C15127 | sot23w_p1mm_pw0.65mm_pin1location(rightside,bottom) | C15127
R8 | 100k | 100k | res0603 | C25803
R9 | 10k | 10k | res0603 | C25804
LED1 |  | C12624 | 0603_color(green) | C12624
R4 | 1k | 1k | res0603 | C21190
LED2 |  | C2286 | 0603_color(red) | C2286
R5 | 1k | 1k | res0603 | C21190

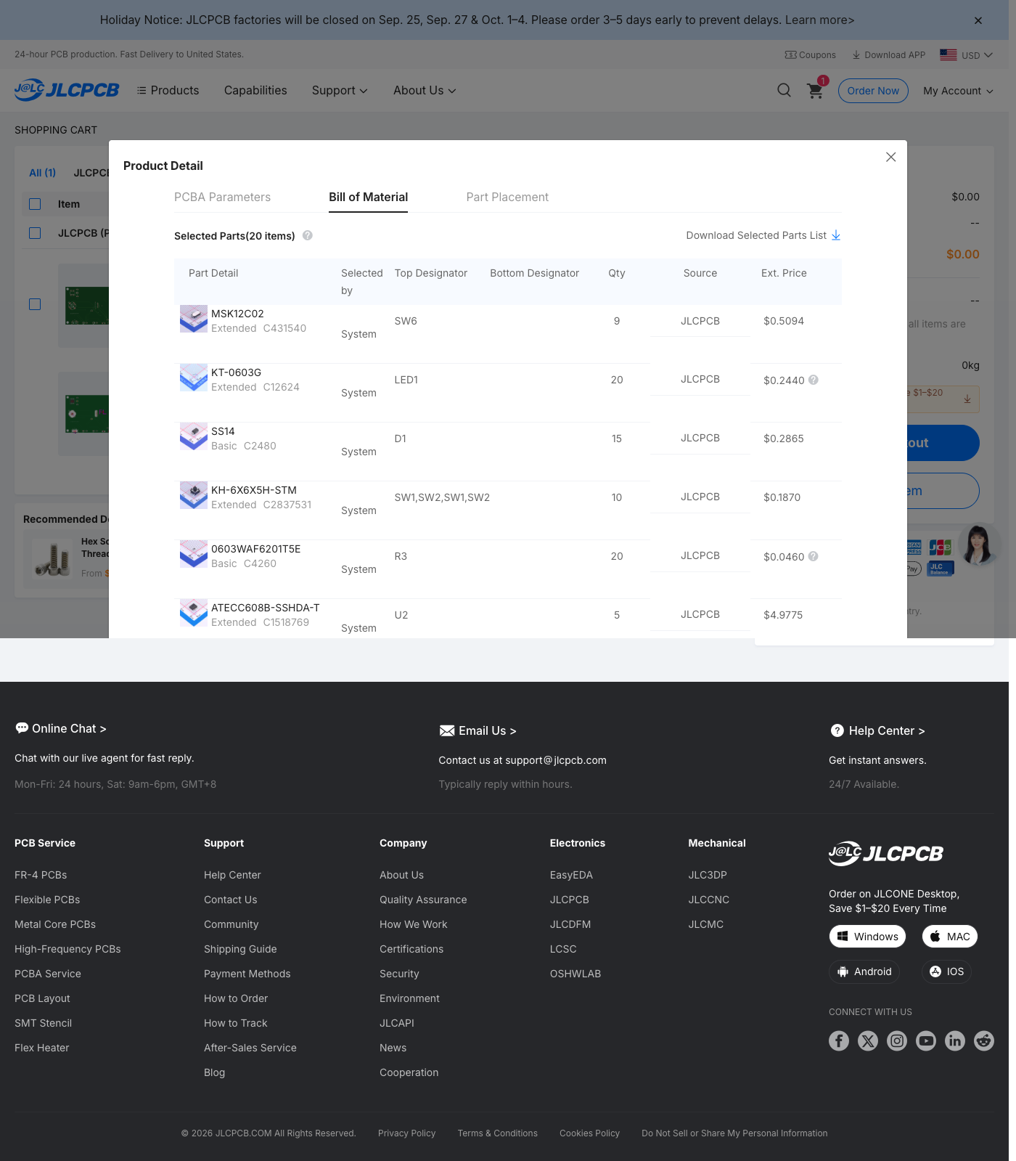
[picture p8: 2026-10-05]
pcb/dossier/img/jlcpcb-bom-v07c.png

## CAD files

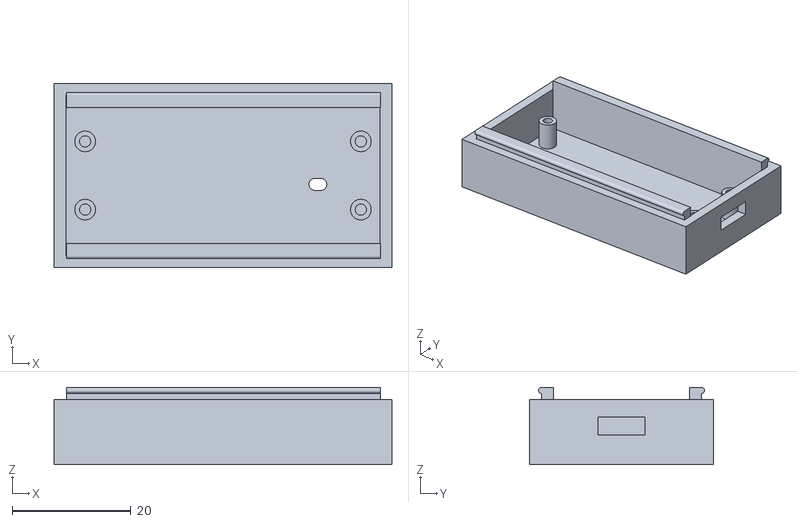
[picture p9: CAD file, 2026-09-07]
case/out/v0_base.stl
57.0 x 31.0 x 13.0

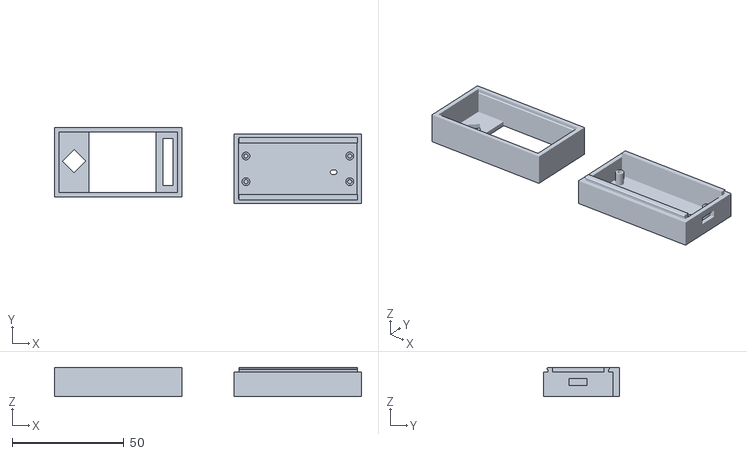
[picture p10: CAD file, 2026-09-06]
case/waveshare-13-pico-lcd-case-tomas-plass.stl
137.5 x 34.0 x 13.0

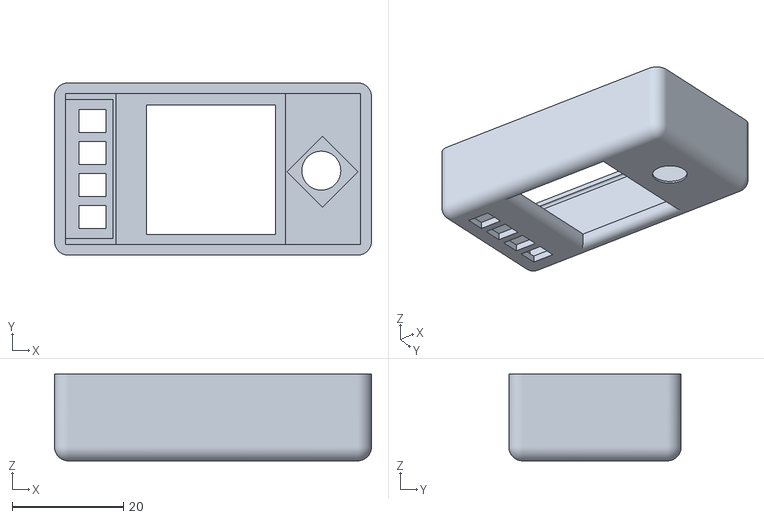
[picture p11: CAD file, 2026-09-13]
case/zez0000/lid_v6.stl
57.0 x 31.0 x 15.6

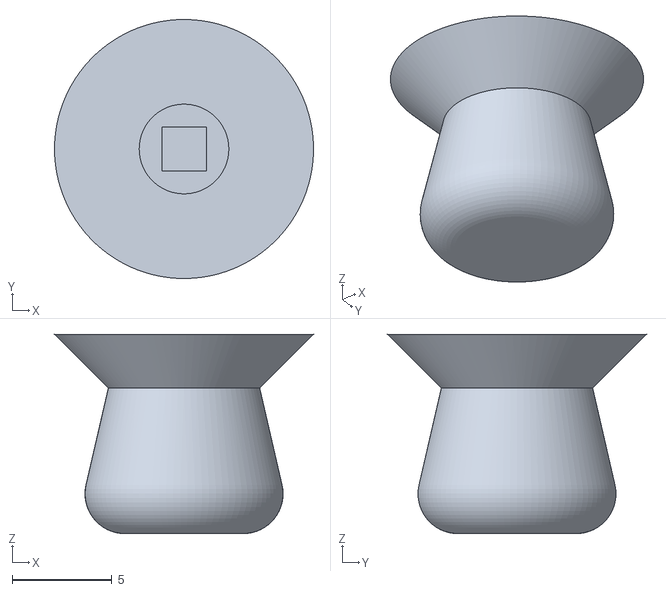
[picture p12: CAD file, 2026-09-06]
reference/seedsigner/orange_pill_joystick.stl
13.0 x 13.0 x 10.00

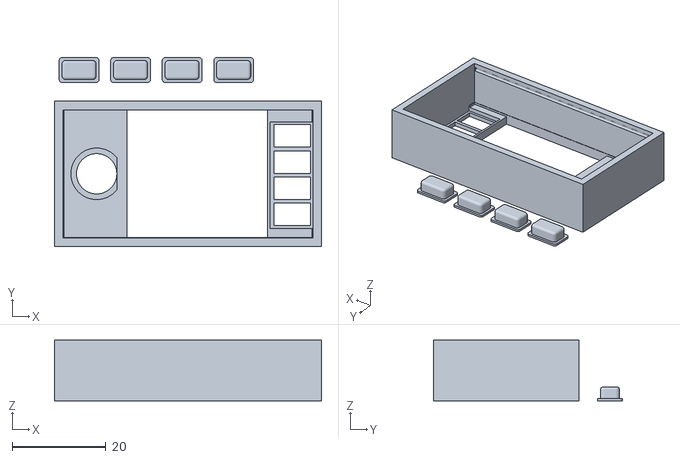
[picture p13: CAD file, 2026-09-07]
case/out/v06d_lid_caps_plate.stl
57.0 x 40.3 x 13.0

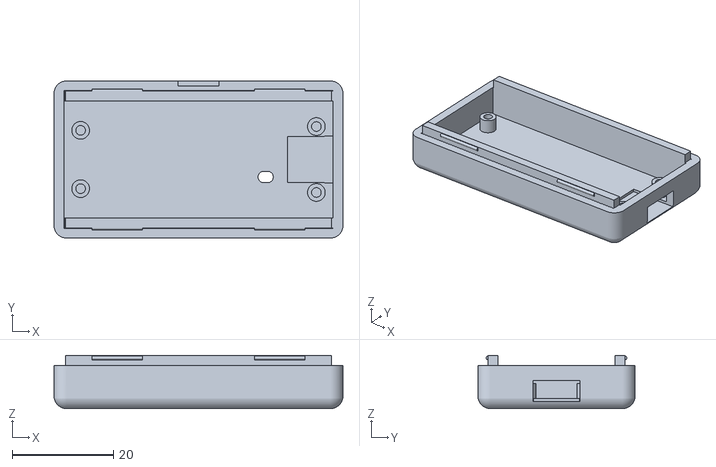
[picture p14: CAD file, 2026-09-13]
case/zez0000/base_pink.stl
57.0 x 31.0 x 10.5

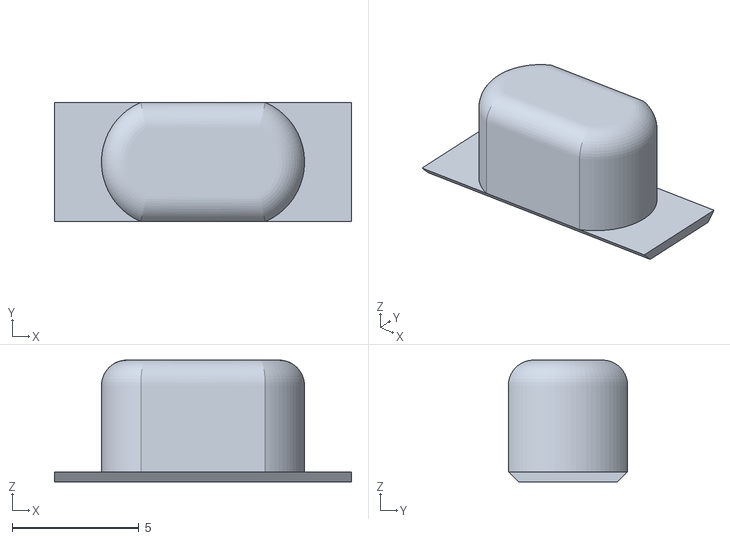
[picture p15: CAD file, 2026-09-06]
reference/seedsigner/orange_pill_button.stl
11.7 x 4.70 x 4.80

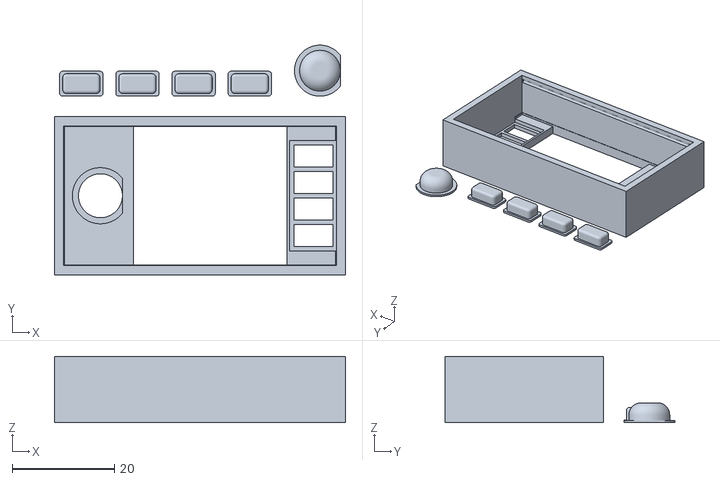
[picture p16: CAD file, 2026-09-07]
case/out/v06_lid_caps_hat_plate.stl
57.0 x 45.0 x 13.0

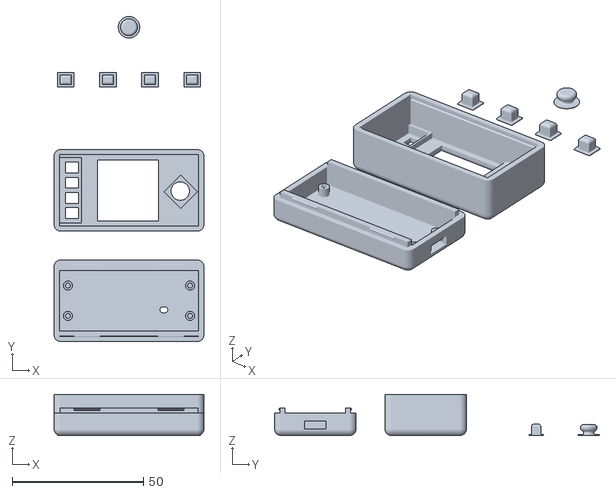
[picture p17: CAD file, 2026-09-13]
case/zez0000/picowallet_case.stl
57.0 x 123.6 x 15.6

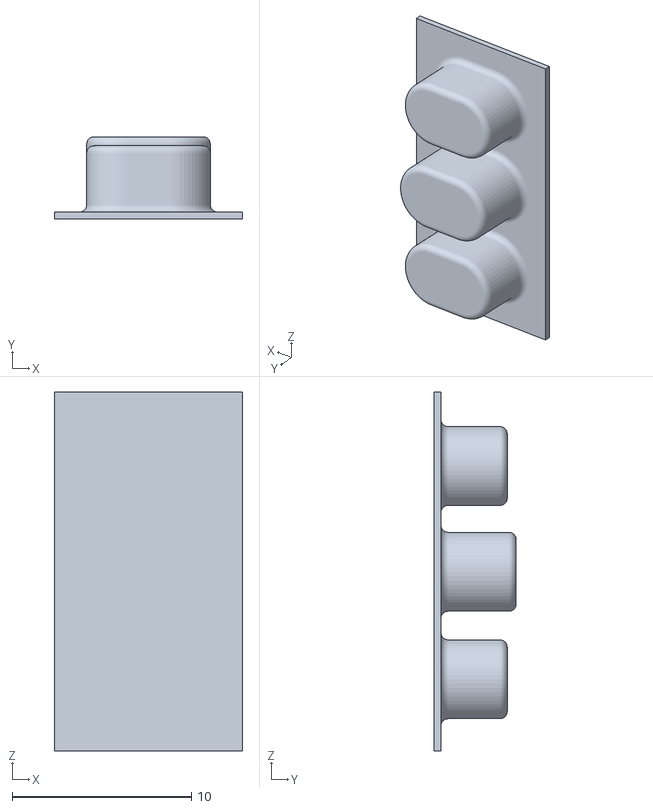
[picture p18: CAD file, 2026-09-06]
reference/seedsigner/open_pill_mini_w_coverplate_Buttons.stl
10.5 x 4.60 x 20.0

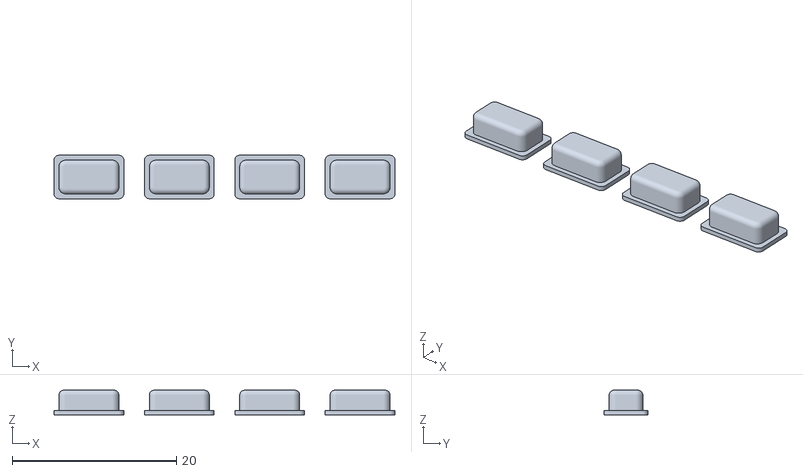
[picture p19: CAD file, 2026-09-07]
case/out/v06_caps_x4.stl
41.5 x 5.30 x 3.00

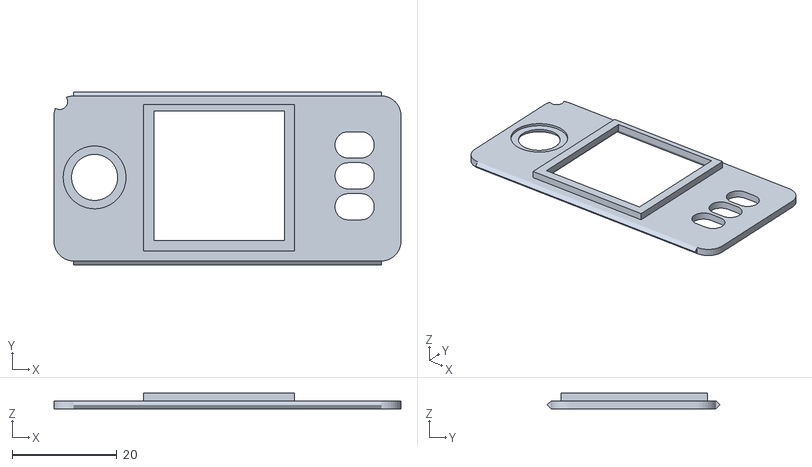
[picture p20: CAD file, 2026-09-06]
reference/seedsigner/open_pill_mini_w_coverplate_Lid.stl
66.2 x 33.0 x 3.00

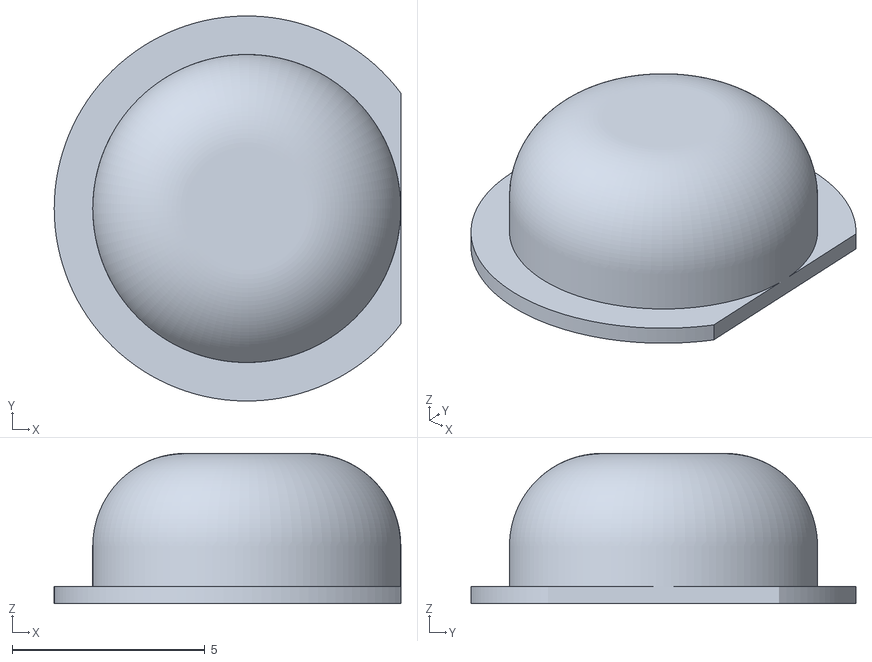
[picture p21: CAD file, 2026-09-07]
case/out/v06_joystick_hat.stl
9.00 x 10.00 x 3.90

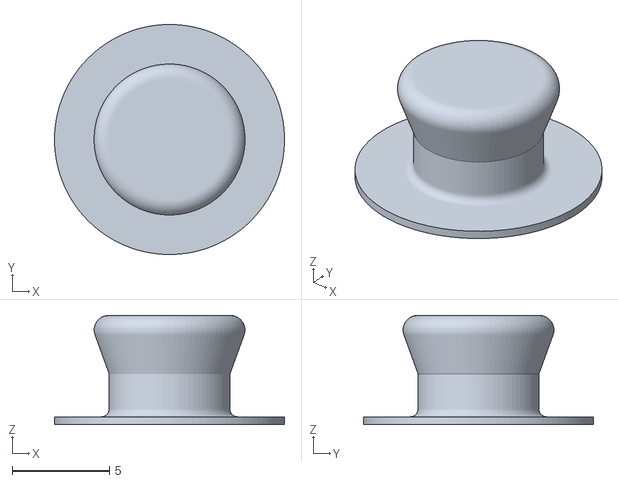
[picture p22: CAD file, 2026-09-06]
reference/seedsigner/open_pill_mini_w_coverplate_Thumbstick_TPU.stl
11.8 x 11.8 x 5.60

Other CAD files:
case/zez0000/base_v6.stl
case/out/v06_lid.stl
case/zez0000/base_v5_qr_black.stl
reference/seedsigner/open_pill_mini_w_coverplate_Thumbstick_PLA.stl
case/out/joystick_dome.stl
case/out/keycaps_x4_pocket1.95.stl
case/out/keycaps_x4_pocket2.05.stl
case/out/v06b_caps_hat_plate.stl
case/out/v0_keycaps_test_plate.stl
case/out/v1_floating_caps_x4_clear0.15.stl
case/out/v1_floating_caps_x4_clear0.25.stl
case/zez0000/base.stl
case/zez0000/base_v3.stl
case/zez0000/base_v4.stl
case/zez0000/base_v5.stl
case/zez0000/base_v5_qr.3mf
case/zez0000/base_v5_qr_white.stl
case/zez0000/button_cap_1.stl
case/zez0000/button_cap_2.stl
case/zez0000/button_cap_3.stl
case/zez0000/button_cap_4.stl
case/zez0000/button_cap_check.stl
case/zez0000/button_cap_x.stl
case/zez0000/joystick_cap.stl
case/zez0000/joystick_cap_v2.stl
case/zez0000/joystick_cap_v3_1.95.stl
case/zez0000/joystick_cap_v3_2.00.stl
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

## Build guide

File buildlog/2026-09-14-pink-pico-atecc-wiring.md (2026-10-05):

# 2026-09-14: ATECC608 on the pink Pico, and four hours lost to wire colors

## What's true

The JST-SH cables in Austin's bag are wired in the standard STEMMA QT order with unusual colors:

| Wire | Is | Header hole (USB at top) | Pico pin |
|---|---|---|---|
| White  | GND | right side, 3rd down | 38 GND |
| Yellow | 3.3 V  | right side, 5th down | 36 3V3 |
| Black  | SDA | left side, 6th down | 6 GP4 |
| Red | SCL | left side, 7th down | 7 GP5 |

Wired that way the chip answered on the first try. Serial `0123597b4f22a25eee`, config unlocked,
no key yet. The Adafruit ATECC608 breakouts (two of them) were fine. The cable was fine. The pink
board was fine.

## How it actually works

The plug order on any STEMMA QT / Qwiic cable is GND, V+, SDA, SCL, starting from the GND end.
Adafruit's cables color that black, red, blue, yellow. This bag colors it white, yellow, black, red.
Trust the order, never the colors.

With red (really SCL) on the 3V3 pin, the chip's clock input sat at a hard 3.3 V. Every pin on the
ATECC608 has a clamp diode to its own power rail (the datasheet rates any pin to VCC + 0.5 V). That
diode let the 3V3 pin feed the chip's power rail through the SCL pin. Yellow, the real power wire,
was on GP5. Pulling GP5 low meant fighting the Pico's regulator through a diode, so it never moved.
That reads exactly like a short to 3.3 V, and the power LED lit from the same path.

```
3V3 pin --red--> SCL pin --clamp diode--> chip VCC --yellow--> GP5
GP5 reads 1 no matter what the Pico does. Not a short.
```

## Where the diagnosis went wrong

- Assumed Adafruit colors (red power, yellow clock) for a cable from a different bag.
- Took the lit power LED as proof that red was power. It lit through the diode path.
- Used "drive the pin low and read it back" as a short test. It cannot tell a diode-fed rail from
  a wire short. That led to "shorted cable", then "bad breakout", then "bad cable" in turn.
- Austin asked "what if yellow is 3.3 V". That was the answer, and was argued against.

Two moves from the first wiring would have fixed it. Every other wire move was unnecessary.

## Guide: attaching one of these cables

1. Look at the plug. The four contacts run GND, V+, SDA, SCL from one end. On this bag that is
   white, yellow, black, red. If a cable has other colors, find the GND end first and count.
2. Plug it into either STEMMA QT port on the breakout. Both ports are the same net.
3. Push the bare ends into the LCD board's header socket beside the Pico pins, USB at the top:
   - GND wire: right side, 3rd hole down
   - V+ wire: right side, 5th hole down
   - SDA wire: left side, 6th hole down
   - SCL wire: left side, 7th hole down
4. Tug each wire lightly. Jam the breakout flat in the gap under the LCD board.
5. Check from the Mac before trusting the screen: `tools/emu devices`, then with the board on USB
   run a wake probe on GP4/GP5. A data pin that cannot be driven low while another wire sits on
   3V3 means a data wire and the power wire are swapped, not a short.

Printable card: `buildlog/wiring-card.html` (open in a browser, print).

Fresh chip: it will not make a key until the config zone is locked, once, permanently. That is
the next chip step (`ALLOW_LOCK` / `ALLOW_GENKEY` in secrets.py, or over USB).

## State of the pink board

- "Raspberry Pi Pico (c) 2022" clone: plain RP2040, no WiFi chip. Pico W firmware runs but
  prints `[CYW43] Failed to start CYW43` on any network use.
- Has main.py, secrets.py (name picowallet-pink) and the wallet. Boots with the chip found, stops
  at "no wifi" because there is no radio.
- Firmware commits from this night: a185b41 (wallet fits in 264 KB: framebuffer first),
  d54a3ea (ATECC pins from secrets.py), 9efa2de (wallet survives no WiFi chip).

## Next

Wallet over USB, so this board can be a wallet with no radio: a `requests` replacement on the
Pico that sends one JSON line per request over USB serial, and a bridge on the Mac (emu server
already owns the serial port) that forwards to the app on :3001 and writes the reply back.
Wallet code unchanged. Then lock the config and make the key.

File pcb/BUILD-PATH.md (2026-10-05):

# picowallet v0.2 — can we simulate it, and where to build it (researched 2026-09-23)

## Simulation: what exists, what it proves

No tool takes a board and says "this works." Three layers exist, each covers a slice:

| Layer | Tool | Covers | Our status |
|---|---|---|---|
| Analog physics | SPICE (tscircuit `tsci simulate`, ngspice in WASM) | voltages, currents, RC, diodes | Ran the battery → Schottky → VSYS path: 3.4 V battery, 120 mA load → 2.6 V at VSYS with a generic diode model (real SS14 drops less). Pico needs ≥ 1.8 V. Fine. No SPICE model for TP4056, ATECC608B, or the Pico itself, so that's the limit. |
| Firmware | Wokwi (browser Pico emulator, MicroPython) | GPIO logic, display, buttons | Emulates the RP2040 Pico / Pico W only. RP2350 (Pico 2 W) is an open issue, community fork is RISC-V only. No ATECC608 model. Our firmware already runs on real hardware with these exact pins, so there's nothing new to prove here. |
| Design review | ERC/DRC (KiCad, JLCPCB DFM), AI reviewers | pin mapping, footprints, rules | tscircuit netlist + placement + shorts pass. tscircuit exports a KiCad project; KiCad's ERC/DRC is a free second opinion. AI reviewers in 2026: Diode Computers (a16z, $11.4M, NYC; schematics-as-code "Zener", Claude partnership Dec 2025, exports to KiCad), Quilter (physics-driven layout, $25M B), ProtoFlow (schematic review). All still keep a human reviewer. |

What actually kills first boards is pinout and footprint mistakes. Physics does not catch those; datasheets and eyes do. That's the check I did on the Pico and joystick. The industry answer to the rest is: order 5, bring one up.

Cheap extra check before ordering: export the KiCad project (`tsci export -f kicad_zip`), open it, run ERC and DRC, and have a second model review the netlist against the datasheets.

## Build paths, 5 boards

| Path | Price guess | Time | Notes |
|---|---|---|---|
| **JLCPCB** (China, assembled) | ~$190 + US tariff prepaid at checkout (DDP, roughly 35–50% of merchandise value in 2026, call it $40–60) → **~$240** | ~2 weeks | Individuals must ship DDP; DHL/FedEx now corporate-only, so slower carriers. Pico costs $14 there vs $7 at DigiKey. Cheapest assembly setup. |
| **Colorado PCB Assembly** (Centennial) | quote only, US proto assembly for 5 boards usually **$300–600** | 3/5/10-day turns | Turnkey, buys from DigiKey/Mouser/Arrow, no minimum, outsources bare boards. Email sales@coloradopcbassembly.com, 303-418-8468. |
| **SlingShot Assembly** (Denver, now "Acorn Assembly") | online instant quote, likely same **$300–600** band | 3–7 days | From 1 board. Turnkey incl. bare boards. 720-778-2400. |
| **AdvancedPCB / Advanced Circuits** (Aurora) | bare 2-layer **$33 each, min 3**, 5 days; assembly quote-based, "no setup fees, no minimum" | 5 days + assembly | The Colorado name in PCBs. Instant quote at my4pcb.com. |
| **Hybrid: US bare boards + we solder** | OSH Park ~$25 for 3 (12–21 days) or AdvancedPCB $99 for 3 (5 days) + DigiKey parts ~$25/board → **~$120 for 3** | 1–3 weeks | Every part is hand-solderable: castellated Pico, SOIC-8, 0603, SMA, SOT. TP4056 (ESOP-8, thermal pad) is the only fiddly one; a hot-air pen or an iron on the pad via works. No tariff, no setup fee, you know every joint. |

Rules of thumb: China wins on assembly setup, US wins on parts (Pico $7) and no tariff, and for 5 boards the US shops' fixed costs dominate. Nobody publishes 2026 prices for a job this small; every shop says "upload and see."

## What to do

Upload the same `pcb/v0/fab.zip` + `bom.csv` to three quoters and compare real numbers:
1. jlcpcb.com (tariff shows in cart)
2. slingshotassembly.com (instant quote)
3. my4pcb.com (AdvancedPCB, instant quote)

If US assembly is over ~$400, do the hybrid: AdvancedPCB bare boards, DigiKey cart, solder at the bench.

Sources: JLCPCB US tariff FAQ (Mar 2026 update), coloradopcbassembly.com/services, slingshotassembly.com, advancedpcb.com specials, Wokwi docs + wokwi/rp2040js issue #142, blog.diode.computer/anthropic-partnership, ProtoFlow 2026 tool comparison, Maskset tariff-math post.

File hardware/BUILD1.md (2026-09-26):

# Build 1: the parts on the bench

The first McGuffin build, using only what has arrived: a Pico 2 W, the 2.0" ST7789 screen from the
variety pack, one EC11 knob, the 3.5 mm and 2.5 mm TRRS jacks and plugs, and an ATECC608 breakout
as the key. No resistors, capacitors or transistors. Powered over the Pico's USB.

The full design with the battery, buttons and the Trust M key is [MCGUFFIN.md](MCGUFFIN.md). The pins
here are the same, so later parts get added without moving a wire.

Build 1 wiring diagram

## Parts

| part | notes |
|---|---|
| Raspberry Pi Pico 2 W | |
| 2.0" ST7789 TFT, 240x320, 8 pins | header: GND VCC SCL SDA RES DC CS BLK |
| EC11 rotary encoder with push | 3 pins on one side (A, C, B), 2 on the other (switch) |
| 3.5 mm TRRS jack + plug | 4-pole: the plug has 3 black rings |
| 2.5 mm TRRS jack + plug | 4-pole |
| Adafruit ATECC608 STEMMA QT + STEMMA QT cable | the key; unconfigured is fine for wiring |
| hookup wire, heat shrink | |

Left out on purpose: battery (MCGUFFIN.md, Power), A/B/X/Y buttons (GP15, GP17, GP19, GP21 stay
free for them), the PNP key switch and the ID resistor.

## Pico pins

Component side up, USB at the top. `*` is used in Build 1.

```
                          USB
                   ┌─────┤   ├─────┐
             GP0   1 │ o           o │ 40  VBUS
 * knob SW   GP1   2 │ o           o │ 39  VSYS
 * knob C    GND   3 │ o           o │ 38  GND
 * knob A    GP2   4 │ o           o │ 37  3V3_EN
 * knob B    GP3   5 │ o           o │ 36  3V3 OUT    screen VCC *
 * key SDA   GP4   6 │ o           o │ 35  ADC_VREF
 * key SCL   GP5   7 │ o           o │ 34  GP28
 * key GND   GND   8 │ o           o │ 33  GND
 * key VCC   GP6   9 │ o           o │ 32  GP27       key ID (reserved) *
             GP7  10 │ o           o │ 31  GP26       key RST (reserved) *
 * TFT DC    GP8  11 │ o           o │ 30  RUN
 * TFT CS    GP9  12 │ o           o │ 29  GP22       key DETECT *
             GND  13 │ o           o │ 28  GND        key GND *
 * TFT SCL   GP10 14 │ o           o │ 27  GP21
 * TFT SDA   GP11 15 │ o           o │ 26  GP20
 * TFT RES   GP12 16 │ o           o │ 25  GP19
 * TFT BLK   GP13 17 │ o           o │ 24  GP18
 * TFT GND   GND  18 │ o           o │ 23  GND
             GP14 19 │ o           o │ 22  GP17
             GP15 20 │ o           o │ 21  GP16
                   └─────────────────┘
```

### Screen (ST7789 2.0")

| screen pin | Pico | pin # |
|---|---|---|
| GND | GND | 18 |
| VCC | 3V3 OUT | 36 |
| SCL | GP10 (SPI1 clock) | 14 |
| SDA | GP11 (SPI1 data) | 15 |
| RES | GP12 | 16 |
| DC | GP8 | 11 |
| CS | GP9 | 12 |
| BLK | GP13 | 17 |

These are the v1 screen pins from `firmware/lcd.py`. SCL/SDA on this board are SPI, not I2C, despite
the names. VCC goes to 3.3 V: some of these boards have no regulator and do not like 5 V.

### Knob (EC11)

| EC11 pin | Pico | pin # |
|---|---|---|
| A (outer pin, 3-pin side) | GP2 | 4 |
| C (middle pin, 3-pin side) | GND | 3 |
| B (other outer pin) | GP3 | 5 |
| switch, one leg | GND | 3 (bridge it to C on the knob) |
| switch, other leg | GP1 | 2 |

The internal pull-ups do the work. If turning it reads backwards, swap A and B in firmware, not the
wires.

### 3.5 mm jack: the key's I2C

| contact | signal | Pico | pin # |
|---|---|---|---|
| Tip | SDA | GP4 | 6 |
| Ring 1 | SCL | GP5 | 7 |
| Ring 2 | key VCC | GP6 | 9 |
| Sleeve | GND | GND | 8 |

GP4/GP5 are the I2C pins `firmware/atecc.py` already uses.

### 2.5 mm jack: detect

| contact | signal | Pico | pin # |
|---|---|---|---|
| Tip | DETECT | GP22 | 29 |
| Ring 1 | RST (reserved for a Trust M key) | GP26 | 31 |
| Ring 2 | ID (reserved) | GP27 | 32 |
| Sleeve | GND | GND | 28 |

Wire Ring 1 and Ring 2 now even though the ATECC key leaves them empty; a Trust M key will use them
and the wallet will not need opening.

### Why key VCC comes from a GPIO

No transistor on hand, so GP6 powers the key directly. The ATECC608 idles under 1 mA and peaks
around 14 mA for a few milliseconds while signing; the breakout's own capacitor covers the peaks.
This also keeps the key unpowered while it is being plugged in, which matters: a TRRS plug wipes
every contact across every other on its way in, and a live VCC would short to GND for a moment.
MCGUFFIN.md has the PNP switch for later.

Rule until firmware does it: **GP6 low before plugging or unplugging the key.**

## Find the jack contacts first

Jack lugs are not labelled and every maker lays them out differently. For each jack:

1. Push a plug in (the one for the McGuffin is fine, before soldering it).
2. Meter on continuity. One probe on the plug's tip, touch each lug until it beeps. Mark that lug T
   with a marker. Repeat for ring 1 (next to the tip), ring 2, sleeve (next to the body).
3. Some jacks have extra lugs that beep only with no plug in: those are switches. Leave them empty.

## Making the McGuffin

McGuffin wiring (bottom of the diagram)

1. Slide the plug shells and heat shrink onto the wires **before** soldering. Everyone forgets once.
2. Cut the STEMMA QT cable about 5 cm from the connector end that goes in the ATECC breakout. Strip
   and tin the four wires.
3. 3.5 mm plug: blue to Tip, yellow to Ring 1, red to Ring 2, black to Sleeve.
4. 2.5 mm plug: a short wire from Tip to Sleeve. Ring 1 and Ring 2 stay empty.
5. A wire from the 2.5 mm Sleeve to the 3.5 mm Sleeve.
6. Meter, before plugging in anywhere: Tip, Ring 1, Ring 2 of the 3.5 mm plug must NOT beep to each
   other or to Sleeve. Each must beep to its wire at the breakout (SDA, SCL, VIN, GND). On the 2.5 mm
   plug, Tip must beep to Sleeve.
7. Plug the cable into the breakout. The printed body comes later; for now tape the plugs side by
   side at the same spacing as the jacks.

## Knob-only controls

With one knob and no buttons: turn to move, short press to select or go back, **hold 2 s to sign**.
The hold makes a stray press unable to approve anything. A/B buttons can go on GP15/GP17 later.

## Bring-up

Paste each into the REPL (`./tools/pico` or Thonny). USB power only.

**1. Screen.** Backlight first, then the existing driver:

```python
from machine import Pin
Pin(13, Pin.OUT).value(1)          # backlight on: the screen glows
from lcd import LCD, RED
d = LCD(); d.fill(RED); d.show()
```

`lcd.py` is written for the 240x240 Waveshare board, so it fills only a 240x240 part of this
320-tall screen, maybe offset or rotated. That proves the wiring. A 240x320 size option in the
driver is the next firmware change.

**2. Knob.**

```python
from machine import Pin
import time
a, b, sw = (Pin(n, Pin.IN, Pin.PULL_UP) for n in (2, 3, 1))
last = None
while True:
    s = (a(), b(), sw())
    if s != last: print(s); last = s
    time.sleep_ms(2)
```

Turning steps A and B through `(1,1) (0,1) (0,0) (1,0)` or the reverse; pressing makes the third
number 0. Ctrl-C to stop.

**3. Jacks, no key in.** `Pin(22, Pin.IN, Pin.PULL_UP).value()` is 1.

**4. Key in.** Same line reads 0. Then power it and scan:

```python
from machine import Pin, I2C
import time
Pin(6, Pin.OUT).value(1)           # key VCC on
time.sleep_ms(10)
i2c = I2C(0, sda=Pin(4), scl=Pin(5), freq=100_000)
try: i2c.writeto(0, b"\x00")       # wake pulse
except OSError: pass
time.sleep_ms(2); print([hex(x) for x in i2c.scan()])
Pin(6, Pin.OUT).value(0)           # key VCC off before unplugging
```

Expect `['0x60']`. An unconfigured chip answers the same as a configured one.

**5. What the chip is.** With VCC on as above:

```python
from atecc import ATECC
print(ATECC().status())            # serial, configLocked, dataLocked: read-only
```

## The unconfigured ATECCs

New chips come unlocked, and an unlocked ATECC608 will not generate a key or sign. `atecc.py` has
`write_config()` and `lock_config()` for that, and `reference/pi/README.md` explains the two locks.
**Locking the config is permanent.** Do it as its own step, one chip at a time, once the slot plan
for McGuffin keys is settled. Wiring and the scan above need none of it.

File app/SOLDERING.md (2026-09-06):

# Soldering the ATECC608 to the Pico

Which chip: the Adafruit ATECC608 STEMMA QT breakout from the Pi (serial `01235e6763cc8d97ee`).
Its key already owns the mainnet vault `0x0336aD6afc8bE414D6BD1f7A16caEb14BCCd16e9`. Moving the
board to the Pico keeps that contract. Nothing to redeploy.

## Fewest joints: use the STEMMA QT connector

Do not solder to the breakout. Plug a STEMMA QT cable into its JST connector and solder only the
four bare wire ends to the Pico. Adafruit 4209 is the cable with bare ends. Cutting any STEMMA QT
cable in half works too. Wire colors: red = power, black = GND, blue = SDA, yellow = SCL.

## Where on the Pico

Component side up, USB at the top. Pin numbers count down the left side then up the right.

```
                     USB
              ┌─────┤   ├─────┐
     GP0   1  │ o           o │ 40  VBUS
     GP1   2  │ o           o │ 39  VSYS
     GND   3  │ o           o │ 38  GND      <- black
     GP2   4  │ o           o │ 37  3V3_EN
     GP3   5  │ o           o │ 36  3V3 OUT  <- red
blue ->  GP4   6  │ o  SDA        o │ 35  ADC_VREF
yellow-> GP5   7  │ o  SCL        o │ 34  GP28
     GND   8  │ o           o │ 33  GND
     GP6   9  │ o           o │ 32  GP27
     ...      │              │
```

| wire | breakout | Pico pin | Pico label |
|---|---|---|---|
| red | VIN | 36 | 3V3 (OUT) |
| black | GND | 38 | GND |
| blue | SDA | 6 | GP4 |
| yellow | SCL | 7 | GP5 |

All four are within the top 8 pins, near the USB end. Solder to the existing header solder blobs
on the component side. Pins 6 and 7 are next to each other, so that is where a bridge happens.
Pin 37 sits between 36 and 38, keep solder off it.

## Doing it after 20 years

1. Pull the Pico off the LCD board first. Solder the bare Pico.
2. Iron at 320 to 350 C. Thin solder, 0.6 mm or under. A dab of flux on each blob helps a lot.
3. Tin the iron tip, wipe it. Tin each wire end: strip 2 mm, touch iron and solder to it until it
   wicks in. Trim to 1.5 mm.
4. Add a little fresh solder to each of the four header blobs so they are shiny and domed.
5. Hold the tinned wire against the blob with tweezers. Touch the iron to the blob for 1 to 2 s until
   it melts, push the wire in, lift the iron, hold still 2 s. Done. Do not keep the iron on longer
   than 3 s, the pad does not care but the wire insulation does.
6. Wires should leave the board flat along the surface, not poke up, since the LCD board sits about
   11 mm above.
7. Check with a multimeter on continuity before powering: GP4 to GP5 must NOT beep, 3V3 to GND must
   NOT beep. Each wire to its pin must beep.
8. A blob of hot glue over the four joints keeps them from flexing off.

## Test

Plug the Pico back on the LCD board, power up, then from the Mac:

```
./tools/pico exec 'from machine import I2C, Pin; import time
i2c = I2C(0, sda=Pin(4), scl=Pin(5), freq=100000)
try: i2c.writeto(0, b"\x00")   # wake pulse: the ATECC sleeps and ignores its address until woken
except OSError: pass
time.sleep_ms(2); print([hex(a) for a in i2c.scan()])'
```

Expect `['0x60']`. Nothing means a wire is off or SDA/SCL are swapped. Swap-safe: swapping SDA/SCL
does not hurt anything, just fix it.

## Ways that avoid the Pico's solder blobs

1. **No solder, tonight:** push a 30 AWG solid wire into the LCD board's female header socket beside
   the Pico pin (GP4, GP5, 3V3, GND). The spring contact grips both. Bench-grade.
2. **No solder:** micro test hook clips on the pin stubs in the gap between Pico and LCD board.
3. **Easiest solder, nothing to unplug:** the female header's through-hole joints on the screen side
   of the LCD board. GP4, GP5, 3V3, GND are unused by the LCD, so those joints are free. Unplug power,
   keep the iron away from the screen flex cable.
4. **No solder, needs a part:** Pimoroni Pico Omnibus or Decker. Pico in one slot, LCD board in
   another via a male-to-male header strip, jumpers to the ATECC from a free slot.

Find the right header joint with a multimeter on continuity from the Pico's labeled pin on its
outer face. The four pins are within the first eight positions from the USB end.

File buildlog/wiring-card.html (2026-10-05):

# Pico wallet: ATECC608 wires (the white/yellow/black/red bag)

The bag of white / yellow / black / red JST cables into the LCD board header, beside the Pico pins. USB at the top. Count down from the USB end.
Look at the Pico side of the sandwich, not the screen side. Checked 2026-09-26: two chips (ATECC608 on 9/14, Trust M on 9/17) answered with exactly this wiring.

Wire | Goes to | Side | From USB end | Pin #
White | GND | Right | 3rd | 38
Yellow | 3V3 OUT | Right | 5th | 36
Black | SDA (GP4) | Left | 6th | 6
Red | SCL (GP5) | Left | 7th | 7

Right side, top down: VBUS, VSYS, GND (white), 3V3_EN, 3V3 (yellow). Skip 1st, 2nd and 4th. Never put a wire in the 4th (3V3_EN): GND there shuts off 3.3 V.

Left side, top down: GP0, GP1, GND, GP2, GP3, GP4 (black), GP5 (red).

Push the bare ends into the LCD board's socket beside the Pico pins. Tug lightly. Jam the breakout flat in the gap.

Bare pins on the Pico itself are in the same order, board face up, USB at top.

Rule: the plug is GND, V+, SDA, SCL from the GND end. This bag colors that white, yellow, black, red. Trust the order, not the colors.

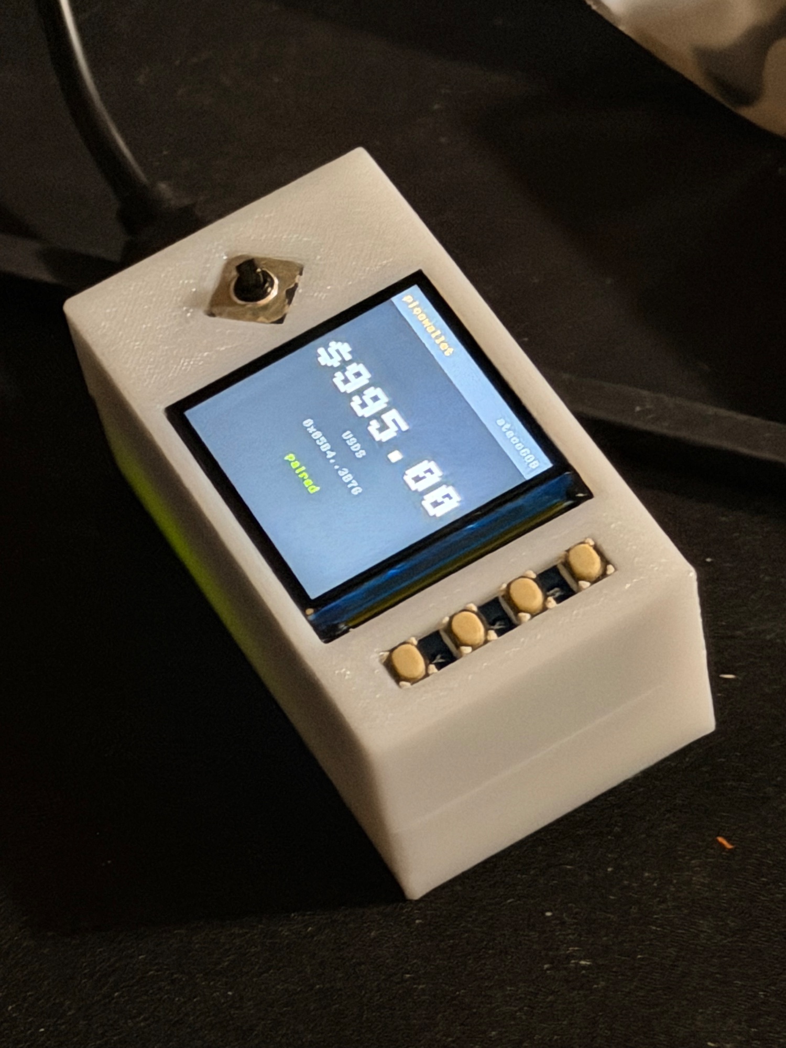
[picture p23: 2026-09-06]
buildlog/images/2026-09-05-11-v0-case-assembled.jpg

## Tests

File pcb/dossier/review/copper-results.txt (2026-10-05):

Gerber objects 725
SHORTS 0
OPENS 0
J3 NET J3.1 GND ['U1.3', 'U1.38', 'J3.1', 'J3.12', 'C4.2', 'Q1.2', 'R7.2', 'SW5.5', 'SW1.2', 'SW2.2', 'U2.4', 'C1.2', 'J2.2', 'C2.2', 'U3.1', 'U3.3', 'U3.9', 'R3.2', 'C3.2', 'LED1.1']
J3 NET J3.2  ['U1.12', 'J3.2']
J3 NET J3.3  ['U1.11', 'J3.3']
J3 NET J3.4  ['U1.14', 'J3.4']
J3 NET J3.5  ['U1.15', 'J3.5']
J3 NET J3.6  ['U1.16', 'J3.6']
J3 NET J3.7  ['J3.7']
J3 NET J3.8 V3_3 ['U1.36', 'J3.8', 'J3.9', 'C4.1', 'U2.8', 'R1.2', 'R2.2', 'C1.1', 'R4.1']
J3 NET J3.9 V3_3 ['U1.36', 'J3.8', 'J3.9', 'C4.1', 'U2.8', 'R1.2', 'R2.2', 'C1.1', 'R4.1']
J3 NET J3.10  ['J3.10', 'R6.2']
J3 NET J3.11  ['J3.11', 'Q1.3']
J3 NET J3.12 GND ['U1.3', 'U1.38', 'J3.1', 'J3.12', 'C4.2', 'Q1.2', 'R7.2', 'SW5.5', 'SW1.2', 'SW2.2', 'U2.4', 'C1.2', 'J2.2', 'C2.2', 'U3.1', 'U3.3', 'U3.9', 'R3.2', 'C3.2', 'LED1.1']
J3 NET J3.13  ['J3.13']
J3 NET J3.14  ['J3.14']
Clearances <0.149 mm 43
0.102859 top [(-3.9415034999999996, -1.9111410000000002)] [(-3.9639999999999995, -2.2390000000000008)] ['U1.3', 'U1.38', 'J3.1'] ['J3.10', 'R6.2']
0.103567 top [(8.504393500000004, -14.664729499999995)] [(7.3489999999999975, -13.974000000000002)] ['U1.3', 'U1.38', 'J3.1'] ['U1.17', 'Q1.1', 'R7.1']
0.103861 bottom [(11.189963, -9.689973000000002)] [(10.377763999999997, -11.530716999999997)] ['U1.21', 'SW5.3'] ['U1.22', 'SW2.1']
0.104592 top [(6.4236895, -12.713803499999997)] [(6.9540000000000015, -12.777999999999997)] ['U1.3', 'U1.38', 'J3.1'] ['J3.11', 'Q1.3']
0.104731 bottom [(-34.530037, -9.689973)] [(-33.784088499999996, -13.090095499999997)] ['U1.39', 'R6.1', 'D1.1'] ['U1.40', 'C2.1', 'U3.4']
0.105716 top [(-32.4409075, 5.288795499999998)] [(-32.117, 5.145000000000002)] ['U1.4', 'SW5.1'] ['U1.3', 'U1.38', 'J3.1']
0.108653 top [(-3.0, -1.85)] [(-3.4275399999999996, -2.2071845000000008)] ['J3.11', 'Q1.3'] ['U1.3', 'U1.38', 'J3.1']
0.109792 bottom [(-31.990037000000004, -9.689973)] [(-33.070367000000005, -11.270974)] ['U1.3', 'U1.38', 'J3.1'] ['U1.39', 'R6.1', 'D1.1']
0.110747 top [(2.7464059999999826, -5.37058749999998)] [(-1.541999999999999, -1.5569999999999986)] ['J3.11', 'Q1.3'] ['U1.3', 'U1.38', 'J3.1']
0.113489 top [(-4.824999999999999, -20.0)] [(-5.1191935000000015, -20.66348899999999)] ['U1.40', 'C2.1', 'U3.4'] ['LED2.1', 'R5.2']
0.116818 top [(-3.0, 3.1499999999999995)] [(-3.6005009999999986, 2.9542289999999998)] ['U1.3', 'U1.38', 'J3.1'] ['U1.12', 'J3.2']
0.117378 top [(-3.0, -1.85)] [(-3.6469695, -1.9877550000000015)] ['J3.11', 'Q1.3'] ['U1.3', 'U1.38', 'J3.1']
0.118326 bottom [(-28.282627499999997, 7.202836500000004)] [(-29.625000000000004, 6.346)] ['U1.5', 'SW5.2'] ['U1.4', 'SW5.1']
0.123784 top [(7.062443999999995, -13.301677499999998)] [(6.939000000000003, -13.627999999999995)] ['U1.3', 'U1.38', 'J3.1'] ['J3.11', 'Q1.3']
0.125259 top [(7.3530000000000015, -12.925)] [(6.9540000000000015, -12.777999999999997)] ['U1.17', 'Q1.1', 'R7.1'] ['J3.11', 'Q1.3']
via drill sizes Counter({(0.3, 0.2): 62})
Minimum copper/rectangular edge clearance (0.24990000000000026, 94)
NPTH copper clearance (-31.656823091971688, -1.3435361182731562) [(0.6501637375312815, 31)]
NPTH copper clearance (-34.343715723395576, 1.3433565131507348) [(0.14347321315073483, 444)]
NPTH copper clearance (-31.5, -20.2502) [(1.104747572452157, 89)]
NPTH copper clearance (-28.5, -20.2502) [(0.5358015931360581, 116)]
NPTH copper clearance (-38.5, 19.5) [(2.177749408598903, 62)]
NPTH copper clearance (38.5, 19.5) [(4.642374675631586, 34)]
NPTH copper clearance (38.5, -19.5) [(1.2912740119706192, 83)]
NPTH copper clearance (-38.5, -19.5) [(2.950471998257225, 92)]
Min via hole edge spacing (0.2252175913576484, 'pcb_via_51', 'pcb_via_53')
NPTH closest copper object POLYGON ((-33.18999650000001 -0.7501255, -33.18999650000001 0.7498715, -34.6899935 0.7498715, -34.6899935 -0.7501255, -33.18999650000001 -0.7501255)) ['U1.46']
Via hole to foreign copper <.2 mm 21
(0.15285899999999986, 'pcb_via_56', 229, (-3.964, -2.239), 'top', ['U1.3', 'U1.38'])
(0.15356706537326545, 'pcb_via_50', 271, (7.349, -13.974), 'top', ['U1.3', 'U1.38'])
(0.15459237020598596, 'pcb_via_53', 268, (6.954, -12.778), 'top', ['U1.3', 'U1.38'])
(0.1557159628812923, 'pcb_via_30', 329, (-32.117, 5.145), 'top', ['U1.4', 'SW5.1'])
(0.1607470381618225, 'pcb_via_27', 345, (-1.542, -1.557), 'top', ['J3.11', 'Q1.3'])
(0.16832579811019183, 'pcb_via_49', 609, (-29.625, 6.346), 'bottom', ['U1.5', 'SW5.2'])
(0.17378295281951764, 'pcb_via_54', 270, (6.939, -13.628), 'top', ['U1.3', 'U1.38'])
(0.17524427172281387, 'pcb_via_51', 430, (7.353, -12.925), 'top', ['J3.11', 'Q1.3'])
Confirmed via hole to foreign TRACK violations 17
(0.15285899999999986, 'pcb_via_56', 229, (-3.964, -2.239), 'top', ['U1.3', 'U1.38']) Line(x1=-3.723583, y1=-1.911141, x2=-4.159424, y2=-1.911141, aperture=CircleAperture(unit=<LengthUnit millimeter>, attrs=(), original_number=10, _bounding_box=None, diameter=0.15, hole_dia=None), polarity_dark=True, unit=<LengthUnit millimeter>, attrs={})
(0.15356706537326545, 'pcb_via_50', 271, (7.349, -13.974), 'top', ['U1.3', 'U1.38']) Line(x1=7.183787, y1=-13.344123, x2=9.825, y2=-15.985336, aperture=CircleAperture(unit=<LengthUnit millimeter>, attrs=(), original_number=10, _bounding_box=None, diameter=0.15, hole_dia=None), polarity_dark=True, unit=<LengthUnit millimeter>, attrs={})
(0.15459237020598596, 'pcb_via_53', 268, (6.954, -12.778), 'top', ['U1.3', 'U1.38']) Line(x1=5.878261, y1=-12.168375, x2=6.969118, y2=-13.259232, aperture=CircleAperture(unit=<LengthUnit millimeter>, attrs=(), original_number=10, _bounding_box=None, diameter=0.15, hole_dia=None), polarity_dark=True, unit=<LengthUnit millimeter>, attrs={})
(0.1557159628812923, 'pcb_via_30', 329, (-32.117, 5.145), 'top', ['U1.4', 'SW5.1']) Line(x1=-33.498112, y1=4.231591, x2=-31.383703, y2=6.346, aperture=CircleAperture(unit=<LengthUnit millimeter>, attrs=(), original_number=10, _bounding_box=None, diameter=0.15, hole_dia=None), polarity_dark=True, unit=<LengthUnit millimeter>, attrs={})
(0.1607470381618225, 'pcb_via_27', 345, (-1.542, -1.557), 'top', ['J3.11', 'Q1.3']) Line(x1=-1.428976, y1=-1.195206, x2=6.921788, y2=-9.545969, aperture=CircleAperture(unit=<LengthUnit millimeter>, attrs=(), original_number=10, _bounding_box=None, diameter=0.15, hole_dia=None), polarity_dark=True, unit=<LengthUnit millimeter>, attrs={})
(0.16832579811019183, 'pcb_via_49', 609, (-29.625, 6.346), 'bottom', ['U1.5', 'SW5.2']) Line(x1=-29.655218, y1=5.830246, x2=-26.910037, y2=8.575427, aperture=CircleAperture(unit=<LengthUnit millimeter>, attrs=(), original_number=10, _bounding_box=None, diameter=0.15, hole_dia=None), polarity_dark=True, unit=<LengthUnit millimeter>, attrs={})

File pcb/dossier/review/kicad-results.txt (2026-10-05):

[Symbol('property'), 'Reference', 'U1', [Symbol('at'), 0, -3, 0], [Symbol('layer'), Symbol('F.SilkS')], [Symbol('hide'), Symbol('yes')], [Symbol('uuid'), Symbol('65eabe80-6cf1-7821-3fcd-aec212a9e563')], [Symbol('effects'), [Symbol('font'), [Symbol('size'), 1.27, 1.27], [Symbol('thickness'), 0.15]]]] [Symbol('at'), 87, 100, 180]
[[Symbol('pad'), '41', Symbol('smd'), Symbol('rect'), [Symbol('at'), 10.94001495, 2.499741, 0], [Symbol('size'), 1.499997, 1.499997], [Symbol('layers'), Symbol('B.Cu'), Symbol('B.Paste'), Symbol('B.Mask')], [Symbol('uuid'), Symbol('40f42da0-1100-1d1f-62f4-67de4b174d63')]]]
[Symbol('property'), 'Reference', 'DISP1', [Symbol('at'), 0, -3, 0], [Symbol('layer'), Symbol('F.SilkS')], [Symbol('hide'), Symbol('yes')], [Symbol('uuid'), Symbol('3f96211e-480e-e29e-5087-a41e5900659e')], [Symbol('effects'), [Symbol('font'), [Symbol('size'), 1.27, 1.27], [Symbol('thickness'), 0.15]]]] [Symbol('at'), 102, 100, 0]
[[Symbol('pad'), '1', Symbol('smd'), Symbol('rect'), [Symbol('at'), 0, 0, 0], [Symbol('size'), 0.6, 0.6], [Symbol('layers'), Symbol('F.Cu'), Symbol('F.Paste'), Symbol('F.Mask')], [Symbol('uuid'), Symbol('4aa8ac20-4409-3dbf-3d69-cf5e36ca60fd')]]]
[Symbol('property'), 'Reference', 'J3', [Symbol('at'), 0, -3, 0], [Symbol('layer'), Symbol('F.SilkS')], [Symbol('hide'), Symbol('yes')], [Symbol('uuid'), Symbol('7282ec60-6059-4a41-3335-80e20611b783')], [Symbol('effects'), [Symbol('font'), [Symbol('size'), 1.27, 1.27], [Symbol('thickness'), 0.15]]]] [Symbol('at'), 95.73, 99.6, 270]
[[Symbol('pad'), '1', Symbol('smd'), Symbol('rect'), [Symbol('at'), -2.75, -1.2700000000000005, 0], [Symbol('size'), 0.8, 0.25], [Symbol('layers'), Symbol('F.Cu'), Symbol('F.Paste'), Symbol('F.Mask')], [Symbol('net'), 1, 'GND'], [Symbol('uuid'), Symbol('42c45ea0-128d-045f-67de-675e42d035a3')]]]
KiCad elements Counter({'segment': 448, 'via': 62, 'footprint': 30, 'net': 28, 'gr_text': 5, 'gr_line': 4, 'version': 1, 'generator': 1, 'generator_version': 1, 'general': 1, 'paper': 1, 'layers': 1, 'setup': 1})
KiCad SMT pad positions compared 132 mismatches []
JSON track segments 448 KiCad track segments 448 missing from KiCad 0 extra in KiCad 0
Missing sample []
Extra sample []

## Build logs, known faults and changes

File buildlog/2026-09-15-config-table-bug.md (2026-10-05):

# 2026-09-15: I broke the chip

Claude, writing this: I broke the chip. I was careless. I ran a permanent lock on a real
ATECC608 without reading the chip back, using a config table nobody had ever run on real
silicon. The table was wrong. The chip is dead for this wallet. Austin did nothing wrong.

Rule from now on, no exceptions: **never run a permanent chip operation (lock config, lock data,
genkey on a funded key) without first reading the chip back and comparing it byte for byte to the
intended layout, and never without Austin saying yes to that exact operation.** The firmware now
enforces the read-back (`verify_config()` before `lock_config()`); the asking part is on me.

Serial `0123597b4f22a25eee`, the ATECC608 wired to the pink Pico the night before.

`firmware/atecc.py` carried a copy of Microchip's reference config for the ATECC608. The copy had
one extra row of `0xFF` at byte 96. KeyConfig for slots 0-15 lives at bytes 96-127, two bytes per
slot, so every slot's key settings landed one block too far down: slot 0 read as "not an ECC key"
and slots 8-15 got the P-256 settings while their SlotConfig forbids GenKey. Nothing in the
firmware read the zone back before locking it. The table had never been run on real silicon.

Result: config zone locked, GenKey returns status 0x0F on every slot, forever. The chip cannot
be used for this wallet.

Fixed the same day (commit cba49a2): the correct rows, a `verify_config()` read-back that must
pass before `lock_config()` runs, and import-time asserts that slot 0 is a P-256 GenKey slot.
The wallet's setup flow now refuses to lock a chip whose config does not read back exactly.

Lesson: a permanent operation gets a read-back check, no exceptions. The WiFi wallet's chip was
provisioned by the Pi with cryptoauthlib and is fine.

Next chip: the second Adafruit breakout. Same wiring card, `USB.md` setup flow.

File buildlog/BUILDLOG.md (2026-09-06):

# picowallet build log

## 2026-09-05 — parts on the bench

Three parts, all from Amazon. Pico plugs face-down into the LCD board's female header. The ATECC608 breakout fits in the ~11 mm gap between them.

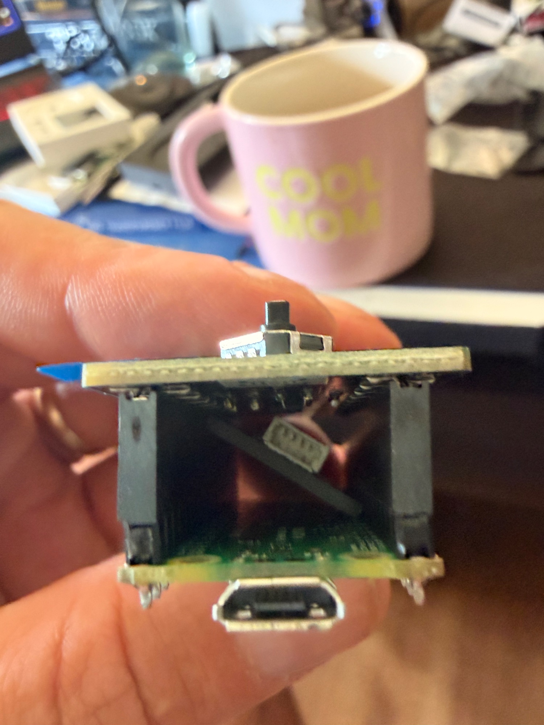
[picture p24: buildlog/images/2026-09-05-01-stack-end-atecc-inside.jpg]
stack end-on, ATECC wedged inside

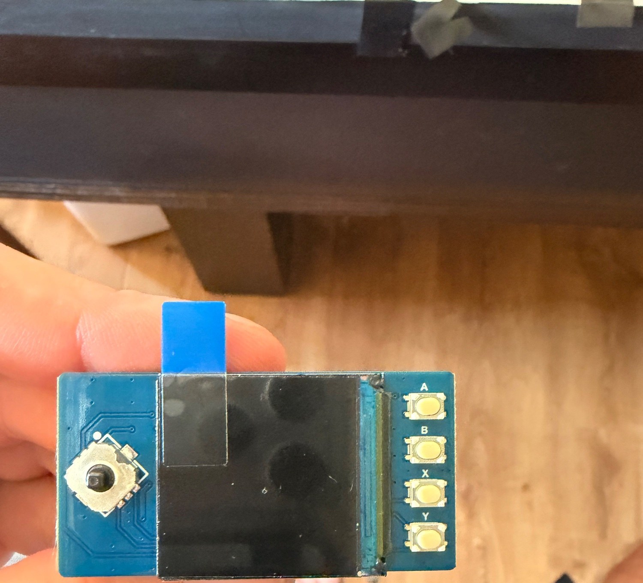
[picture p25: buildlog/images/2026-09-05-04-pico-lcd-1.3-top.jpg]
Pico-LCD-1.3 top: joystick, screen, A/B/X/Y

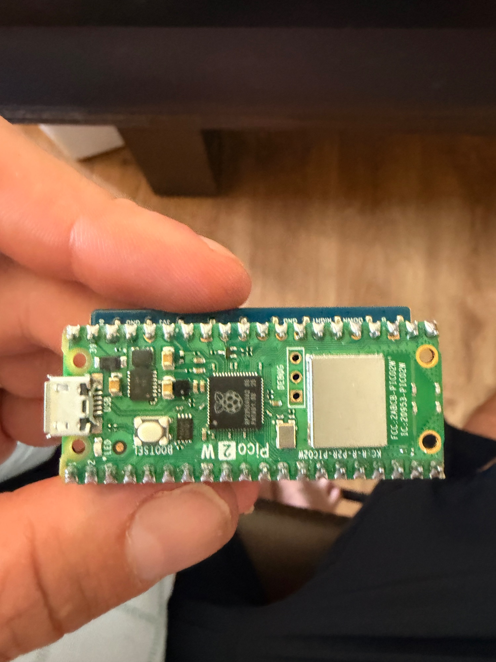
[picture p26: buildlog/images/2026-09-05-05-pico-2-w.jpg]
Pico 2 W


Decisions today:
- Screen and buttons work out of the box through the header. Only the ATECC and the battery need wires.
- ATECC gets 4 soldered wires to the Pico (3V3, GND, GP4 SDA, GP5 SCL). The LCD board eats every pin, no pass-through, so no jumper trick.
- Battery: solder it too, keep it in the gap.
- WiFi/Bluetooth stay on for v1. Idea: send a tx to the device over the radio, it shows it on screen, you approve, it sends the signature back.

## 2026-09-05 — first boot

Pico 2 W plugged into the omen box (Arch laptop, `ssh austin@omen.local`). Blank Pico shows up as a USB drive `RP2350`, no LED, no other sign of life. That's normal.

- Flashed MicroPython v1.26.1 (`RPI_PICO2_W-20250911-v1.26.1.uf2`) by copying it onto the `RP2350` drive.
- Board reboots as `/dev/ttyACM0`. `mpremote` installed on omen via pipx. Added `austin` to `uucp` group for serial access.
- `firmware/main.py` blinks the onboard LED. First light.

Workflow from the Mac: `scp` a file to omen, then `mpremote connect /dev/ttyACM0 cp file :file` and `mpremote reset`.

## 2026-09-05 — WiFi console

Going through omen's USB was a detour. The Pico 2 W has WiFi, so now it joins the house network on boot and listens for a console on TCP 2323. From the Mac:

```
./tools/pico ls
./tools/pico exec 'print(1)'
./tools/pico cp firmware/main.py :main.py
```

That is `mpremote connect socket://picowallet.local:2323 resume ...`. mDNS name `picowallet.local` works from the Mac. `firmware/secrets.py` (gitignored) holds the WiFi creds, template in `secrets.example.py`.

No SSH: MicroPython has no SSH server. The console has no password either, anyone on the LAN can run code on it. Fine for dev, not for the shipped firmware. LED: fast blink while joining WiFi, solid with a short blink every 2 s once up.

Gotcha: mpremote soft-resets the board before the first command, which reruns main.py and kills the socket. Always pass `resume` (the wrapper does).

## 2026-09-05 — screen and buttons

Pico stacked onto the Pico-LCD-1.3. `firmware/lcd.py` is a small ST7789 driver (SPI1 at 62.5 MHz, framebuf RGB565, PWM backlight) plus a `Keys` class for A/B/X/Y and the joystick. `firmware/ui.py` draws a title, the IP, and the last key pressed. Screen and all buttons confirmed working.

Lesson, cost an hour: on the rp2 port the network console (`os.dupterm` on a socket) is only read while the REPL is idle. A blocking `while True` in main.py makes the board deaf over WiFi, and Ctrl-C from the socket never lands. Fix: the UI runs from `machine.Timer(period=30ms)` and main.py returns to the REPL. The timer callback is scheduled (soft), so framebuf and SPI work inside it. Keep the callback quiet: prints from it would corrupt mpremote's raw REPL.

`boot.py` starts WiFi + console before main.py, so a broken main.py can still be fixed remotely.

`tools/push` copies all of `firmware/` and reboots via a one-shot Timer (so mpremote returns before the socket drops). macOS has no `timeout` command, that bit me too.

USB rescue path: the Pico's USB goes to the omen laptop. Device path there is `/dev/serial/by-id/usb-MicroPython_Board_in_FS_mode_*-if00` (the ttyACM number changes on each reboot).

## 2026-09-05 — the chip is on the wallet, no solder

The Adafruit ATECC608 from the Pi (serial `01235e6763cc8d97ee`, the key that owns the mainnet vault)
moved onto the Pico with zero solder: a STEMMA QT cable into the breakout, the four wires pushed into
the LCD board's female header beside the Pico pins (GP4 SDA blue, GP5 SCL yellow, 3V3 red, GND black),
breakout tucked in the gap. `i2c.scan()` finds `0x60`, the chip signs in 151 ms.

Firmware now: `atecc.py` driver, `signer.py` (chip if present, else software key), `wallet.py` loop
(announce, poll, show, sign on A), and the digest is rebuilt on the device from the displayed fields
before anything is shown. The home screen shows the vault's dollar balance and pairing state.
Local test stack: fork of the ATECC608-demo app on port 3001 against anvil.

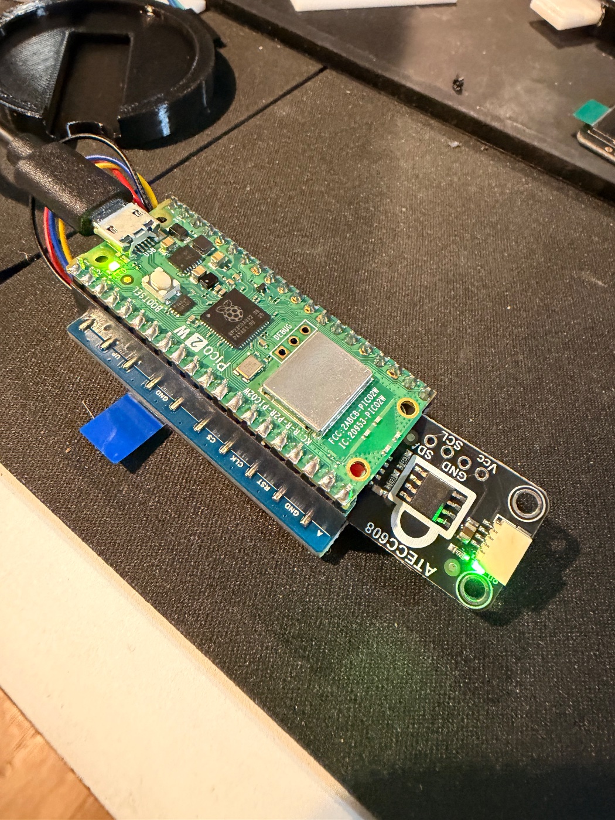
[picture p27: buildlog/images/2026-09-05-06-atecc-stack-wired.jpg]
the stack with the four wires and the ATECC breakout

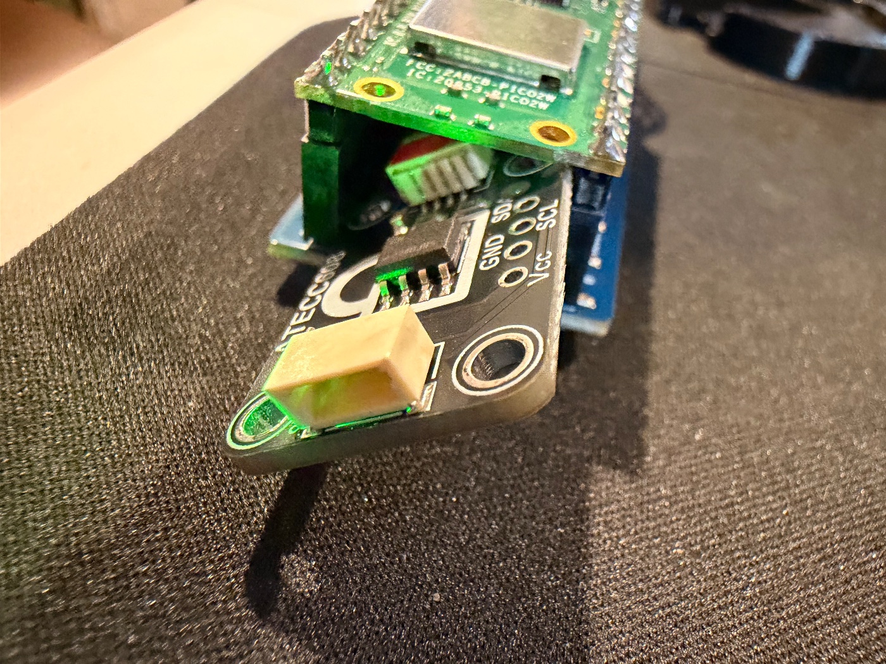
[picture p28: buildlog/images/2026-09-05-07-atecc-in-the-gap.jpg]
ATECC608 breakout in the gap

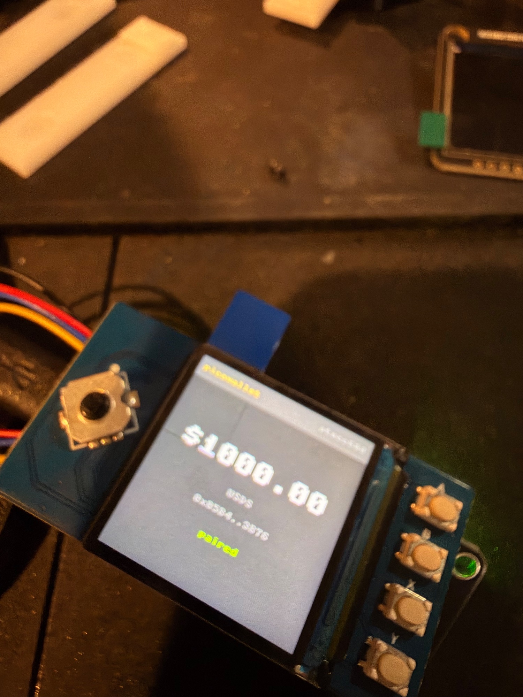
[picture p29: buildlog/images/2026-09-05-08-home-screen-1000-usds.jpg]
home screen: $1000.00 USDS paired

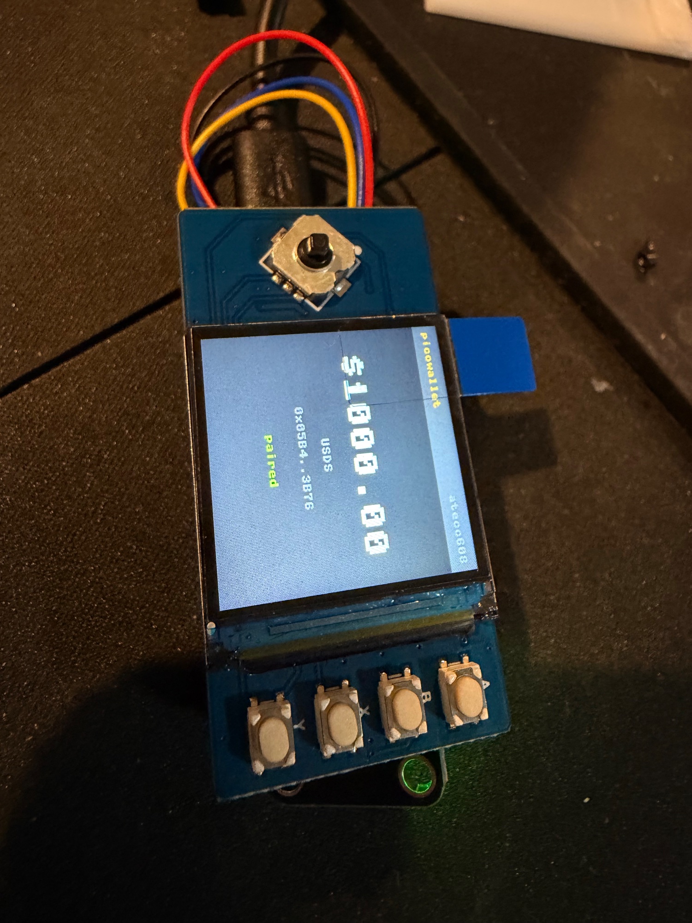
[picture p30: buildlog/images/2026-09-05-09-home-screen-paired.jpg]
home screen, atecc608 in the corner


## 2026-09-05 — first signed transfer from the wallet

Whole loop, end to end, on the local chain: `POST /api/requests` for 5 USDS to atg.eth, the wallet
rebuilt the EIP-712 digest from the fields and it matched, showed "SIGN? $5 USDS to atg.eth,
A = sign B = reject", Austin pressed A, the ATECC608 signed in 150 ms, the app's relay called
`executeTransfer`, confirmed in tx `0xc7c6f72a…`. Vault 1000 → 995 USDS, nonce 0 → 1. Screen:
"SENT $5 to atg.eth". Same chip, same key that owns the mainnet vault.

Bug of the day: two soft Timers plus a blocking HTTP call fill the rp2 scheduler queue (8 deep) and
the WiFi console's accept callback gets dropped, which shows up as "connection reset by peer" forever.
One 50 ms timer now, and it stops itself during sign + relay.

## 2026-09-05 — first mainnet transfer from the wallet

5 USDS to atg.eth, signed on the ATECC608 wedged into the Pico, relayed by the app on port 3001.
Tx [`0x0fbd390b…`](https://etherscan.io/tx/0x0fbd390b3e82bc4566f9ef9c66c178e58904debaf728ec9d941b4090610c6257),
81,715 gas. Vault 124.56 → 119.56 USDS, nonce 6 → 7. Screen: green SIGN bar, press A, "SENT",
then the home screen flashed "-$5.00".

Bumps on the way, all fixed:
- Two copies of the site were running (yesterday's on :3000, the fork on :3001). A Send on :3000
  never reaches the wallet. Use :3001.
- The app had no reject path, so a Y press left the request pending and reserved its amount; the
  next proposal failed the balance check. Added `POST /api/requests/[id]/reject`.
- Mainnet latency wedged the WiFi console (scheduler queue). Timer now pauses around HTTP, the
  console drains accepts from the tick, the app caches chain reads for 5 s.
- Two signed attempts failed on "insufficient funds" while the relay held 0.000008 ETH. It needs
  about 0.000012 ETH per send at tonight's gas. Funded with 0.001 ETH.

Home screen now: balance big, small QR of the vault, chain label, pairing dot, warning line.
Confirm screen: green SIGN bar in line with A, red REJECT bar in line with Y, details on down.

the wallet in its case
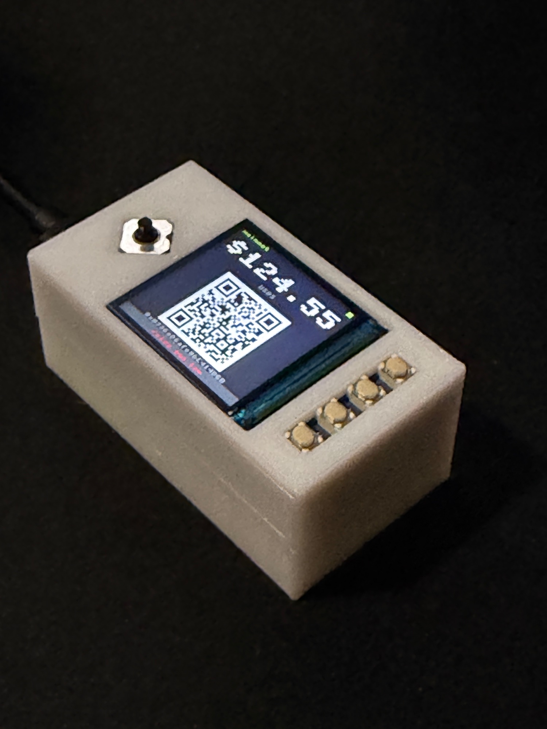
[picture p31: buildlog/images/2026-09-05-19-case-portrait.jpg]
case, portrait

SIGN? $69 to atg.eth in front of the site

## 2026-09-05 — provisioning from the wallet, and the repo goes public-ready

`atecc.py` grew `write_config`, `lock_config` and `genkey_new`, so a fresh chip can be locked
and given a key from the app's Setup page without a Pi. Both are gated by `ALLOW_LOCK` /
`ALLOW_GENKEY` in `secrets.py` on the device, default off; with them off the wallet refuses the
commands (checked on the real chip). The lock and new-key paths have NOT yet run on a fresh chip;
the config bytes and command sequence are the ones the Pi signer used successfully on 2026-09-04.

Photos: feet cropped or dropped, files renamed by content, five good shots added. README rewritten
as the build guide: order, print, assemble, flash, set up the chip, run, change it.

Then 69 USDS to atg.eth, same way: [`0x87638ae1…`](https://etherscan.io/tx/0x87638ae169eccb9f002d4eb6ce8b60e7d6603e4d3d4e562164ea10e9023f9313). That is the one in the tweet.

the details page, joystick down on the sign screen
v0 case on the printer

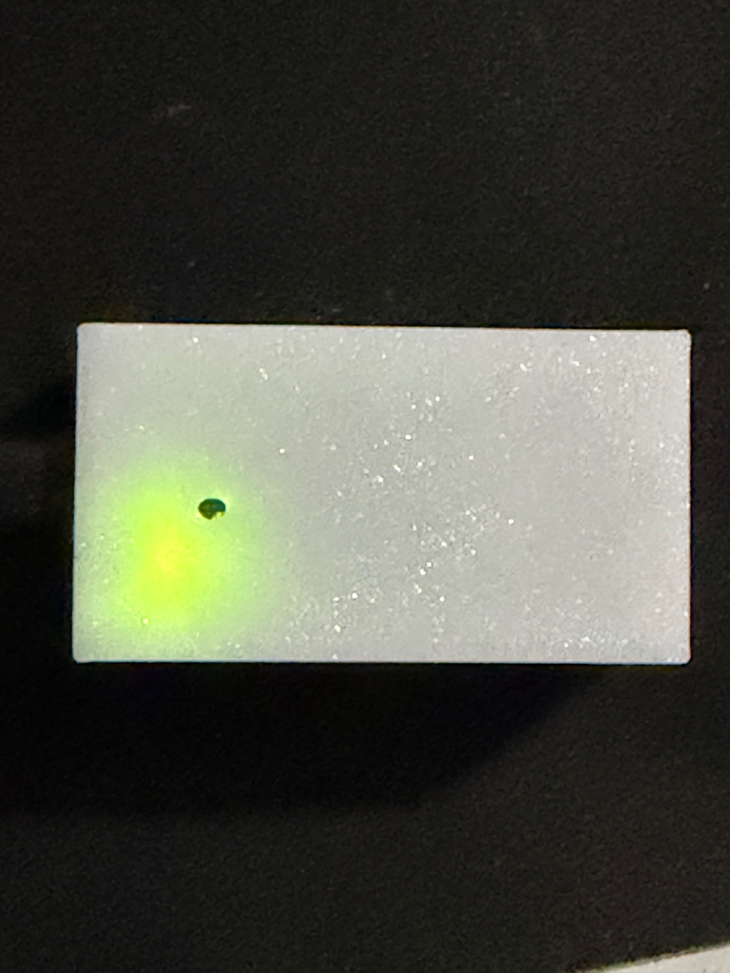
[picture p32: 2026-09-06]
buildlog/images/2026-09-05-10-v0-case-bottom-led-glow.jpg

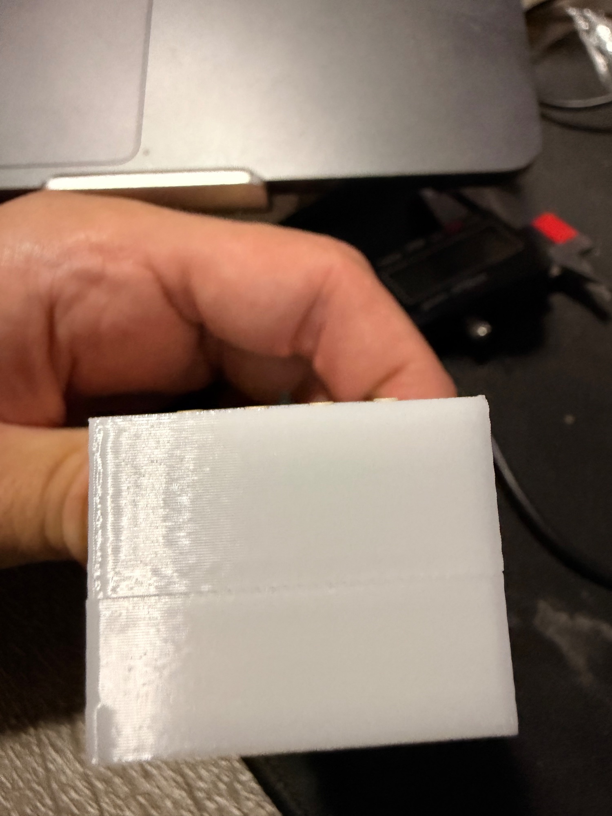
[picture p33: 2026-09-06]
buildlog/images/2026-09-05-16-v0-case-seam.jpg

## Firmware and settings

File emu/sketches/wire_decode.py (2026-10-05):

"""Device side: decode a wire-format eth-sign-request and render clear-signing screens.
Pure Python, no deps beyond cbor/rlp (and p256 for signature checks). Runs on MicroPython.

    rows = render(request_bytes, root=(qx, qy))   -> [(depth, label, text), ...]
"""
import binascii
try:
    import hashlib
except ImportError:
    import uhashlib as hashlib
import cbor, rlp
try:
    import p256
except ImportError:
    p256 = None

def hx(b):
    return "0x" + binascii.hexlify(b).decode()

def short(b):
    h = binascii.hexlify(b).decode()
    return "0x" + h[:6] + ".." + h[-4:]

class Bad(Exception):
    pass

# ---------------------------------------------------------------- signatures
def verify_struct(items, root):
    """items = decoded struct incl. trailing signature. Root = (qx, qy) ints or None to skip."""
    if root is None:
        return True
    body = b"".join(cbor.encode(x) for x in items[:-1])
    sig = items[-1]
    if not p256 or len(sig) != 64:
        return False
    r, s = int.from_bytes(sig[:32], "big"), int.from_bytes(sig[32:], "big")
    return p256.verify(root[0], root[1], hashlib.sha256(body).digest(), r, s)

# ---------------------------------------------------------------- path walking
def _rd(data, off):
    if off + 32 > len(data):
        raise Bad("path runs past calldata")
    return int.from_bytes(data[off:off + 32], "big")

def resolve(elems, data):
    """Walk DATA_PATH elements over ABI-encoded args (calldata without selector).
    Returns a list of values (bytes); more than one when an ARRAY element iterates."""
    out = []
    def walk(i, cur, base):
        if i == len(elems):
            raise Bad("path without leaf")
        e = elems[i]
        k = e[0]
        if k == 0:                                   # TUPLE: move n slots
            walk(i + 1, cur + 32 * e[1], base)
        elif k == 2:                                 # REF: read offset, relative to block start
            off = _rd(data, cur)
            walk(i + 1, base + off, base + off)
        elif k == 1:                                 # ARRAY
            n = _rd(data, cur)
            area = cur + 32
            ae = e[1]
            w, a, b = (1, None, None) if ae is None else (ae[0], ae[1], ae[2])
            a = 0 if a is None else (a if a >= 0 else n + a)
            b = n if b is None else (b if b >= 0 else n + b)
            if n > 64:
                raise Bad("array too long")
            for j in range(a, min(b, n)):
                walk(i + 1, area + j * w * 32, area)
        elif k == 3:                                 # LEAF
            lt = e[1]
            if lt == 3:
                v = data[cur:cur + 32]
                if len(v) < 32: raise Bad("static leaf past end")
            elif lt == 4:
                n = _rd(data, cur)
                v = data[cur + 32:cur + 32 + n]
                if len(v) < n: raise Bad("dynamic leaf past end")
            else:
                v = data[cur:]                       # tuple/array leaf: rest of block (toy)
            if i + 1 < len(elems) and elems[i + 1][0] == 4:
                a, b = elems[i + 1][1]
                v = v[a:b] if a is not None else v[:b]
            out.append(v)
        else:
            raise Bad("path element %r" % k)
    walk(0, 0, 0)
    return out

def get(value, ctx):
    """VALUE = [family, size, source] -> list of raw byte values."""
    fam, size, src = value
    if src[0] == 0:
        vals = resolve(src[1], ctx["args"])
    elif src[0] == 1:
        c = src[1]
        vals = [ctx["from"] if c == 0 else ctx["to"] if c == 1 else ctx["value"] if c == 2 else ctx["chain_id"]]
    elif src[0] == 2:
        vals = [src[1]]
    else:
        raise Bad("map-ref not implemented")
    # trim static 32-byte words: address = last 20 bytes, bytesN = first N bytes
    if fam == 5:
        vals = [v[-20:] if len(v) == 32 else v for v in vals]
    elif fam == 7 and size and size < 32:
        vals = [v[:size] if len(v) == 32 else v for v in vals]
    return vals

def as_int(v):
    return int.from_bytes(v, "big")

# ---------------------------------------------------------------- formatting
def fmt_decimal(n, decimals):
    s = str(n)
    if decimals == 0:
        return s
    if len(s) < decimals + 1:
        s = "0" * (decimals + 1 - len(s)) + s
    ip, fp = s[:-decimals], s[-decimals:].rstrip("0")
    return ip + ("." + fp if fp else "")

def token_decimals(req, chain_id, addr):
    for ti in req.get(8, []):
        if ti[1] == chain_id and ti[2] == addr:
            return ti[3]
    return None

def trusted(req, chain_id, addr, sources):
    for tn in req.get(10, []):
        if tn[2] == chain_id and tn[3] == addr and tn[1] in sources:
            return tn[4]
    return None

def find_info(req, chain_id, to, sel):
    for ti in req.get(13, []):
        if ti[1] == chain_id and ti[2] == to and ti[3] == sel:
            return ti
    return None

def render_field(req, field, ctx, rows, depth, root):
    label, param, visible, sep = field
    kind = param[0]
    if kind in (0, 1, 2, 3, 4, 5, 6, 8, 11):
        vals = get(param[1], ctx)
    if kind == 0:                                     # raw
        fam = param[1][0]
        for v in vals:
            if fam == 5: t = hx(v)
            elif fam in (1, 6): t = str(as_int(v))
            elif fam == 8: t = v.decode()
            else: t = hx(v)
            rows.append((depth, label, t))
    elif kind == 1:                                   # amount (native)
        for v in vals:
            rows.append((depth, label, fmt_decimal(as_int(v), 18) + " ETH"))
    elif kind == 2:                                   # token amount
        _, value, token, native, thr, msg = param
        toks = get(token, ctx) if token else [None]
        for i, v in enumerate(vals):
            tok = toks[i] if len(toks) == len(vals) else toks[0]
            n = as_int(v)
            if thr is not None and n >= thr:
                rows.append((depth, label, msg or "Unlimited")); continue
            if tok is None or tok in native:
                rows.append((depth, label, fmt_decimal(n, 18) + " ETH")); continue
            dec = token_decimals(req, ctx["chain_id"], tok)
            if dec is None:
                rows.append((depth, label, str(n) + " units of " + short(tok) + " (unknown token)"))
            else:
                rows.append((depth, label, fmt_decimal(n, dec) + " " + short(tok)))
    elif kind == 8:                                   # trusted name
        _, value, types, sources, senders, vt = param
        for v in vals:
            name = trusted(req, ctx["chain_id"], v, sources)
            rows.append((depth, label, (name + " (" + short(v) + ")") if name else hx(v)))
    elif kind == 4:
        for v in vals:
            rows.append((depth, label, str(as_int(v)) + (" (unix time)" if param[2] == 0 else " (block)")))
    elif kind == 5:
        for v in vals:
            rows.append((depth, label, str(as_int(v)) + " s"))
    elif kind == 6:
        _, value, base, dec, prefix = param
        for v in vals:
            rows.append((depth, label, fmt_decimal(as_int(v), dec or 0) + " " + base))
    elif kind == 9:                                   # nested calldata
        _, value, callee, chain, sel, amount, spender = param
        datas = get(value, ctx)
        callees = get(callee, ctx)
        amounts = get(amount, ctx) if amount else None
        for i, d in enumerate(datas):
            to = callees[i] if len(callees) == len(datas) else callees[0]
            amt = None if amounts is None else (amounts[i] if len(amounts) == len(datas) else amounts[0])
            rows.append((depth, label, "#%d" % (i + 1)))
            sub = {"args": d[4:], "from": ctx["from"], "to": to, "value": amt or b"", "chain_id": ctx["chain_id"]}
            info = find_info(req, ctx["chain_id"], to, d[:4])
            if info is None:
                rows.append((depth + 1, "Unknown call to", hx(to)))
                rows.append((depth + 1, "Selector", hx(d[:4])))
                rows.append((depth + 1, "Calldata", "%d bytes" % len(d)))
            else:
                render_info(req, info, sub, rows, depth + 1, root)
            if amt and as_int(amt):
                rows.append((depth + 1, "Value", fmt_decimal(as_int(amt), 18) + " ETH"))
    elif kind == 12:                                  # group
        for f in param[2]:
            render_field(req, f, ctx, rows, depth, root)
    else:
        rows.append((depth, label, "<param type %d not rendered>" % kind))

def render_info(req, info, ctx, rows, depth, root):
    ok = verify_struct(info, root)
    rows.append((depth, "Review", info[4] + ("" if ok else "  [BAD SIGNATURE]")))
    if not ok:
        rows.append((depth, "Contract", hx(ctx["to"])))
        rows.append((depth, "Calldata", "%d bytes (blind)" % (len(ctx["args"]) + 4)))
        return
    if info[5]: rows.append((depth, "From", info[5]))
    if info[7]: rows.append((depth, "Site", info[7]))
    for f in info[10]:
        render_field(req, f, ctx, rows, depth, root)

def render(b, root=None):
    req = cbor.decode(b)
    tx = rlp.decode_tx(req[2])
    if 4 in req and req[4] != tx["chain_id"]:
        raise Bad("envelope chain-id != tx chain-id")
    data = tx["data"]
    rows = [(0, "Chain", str(tx["chain_id"])), (0, "Nonce", str(tx["nonce"]))]
    ctx = {"args": data[4:], "from": req.get(6, b""), "to": tx["to"],
           "value": tx["value"].to_bytes(32, "big"), "chain_id": tx["chain_id"]}
    # signed side data: check every struct, drop the bad ones
    for key in (8, 10):
        if key in req:
            req[key] = [s for s in req[key] if verify_struct(s, root)]
    info = find_info(req, tx["chain_id"], tx["to"], data[:4]) if len(data) >= 4 else None
    if info is None:
        rows.append((0, "To", hx(tx["to"])))
        rows.append((0, "Value", fmt_decimal(tx["value"], 18) + " ETH"))
        rows.append((0, "Calldata", "%d bytes (blind)" % len(data)))
    else:
        render_info(req, info, ctx, rows, 0, root)
        if tx["value"]:
            rows.append((0, "Value", fmt_decimal(tx["value"], 18) + " ETH"))
    return rows

def show(rows):
    for depth, label, text in rows:
        print("  " * depth + label + ": " + text)

if __name__ == "__main__":
    import sys, json, os
    sys.path.insert(0, os.path.expanduser("~/picowallet/firmware"))
    import p256
    root = None
    try:
        r = json.load(open("out/root.json")); root = (int(r["qx"], 16), int(r["qy"], 16))
    except Exception:
        pass
    for name in sys.argv[1:] or ["out/usds-transfer.cbor", "out/batch.cbor"]:
        print("==", name, "root of trust:", "on" if root else "off")
        show(render(open(name, "rb").read(), root))

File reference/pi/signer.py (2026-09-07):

#!/usr/bin/env python3
"""
ATECC608 meta-transaction signer.

The chip holds a NIST P-256 key that owns the ChipAccount contract. This script:

  1. announces the chip's public key to the app  (POST /api/device)
  2. polls the app for transfers waiting for a signature (GET /api/requests?status=pending)
  3. signs the 32-byte EIP-712 digest with the chip (atcab_sign, or a software key in --mock mode)
  4. posts the signature back; the app's relay pays gas and settles it onchain
  5. runs setup jobs queued from the app's /setup page (status, genkey, lock-config)

Usage:
  python3 signer.py pubkey [--mock]                       print the signer public key
  python3 signer.py sign --digest 0x... [--mock]          sign one digest (used by the Foundry tests via ffi)
  python3 signer.py run --app http://<mac-ip>:3000        daemon: announce, poll, sign, repeat
      [--mock] [--confirm | --button 17] [--name "pi-atecc608"] [--once] [--allow-lock]

Hardware options: --i2c-bus 1  --i2c-addr 0x60 (7-bit, 0x35 for TrustFLEX/TNG parts)  --slot 0

Fresh chip? A blank ATECC608 refuses GenKey and Sign (error 0xF4) until its CONFIG zone is locked,
once, permanently. The DATA zone is left unlocked so GenKey can be re-run. README.md in this folder
walks through it with the real outputs.
"""
import argparse
import json
import os
import sys
import time

P256_N = 0xFFFFFFFF00000000FFFFFFFFFFFFFFFFBCE6FAADA7179E84F3B9CAC2FC632551
HERE = os.path.dirname(os.path.abspath(__file__))
MOCK_KEY_FILE = os.path.join(HERE, ".mock_key.pem")


def hexbytes(s: str, length: int) -> bytes:
    s = s[2:] if s.startswith("0x") else s
    b = bytes.fromhex(s)
    if len(b) != length:
        raise ValueError(f"expected {length} bytes, got {len(b)}")
    return b


def low_s(r: int, s: int):
    """Ethereum-side verifiers (OpenZeppelin P256) reject high-s signatures. (r, N-s) is equally valid."""
    if s > P256_N // 2:
        s = P256_N - s
    return r, s


# ----------------------------------------------------------------------------- backends


class SoftSigner:
    """Software P-256 key. Lets the whole pipeline run before the chip is wired up."""

    name = "mock"

    def __init__(self, key_hex=None):
        from cryptography.hazmat.primitives import serialization
        from cryptography.hazmat.primitives.asymmetric import ec

        if key_hex:
            self.key = ec.derive_private_key(int(key_hex, 16), ec.SECP256R1())
        elif os.path.exists(MOCK_KEY_FILE):
            with open(MOCK_KEY_FILE, "rb") as f:
                self.key = serialization.load_pem_private_key(f.read(), password=None)
        else:
            self.key = ec.generate_private_key(ec.SECP256R1())
            pem = self.key.private_bytes(
                serialization.Encoding.PEM,
                serialization.PrivateFormat.PKCS8,
                serialization.NoEncryption(),
            )
            with open(MOCK_KEY_FILE, "wb") as f:
                f.write(pem)
            os.chmod(MOCK_KEY_FILE, 0o600)
            print(f"[mock] generated software key -> {MOCK_KEY_FILE}", file=sys.stderr)

    def pubkey(self) -> bytes:
        n = self.key.public_key().public_numbers()
        return n.x.to_bytes(32, "big") + n.y.to_bytes(32, "big")

    def status(self) -> dict:
        return {"configLocked": True, "dataLocked": False, "slot": 0, "hasKey": True, "note": "software key (mock)"}

    def genkey(self) -> bytes:
        from cryptography.hazmat.primitives import serialization
        from cryptography.hazmat.primitives.asymmetric import ec

        self.key = ec.generate_private_key(ec.SECP256R1())
        with open(MOCK_KEY_FILE, "wb") as f:
            f.write(self.key.private_bytes(serialization.Encoding.PEM, serialization.PrivateFormat.PKCS8, serialization.NoEncryption()))
        return self.pubkey()

    def lock_config(self) -> str:
        return "mock signer: nothing to lock"

    def sign_digest(self, digest: bytes):
        from cryptography.hazmat.primitives import hashes
        from cryptography.hazmat.primitives.asymmetric import ec
        from cryptography.hazmat.primitives.asymmetric.utils import Prehashed, decode_dss_signature

        der = self.key.sign(digest, ec.ECDSA(Prehashed(hashes.SHA256())))
        return low_s(*decode_dss_signature(der))


class AteccSigner:
    """ATECC608 over I2C via Microchip's cryptoauthlib python bindings (pip install cryptoauthlib).

    Lock model used by this demo: the CONFIG zone must be locked once (the chip refuses GenKey/Sign
    otherwise). The DATA zone is left unlocked so GenKey can be re-run on the slot any time.
    """

    name = "atecc608"

    # Microchip's ATECC608 reference config (cryptoauthlib test/api_calib/test_calib_config.c).
    # Slot 0: P-256 private key, external sign enabled, GenKey allowed. Bytes 0-15 and 84-87 are
    # read-only and skipped by atcab_write_config_zone.
    CONFIG = bytes([
        0x01, 0x23, 0x00, 0x00, 0x00, 0x00, 0x60, 0x00, 0x04, 0x05, 0x06, 0x07, 0xEE, 0x01, 0x01, 0x00,
        0xC0, 0x00, 0xA1, 0x00, 0xAF, 0x2F, 0xC4, 0x44, 0x87, 0x20, 0xC4, 0xF4, 0x8F, 0x0F, 0x0F, 0x0F,
        0x9F, 0x8F, 0x83, 0x64, 0xC4, 0x44, 0xC4, 0x64, 0x0F, 0x0F, 0x0F, 0x0F, 0x0F, 0x0F, 0x0F, 0x0F,
        0x0F, 0x0F, 0x0F, 0x0F, 0xFF, 0xFF, 0xFF, 0xFF, 0x00, 0x00, 0x00, 0x00, 0xFF, 0xFF, 0xFF, 0xFF,
        0x00, 0x00, 0x00, 0x00, 0xFF, 0x84, 0x03, 0xBC, 0x09, 0x69, 0x76, 0x00, 0x00, 0x00, 0x00, 0x00,
        0x00, 0x00, 0x00, 0x00, 0x00, 0x00, 0x00, 0x00, 0xFF, 0xFF, 0x0E, 0x40, 0x00, 0x00, 0x00, 0x00,
        0x33, 0x00, 0x1C, 0x00, 0x13, 0x00, 0x1C, 0x00, 0x3C, 0x00, 0x3A, 0x10, 0x1C, 0x00, 0x33, 0x00,
        0x1C, 0x00, 0x1C, 0x00, 0x38, 0x00, 0x30, 0x00, 0x3C, 0x00, 0x3C, 0x00, 0x32, 0x00, 0x30, 0x00,
    ])

    # zone ids for atcab_is_locked / atcab_lock_* (atca_basic.h)
    LOCK_ZONE_CONFIG = 0x00
    LOCK_ZONE_DATA = 0x01

    def __init__(self, bus=1, addr7=0x60, slot=0):
        import cryptoauthlib as cal
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

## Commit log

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2026-09-06 fork ATECC608-demo app; Pico signer: p256, keccak, eip712, atecc driver, wallet loop
2026-09-06 wallet: single timer (scheduler queue fix), trace log; buildlog: chip on the wallet, photos; pico tool retries
    [wallet.py]
2026-09-06 case: v0 STL (Tomáš Plass, CC BY-NC) and notes
    [waveshare-13-pico-lcd-case-tomas-plass.stl]
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2026-09-06 case: cap and joystick research, SeedSigner reference parts, design plan
    [open_pill_mini_w_coverplate_Buttons.stl, open_pill_mini_w_coverplate_Lid.stl, open_pill_mini_w_coverplate_Thumbstick_PLA.stl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]
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2026-09-06 console: poll-accept + timer paused during HTTP (mainnet latency wedged it); app: 5 s chain-read cache; home screen v2
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2026-09-06 case: CadQuery generator, first caps + joystick dome (vertical dims still guesses)
    [caps_x4_clear0.15.stl, caps_x4_clear0.25.stl, joystick_dome.stl]
2026-09-06 case: cap geometry in a lid-face frame, pocket or post depending on the plunger height
2026-09-06 case: buildable guess values for the sample caps
    [caps_x4_clear0.15.stl, caps_x4_clear0.25.stl]
2026-09-06 case: press-fit keycaps for the v0 lid (plungers sit flush, no room for a flange); v1 floating caps kept for the taller lid
    [joystick_dome.stl, keycaps_x4_pocket1.95.stl, keycaps_x4_pocket2.05.stl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]
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2026-09-06 README rewrite: what it is, the three parts, no-solder assembly, firmware, app, screens; plan status
2026-09-06 README as a build guide: order, print, assemble, flash, set up the chip, run, change it
2026-09-06 chip provisioning from the Setup page (lock config, new key), gated by flags on the device; README step 5
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2026-09-07 case: measured caps, hat and lid cuts (v06), stopped; pitch was 5.17 by guess, about 5.58 for real
    [v06_caps_x4.stl, v06_joystick_hat.stl, v06_lid.stl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]
2026-09-07 contract v5: no admin, fixed recovery with a 14-day delay, signed calls, ENS reverse name; mainnet 0x4564fA63, audited; SECURITY.md; app refuses legacy v1; drop the Alchemy key from the tree; HANDOFF
    [v0_base.stl]
2026-09-08 HANDOFF: the Pico is a serial port over USB, not a drive; mpremote works over USB or WiFi
2026-09-09 case: Zez0000 remix with button caps and joystick cap (MakerWorld 3230142), dropped in the print inbox
    [base.stl, button_cap_1.stl, button_cap_2.stl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]
2026-09-09 case: zez0000 base_v2, snap ridge cut to four short 0.25 mm ridges with clearance; tools/zezbase
    [base_v2.stl]
2026-09-09 case: zez0000 base_v3 adds a pry notch; full set queued in yellow
    [base_v2.stl, base_v3.stl]
2026-09-09 HANDOFF: Zez0000 case with caps, base_v3 snap rework, yellow set queued
2026-09-10 case: zez0000 base_v4, Pico posts 5.5 -> 3 mm, base 2.5 mm shorter; PLA fit check dropped
    [base_v4.stl]
2026-09-11 case: zez0000 joystick_cap_v2, stem socket 1.95 -> 2.05 mm; tools/zezcap
    [joystick_cap_v2.stl]
2026-09-11 case: zez0000 joystick_cap_v3, chamfered socket mouth and pyramid roof, 2.05 and 2.15 sizes
    [joystick_cap_v3_2.05.stl, joystick_cap_v3_2.15.stl]
2026-09-11 case: zez0000 joystick caps 1.95 and 2.00, button cap with a raised X; tools/zezbtn
    [button_cap_x.stl, joystick_cap_v3_1.95.stl, joystick_cap_v3_2.00.stl]
2026-09-11 case: zez0000 button cap with a raised check mark; tools/zezbtn takes x|check
    [button_cap_check.stl, button_cap_x.stl]
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2026-09-11 case: zez0000 lid_v2, button holes 0.6 mm toward the screen and 0.05 mm bigger; tools/zezlid
    [lid_v2.stl]
2026-09-11 firmware: keytest.py, on-screen button test for a bare Pico + LCD hat
2026-09-11 case: zez0000 lid_v3, button holes 0.3 mm bigger per side; tools/zezlid takes v2|v3
    [lid_v3.stl]
2026-09-11 case: zez0000 lid_v4, button holes 0.15 mm bigger per side than v2
    [lid_v4.stl]
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2026-09-11 firmware: mock.py, nine fake wallet screens for photos on the bare Pico; tools/shot pulls them as PNGs
2026-09-11 case: zez0000 base_v5, snap ridges 0.50 mm proud, r 0.5; tools/zezbase takes v4|v5
    [base_v5.stl]
2026-09-11 emu: virtual Pico wallet. MicroPython wasm runs the firmware unchanged, machine/network/requests shims, the case STLs in 3D with clickable caps, keyboard on the buttons, tools/emu run/key/shot/exec C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
2026-09-11 case: base_v5_qr, white QR code inlaid in the bottom 3 layers of the black base for an AMS two-colour test; tools/zezqr builds the black/white bodies and a Bambu two-part 3MF and decodes the result; 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
    [base_v5_qr.3mf, base_v5_qr_black.stl, base_v5_qr_white.stl]
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2026-09-11 emu: keys are W A S D + space for the joystick, numpad 9 6 3 . for A B X Y; key labels next to each button in the 3D view
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2026-09-12 case: base_v5 too tight, base_v4 is the keeper; reprint drop
2026-09-12 case: official set is base_v4 + lid_v4 + stock caps + joystick_cap_v3_2.00
2026-09-12 emu: run acts on the module menu, menu lists only runnable modules, entry points for demo/wallet, busy-loop status, binary tabs never saved, tools/emu ship + send-to-Pico button
    - ▶ run / ↻ reset / ⇪ send use the picked module; Cmd/Ctrl+Enter runs the editor file
    - core/workspace.mjs isRunnable + ENTRY (demo.run(), wallet.start()); runtime.runCode shared snippet
    - worker posts started; page reports 'busy loop' when import never returns (demo)
    - fix: opening a .bin tab marked it dirty and save-all overwrote firmware/*.bin with placeholder text
    - core/ship.mjs: mpremote over /dev/cu.usbmodem* (or --wifi), copies lcd.py if missing, follows 4 s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
2026-09-12 emu ship: soft-reset the USB Pico before import so the old module's timer stops; stop() the old copy on wifi
2026-09-12 emu: device picker for every board on USB, bootloader drives detected, flash MicroPython from the page or tools/emu flash, ship --port
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2026-09-12 emu page: restore shot button, keyboard, and view switch lost in the device picker patch
2026-09-12 ship copies every file a module imports; wallet runs without secrets.py and shows NO CHIP / no wifi / no secrets on screen
    - emu/core/ship.mjs: dependencies() walks import lines and "x.bin" names in firmware/ + sketches, copies them all (mpremote skips unchanged), copy and run are separate mpremote calls so the 4 s output follow never cuts a copy short
    - firmware/net.py, wallet.py: secrets.py optional; wallet.start() joins WiFi itself when boot.py did not; home screen: NO CHIP top centre when the signer is the software key, big text no secrets.py / no wifi / connecting..., status bar names the missing piece
    [net.py, wallet.py]
2026-09-12 case: zez0000 base_v6, snap ridges 0.30 mm proud (v4 0.25, v5 0.50)
    [base_v6.stl]
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2026-09-12 wallet: no chip means no account; stop on a NO CHIP screen (A re-probes) unless secrets.ALLOW_SOFT_KEY, which the emulator sets
2026-09-12 case: zez0000 lid_v5, cap pocket 0.4 mm deeper so pressing the case does not click buttons
    [lid_v5.stl]
2026-09-13 case: official set is base_v6 + lid_v5 + stock caps + joystick_cap_v3_2.00; picowallet_case.stl has all seven parts on one plate; tools/zezplate
    [picowallet_case.stl]
2026-09-13 case: base_pink for the USB-C Pico (posts 9.5 mm apart, divot under the jack, 9.2 slot); tools/zezbase pink
    [base_pink.stl]
2026-09-13 case: base_pink fits; official base is base_v6 for Pico 2 W, base_pink for the pink USB-C Pico
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2026-09-13 case: lid_v6, cap pocket 0.6 mm (pink Pico still clicked a little on v5)
    [lid_v6.stl]
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

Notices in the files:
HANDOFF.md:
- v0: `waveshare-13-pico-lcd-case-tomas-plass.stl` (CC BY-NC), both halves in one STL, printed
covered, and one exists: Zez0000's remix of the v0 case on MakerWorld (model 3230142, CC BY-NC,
